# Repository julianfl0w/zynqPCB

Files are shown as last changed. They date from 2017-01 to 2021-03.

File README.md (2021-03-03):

# zynqPCB
An 8-layer board built upon Xilinx Zynq Chip. Includes sound output, HDMI, DDR3, USB Host, USB Device, a handful of sensors, and Arduino Uno style header for screen connection. See schematic in this repo "schematic.pdf"
  
## OPEN TO COLLABORATION!!

# Kicad Project
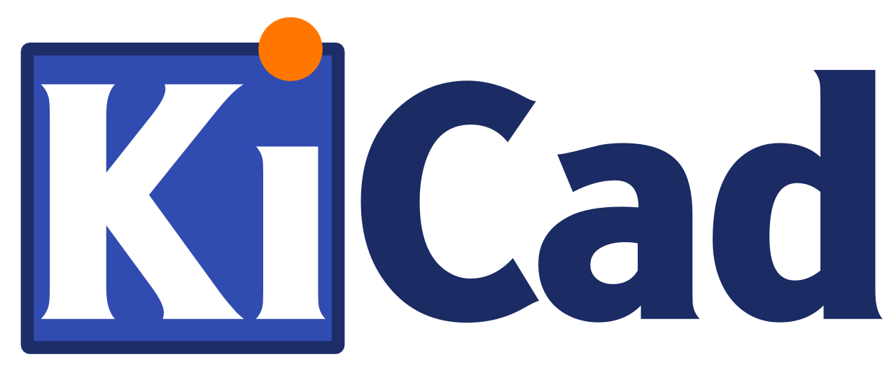
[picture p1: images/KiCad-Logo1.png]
  
https://kicad.org/  

# 3D Render
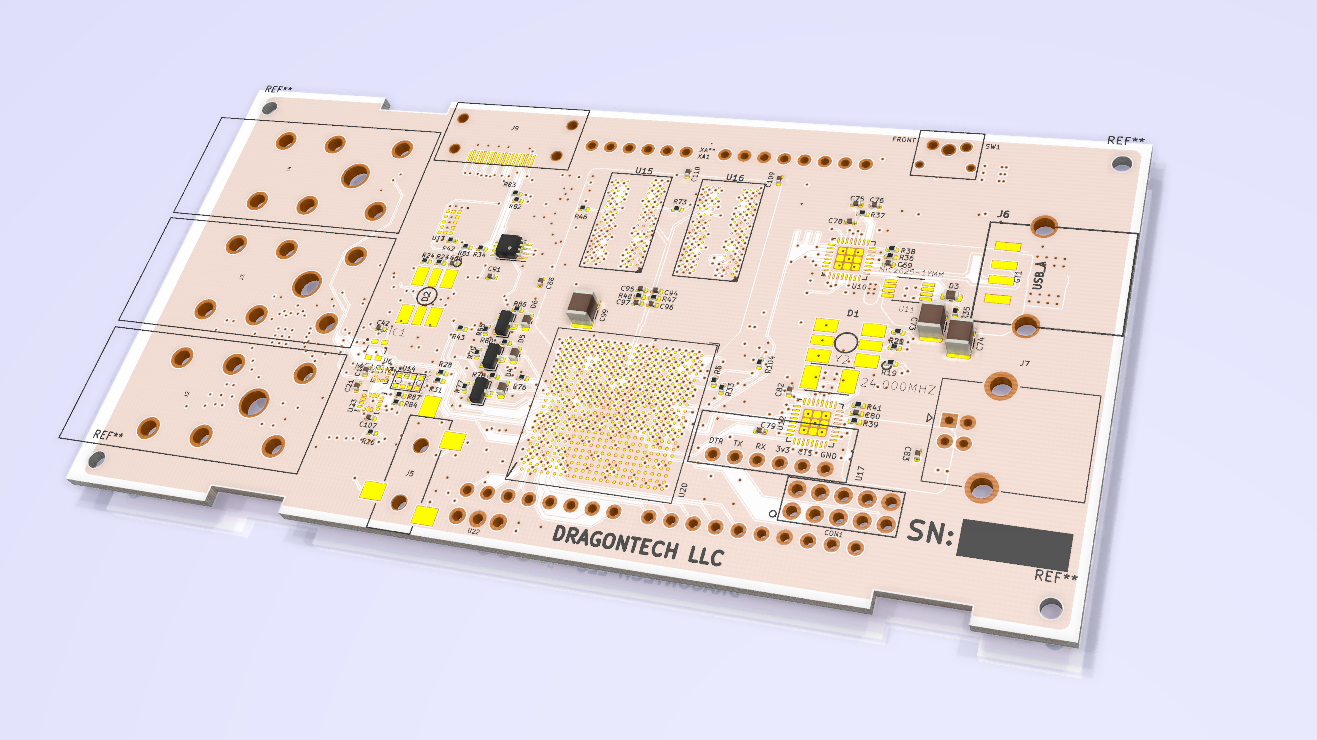
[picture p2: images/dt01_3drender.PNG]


# Layout
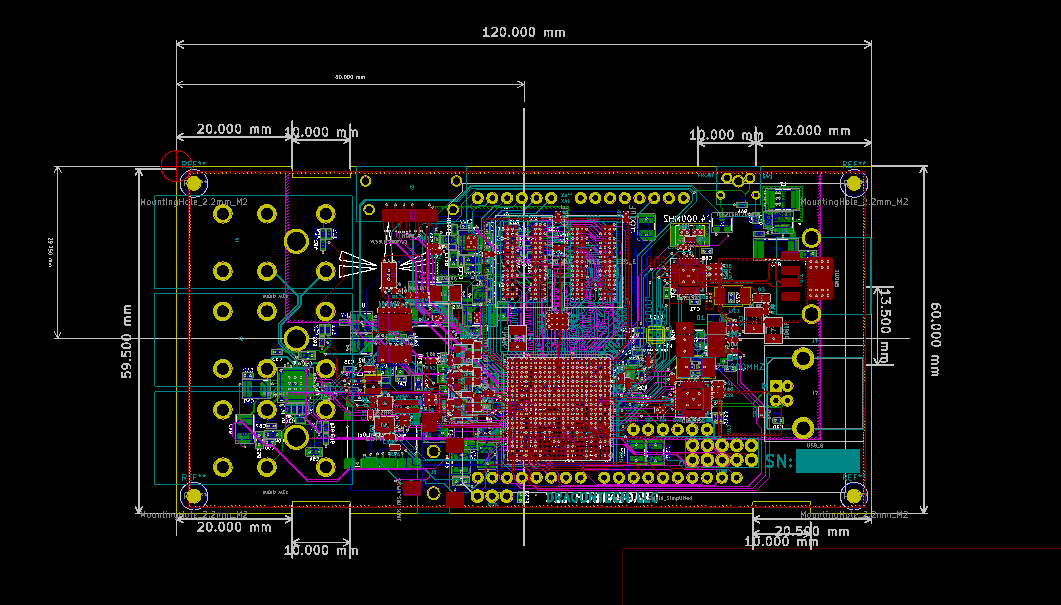
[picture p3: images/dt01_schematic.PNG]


# Block Diagram 
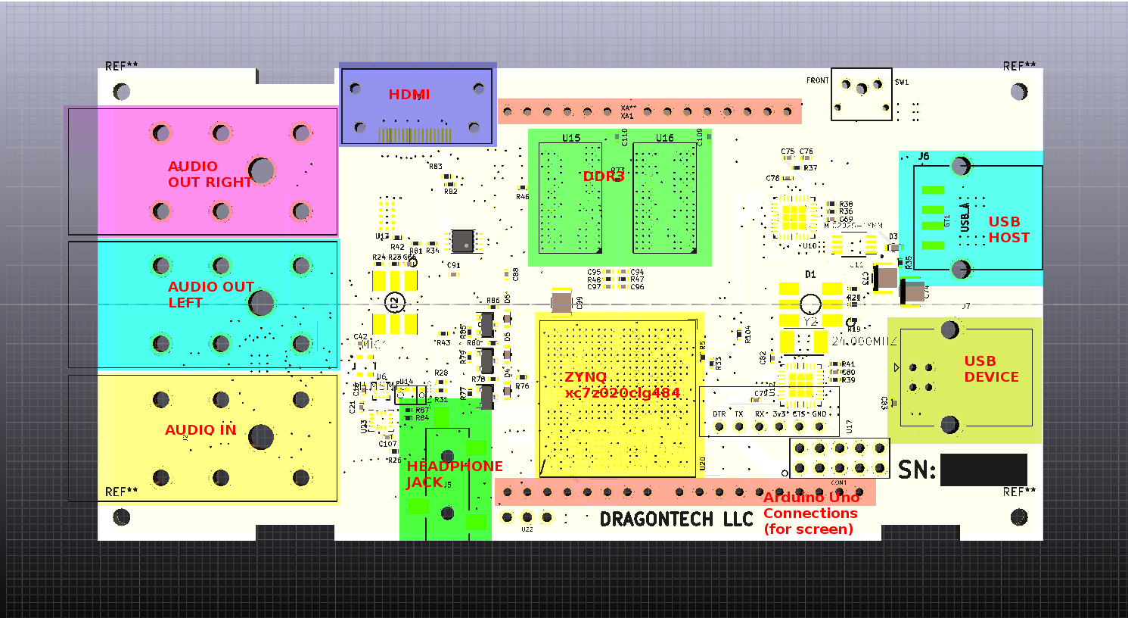
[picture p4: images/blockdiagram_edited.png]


# Manufactured PCB - Top
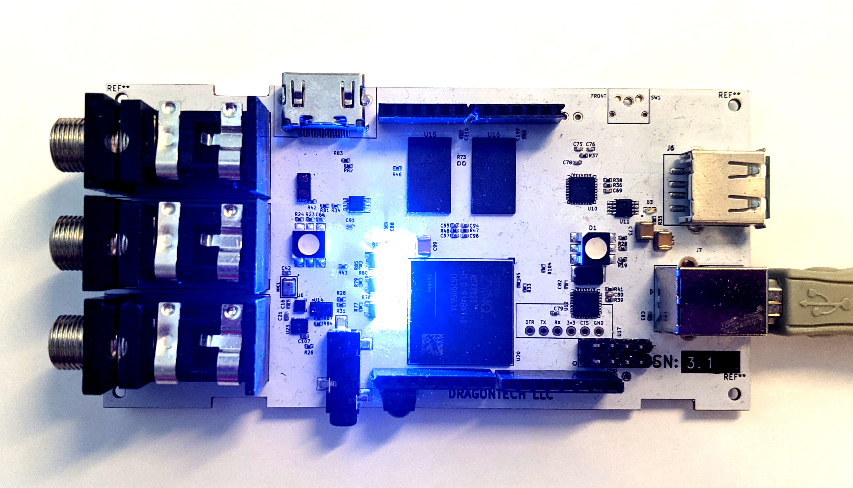
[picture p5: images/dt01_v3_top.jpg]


# Manufactured PCB - Bottom
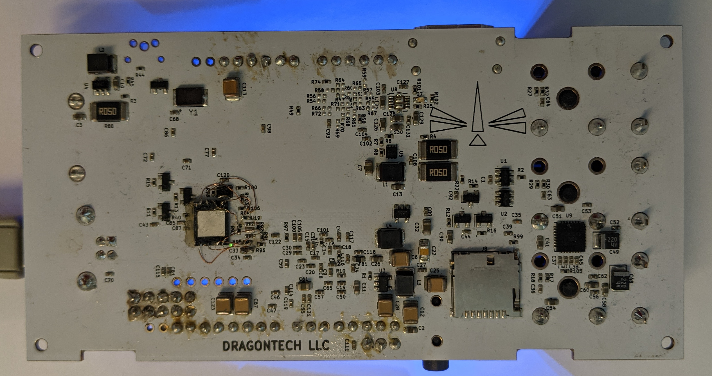
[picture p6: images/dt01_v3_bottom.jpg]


# Introduction  
Hi friends! This is the current status of my 4-year project to make an FPGA-accelerated audio+video synthesizer. I am currently taking a hiatus from this project, and have decided to make the entire PCB design available on Github! Quite a bit of work has been put into this project. The difficult tasks of part selection and routing have been taken care of. I am still testing the functionality of the board. Only one PCB problem has been found: the SPI Flash for Zynq Boot was the wrong footprint! This problem has since been fixed.  

I believe that together we can make this a formidable tool in the open hardware community.  

The following software projects need to be undertaken before this project is usable by the general public:
1. Development of Boot firmware for the SPI flash which loads the linux kernel from the SD card
2. Development of a basic shell block diagram in Vivado  
  
If you embark on one of these projects, please share your code here so other engineers don't have to reproduce your work :)  

# IMPORTANT: Make sure to clone the following into the same directory:
https://github.com/julianfl0w/footprints.pretty  
https://github.com/julianfl0w/lib  
  
## I make no guarantees as to device funtionality. Please review the board carefully before production. 
Specific hardware (from BOM)  
xc7z020clg484 (Zynq Chip)  
VL53L1CXV0FY/1 (rangefinder)  

# Interfaces:  
1. JTAG interface : Functional!
2. SPI Flash : Untested
3. VL53L1CXV0FY Rangefinder : Untested  
4. APDS-9960 Rangefinder : Untested 
5. LIS2HH12 Accelerometer : Untested 
6. LSM6DSLTR IMU  : Untested 
7. HDMI Out : Untested
8. USB Host : Untested
9. USB Device : Untested
10. DDR3 PS Memory : Untested
11. TLV320 Audio Codec : Untested
12. MicroSD card : Untested

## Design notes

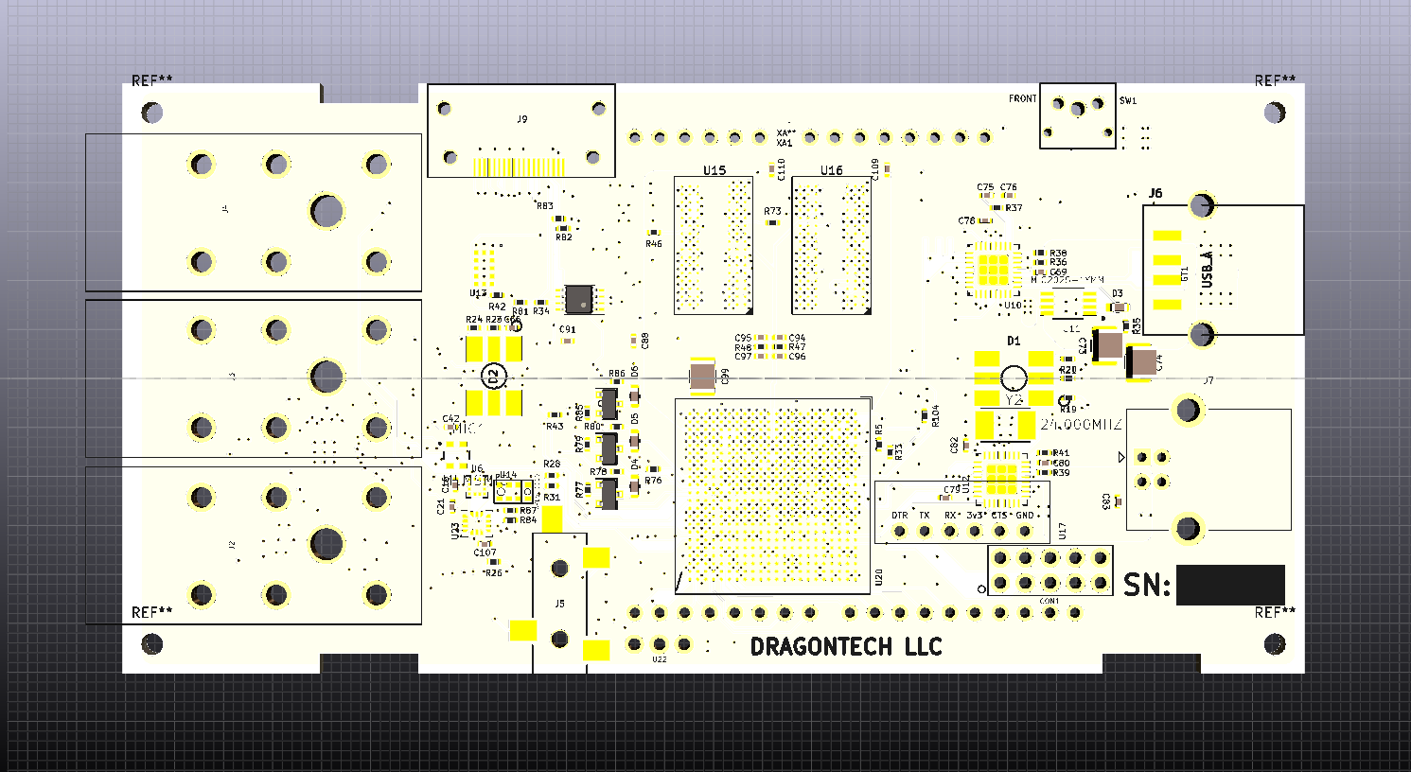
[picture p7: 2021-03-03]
images/blockdiagram.PNG

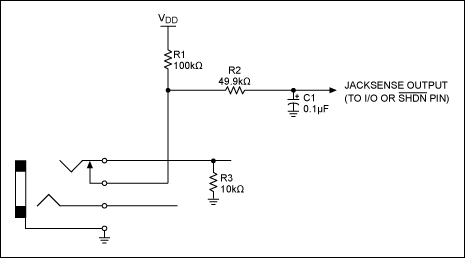
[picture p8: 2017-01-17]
docs/jackdetection.gif

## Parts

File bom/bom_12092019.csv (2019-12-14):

Refs | Value | Footprint | Quantity | MFR | MPN | SPR | SPN
Y1;Y2 | 24.000MHZ | ABM3-12.000MHZ-B2-T:XTAL500X320X130N | 2 | Abracon LLC | ABM3-24.000MHZ-D2Y-T | DigiKey | 535-10643-2-ND
C106;C105;C98;C93;C109;C110;C120;C111 | .01uF | Capacitor_SMD:C_0402_1005Metric | 8 | Murata | GRM155R71H103KA88J | Digikey | 490-6351-1-ND
C68;C70;C71;C77;C72;C79;C81;C82;C86;C131;C97;C96;C95;C94;C88;C16;C107;C36;C64;C63;C52;C56;C53;C62;C39 | .1uF | Capacitor_SMD:C_0402_1005Metric | 25 | Murata | GRM188R71C104KA01D | Digikey | 490-1532-1-ND
C65;C78;C87;C34;C18;C17;C15;C14;C29;C30;C31;C23;C8;C4;C1;C108;C116;C117;C118;C119;C104;C103;C102;C101;C121;C55;C50;C47;C46 | .47uF | Capacitor_SMD:C_0402_1005Metric | 29 | Murata | GRM188R71C474KA88D | Digikey | 490-3295-1-ND
C76;C75;C85;C84 | 18pF | Capacitor_SMD:C_0402_1005Metric | 4 | Murata | GCM1555C1H180JA16D | Digikey | 490-12650-1-ND
C91;C92;C37;C40;C38;C45;C43;C44 | 1uF | Capacitor_SMD:C_0402_1005Metric | 8 | Murata | GRM188R71C105KE15D | Digikey | 490-10734-1-ND
C69;C80;C35 | 2.2uF | Capacitor_SMD:C_0402_1005Metric | 3 | Murata | GRM155R61A225KE95D | Digikey | 490-10451-1-ND
C66;C83;C20;C19;C24;C27;C9;C5;C114;C115;C100;C127;C122;C89;C21;C42;C59;C57 | 4.7uF | Capacitor_SMD:C_0402_1005Metric | 18 | Murata | GRM21BR61A475KA73L | Digikey | 490-9750-1-ND
C3;C13;C2;C10;C11;C26;C33;C126;C125;C130;C129;C128;C90;C54;C58;C51;C41;C60 | 10uF | Capacitor_SMD:C_0603_1608Metric | 18 | Murata | GRM21BR61A106KE19L | Digikey | 490-1709-1-ND
FB1 | 120R, 100 MHz, size 0603 | Capacitor_SMD:C_0603_1608Metric | 1 | Murata Electronics | BLM18AG121SN1D | Digikey | 490-1011-1-ND
D3;D5;D4;D6;D7 | BLUE LED | Capacitor_SMD:C_0603_1608Metric | 5 | Vishay Semiconductors | VLMB1300-GS08 | Digikey | VLMB1300-GS08CT-ND
C32;C7;C61 | 47uF | Capacitor_SMD:C_0805_2012Metric | 3 | Murata Manufacturing Co Ltd | GRM32ER70J476ME20L | Digikey | 490-6542-1-ND
C22 | 330uF | Capacitor_SMD:C_1206_3216Metric | 1 | AVX Corporation | F950G337MAAAQ2 | Digikey | 478-8378-1-ND
C67;C73;C74;C28;C25;C12;C6;C99;C123 | 100uF | Capacitor_SMD:C_1210_3225Metric | 9 | TAIYO YUDEN | JMK325ABJ107MM-P | Digikey | 587-4313-1-ND
C113 | 47uF | Capacitor_SMD:C_1210_3225Metric | 1 | Murata Manufacturing Co Ltd | GRM32ER70J476ME20L | Digikey | 490-6542-1-ND
L2;L3;L4;L1 | 2.2uH | Capacitor_SMD:C_1812_4532Metric | 4 | Murata | LQH43PN2R2M26L | Digikey | 490-12049-1-ND
C49;C48 | 220uF Tant. | Capacitor_Tantalum_SMD:CP_EIA-3528-12_Kemet-T | 2 | AVX Corporation | F930G227KBA | Digikey | 478-8139-1-ND
J7 | USB_B | Connector_USB:USB_B_OST_USB-B1HSxx_Horizontal | 1 | On Shore Technology | USB-B1HSW6 | Digikey | ED2982-ND
J9 | HDMI_A | DFTcustom:10029449-111RLF | 1 | Amphenol ICC | 10029449-111RLF | Digikey | 609-4614-1-ND
J8 | Micro_SD_Card_Det | DFTcustom:AMPHENOL-114-00841-68 | 1 | Amphenol ICC | 114-00841-68 | Digikey | 114-00841-68-1-ND
U14 | APDS-9960 | DFTcustom:APDS_9960 | 1 | Broadcom Limited | APDS-9960 | Digikey | 516-3480-1-ND
XA1 | Arduino_Uno_Shield_Simplified | DFTcustom:Arduino_Uno_Shield_Simplified | 1 | DNS | - | - | -
U20 | xc7z020clg484 | DFTcustom:BGA-484_19.0x19.0mm_Layout22x22_P0.80mm_dia0.40mm | 1 | Xilinx | XC7Z020-1CLG484C | Digikey | 122-1850-ND
U15;U16 | MT41K256M16HA-125_E | DFTcustom:FBGA-96-DDR3-SDRAM | 2 | Micron | MT41K256M16TW-107 | Digikey | 557-2006-6-ND
U17 | FTDITypeUART | DFTcustom:FTDI_CONN | 1 | DNS | - | - | -
U22 | TSOP344 | DFTcustom:JUMPER_3PIN | 1 | Vishay Semiconductor | TSOP34438 | Digikey | TSOP34438-ND
U13 | VL53L1CXV0FY/1 | DFTcustom:Optical_LGA12 | 1 | STMicroelectronics | VL53L1CXV0FY/1 | Digikey | 497-17764-2-ND
D1;D2 | LED_RGB | DFTcustom:PLCC6-SM-RGB-LED | 2 | Cree, Inc. | CLP6C-FKB-CM1Q1H1BB7R3R3 | Digikey | CLP6C-FKB-CM1Q1H1BB7R3R3CT-ND
J4;J3;J2 | AUDIO JACK | DFTcustom:RA49C14B | 3 | Switchcraft Conxall | RA49C12B | Digikey | SC2083-ND
J5 | JACK_TRS_4PINS | DFTcustom:SJ-352X-SMT | 1 | CUI Inc. | SJ-3524-SMT-TR | Digikey | CP-3524SJCT-ND
J6 | USB_A | DFTcustom:USB-A-Receptacle-FCI_87583 | 1 | Amphenol ICC | 87583-2010RLF | Digikey | 609-5390-1-ND
MIC1 | MEMSMIC | DFTcustom:WM7121PE | 1 | Cirrus Logic | WM7121PIMSE/RV | Digikey | WM7121PIMSE/RVCT-ND
U19 | S25FL256SAGNFI001 | DFTcustom:WSON-8 | 1 | Cypress | S25FL256SAGNFI001 | Digikey | 1274-1005-ND
CON1 | AVR-JTAG-10 | DFTcustom:XilinxJTAG | 1 | DNS
GT1 | GNDTIE | DFTcustom:gndtie | 1 | DNS | - | - | -
SW1 | TL6215RF200BDT | DFTcustom:tl6215_right_angle | 1 | E-Switch Inc | TL6215RF200BDT | Digikey | EG5162-ND
U10;U12 | USB3320 | Package_DFN_QFN:QFN-32-1EP_5x5mm_P0.5mm_EP3.1x3.1mm | 2 | Microchip Technology | USB3320C-EZK-TR | Digikey | USB3320C-EZK-CT-NDs
U9 | TLV320AIC3104 | Package_DFN_QFN:QFN-32-1EP_5x5mm_P0.5mm_EP3.65x3.65mm | 1 | Texas Instruments | TLV320AIC3104IRHBR | Digikey | 296-26818-1-ND
U6 | LIS2HH12 | Package_LGA:LGA-12_2x2mm_P0.5mm | 1 | STMicroelectronics | LIS2HH12TR | Digikey | 497-15069-1-ND
U23 | LSM6DS3 | Package_LGA:LGA-14_3x2.5mm_P0.5mm_LayoutBorder3x4y | 1 | STMicroelectronics | LSM6DS3TR | Digikey | 497-15383-1-ND
U21 | PCA9306 | Package_SO:SSOP-8_2.95x2.8mm_P0.65mm | 1 | Texas Instruments | PCA9306DCTR | Digikey | 296-18509-2-ND
U8 | TPS51200DRCR | Package_SON:VSON-10-1EP_3x3mm_P0.5mm_EP1.65x2.4mm_ThermalVias | 1 | Texas Instruments | TPS51200DRCR | Digikey | 296-26978-1-ND
U5 | TLV62080DSGx | Package_SON:WSON-8-1EP_2x2mm_P0.5mm_EP0.9x1.6mm | 1 | Texas Instruments | TLV62080DSGR | Digikey | 296-39270-6-ND
Q9;Q8;Q10;Q7;Q5;Q3;Q1;Q6;Q4;Q2 | IRLML2502 | Package_TO_SOT_SMD:SOT-23 | 10 | Infineon Technologies AG | IRLML2502TRPBF | Digikey | IRLML2502PBFCT-ND
U3 | SC189 - 1.0V | Package_TO_SOT_SMD:SOT-23-5 | 1 | Semtech Corporation | SC189ASKTRT | Digikey | SC189ASKCT-ND
U7 | SC189 - 1.8V | Package_TO_SOT_SMD:SOT-23-5 | 1 | Semtech Corporation | SC189LSKTRT | Digikey | SC189LSKCT-ND
U4 | SC189 - 3.3V | Package_TO_SOT_SMD:SOT-23-5 | 1 | Semtech Corporation | SC189ZSKTRT | Digikey | SC189ZSKCT-ND
U1;U2 | LM3880 | Package_TO_SOT_SMD:SOT-23-6 | 2 | Texas Instruments | LM3880MF-1AE/NOPB | Digikey | LM3880MF-1AE/NOPBDKR-ND
R19;R20;R15;R13;R11;R22;R23;R16;R14;R12 | 100 | Resistor_SMD:R_0402_1005Metric | 10 | Yageo | RC0402FR-07100RL | Digikey | 311-100LRCT-ND
R1;R2;R3;R4;R5;R34;R81;R101;R27;R29;R17;R28 | 100k | Resistor_SMD:R_0402_1005Metric | 12 | Yageo | RC0402FR-07100KL | Digikey | 311-100KLRTR-ND
R36;R39;R33;R6;R42;R43;R44 | 10k | Resistor_SMD:R_0402_1005Metric | 7 | Yageo | RC0402FR-0710KL | Digikey | 311-10.0KLRTR-ND
R48;R47 | 10k 1% | Resistor_SMD:R_0402_1005Metric | 2 | Yageo | RC0402FR-0710KL | Digikey | 311-10.0KLRCT-ND
R35;R80;R78;R86;R102;R45;R21;R24 | 150 | Resistor_SMD:R_0402_1005Metric | 8 | Yageo | RC0402FR-07150RL | Digikey | 311-150LRTR-ND
R37;R40 | 1M | Resistor_SMD:R_0402_1005Metric | 2 | Yageo | RC0402FR-071ML | Digikey | 311-1.00MLRCT-ND
R79;R77;R85;R105 | 1k | Resistor_SMD:R_0402_1005Metric | 4 | Yageo | RC0402FR-071KL | Digikey | 311-1.00KLRCT-ND
R25;R96;R97;R95;R91;R92;R93;R94;R106 | 20k | Resistor_SMD:R_0402_1005Metric | 9 | Yageo | RT0402BRD0720KL | Digikey | YAG1388CT-ND
R100 | 24.9 1% | Resistor_SMD:R_0402_1005Metric | 1 | Yageo | RC0402FR-0724K9L | Digikey | 311-24.9KLRTR-ND
R7;R49;R46 | 240 1% | Resistor_SMD:R_0402_1005Metric | 3 | Yageo | RC0402FR-07240RL | Digikey | 311-240LRTR-ND
R9;R10;R8;R82;R83;R74;R98;R103;R104 | 4.7k | Resistor_SMD:R_0402_1005Metric | 9 | Yageo | RC0402JR-074K7L | Digikey | 311-4.7KJRCT-ND
R52;R51;R54;R53;R56;R55;R58;R57;R60;R59;R62;R61;R64;R63;R66;R65;R67;R68;R69;R70;R71;R72;R73 | 40.2 1% | Resistor_SMD:R_0402_1005Metric | 23 | Yageo | RC0402FR-0740R2L | Digikey | 311-40.2LRTR-ND
R26;R84;R87 | 47 | Resistor_SMD:R_0402_1005Metric | 3 | Yageo | RC0402JR-0747RL | Digikey | 311-47JRTR-ND
R99 | 47k | Resistor_SMD:R_0402_1005Metric | 1 | Yageo | RC0402FR-0747KL | Digikey | 311-47.0KLRTR-ND
R32;R30;R18;R31 | 49.9k | Resistor_SMD:R_0402_1005Metric | 4 | Yageo | RC0402FR-0749K9L | Digikey | 311-49.9KLRCT-ND
R38;R41 | 8.06k 1% | Resistor_SMD:R_0402_1005Metric | 2 | Yageo | RC0402FR-078K06L | Digikey | 311-8.06KLRTR-ND
R50;R75;R76 | 80.6 1% | Resistor_SMD:R_0402_1005Metric | 3 | Yageo | RC0402FR-0780R6L | Digikey | 311-80.6LRTR-ND
R90;R88;R89 | .05 | Resistor_SMD:R_2512_6332Metric | 3 | Bourns Inc | CRA2512-FZ-R050ELF | Digikey | CRA2512-FZ-R050ELFCT-ND
U11 | MIC2025-1YMM | SOP65P490X110-8N:SOP65P490X110-8N | 1 | Microchip | MIC2025-1YMM-TR | Digikey | MIC2025-1YMM-CT-ND
U18 | ABRACON-ASDMB | XTAL_ASDMB-24.000MHZ-LC-T:XTAL_ASDMB-24.000MHZ-LC-T | 1 | Abracon LLC | ASDMB-24.000MHZ-LC-T | Digikey | 535-11728-1-ND

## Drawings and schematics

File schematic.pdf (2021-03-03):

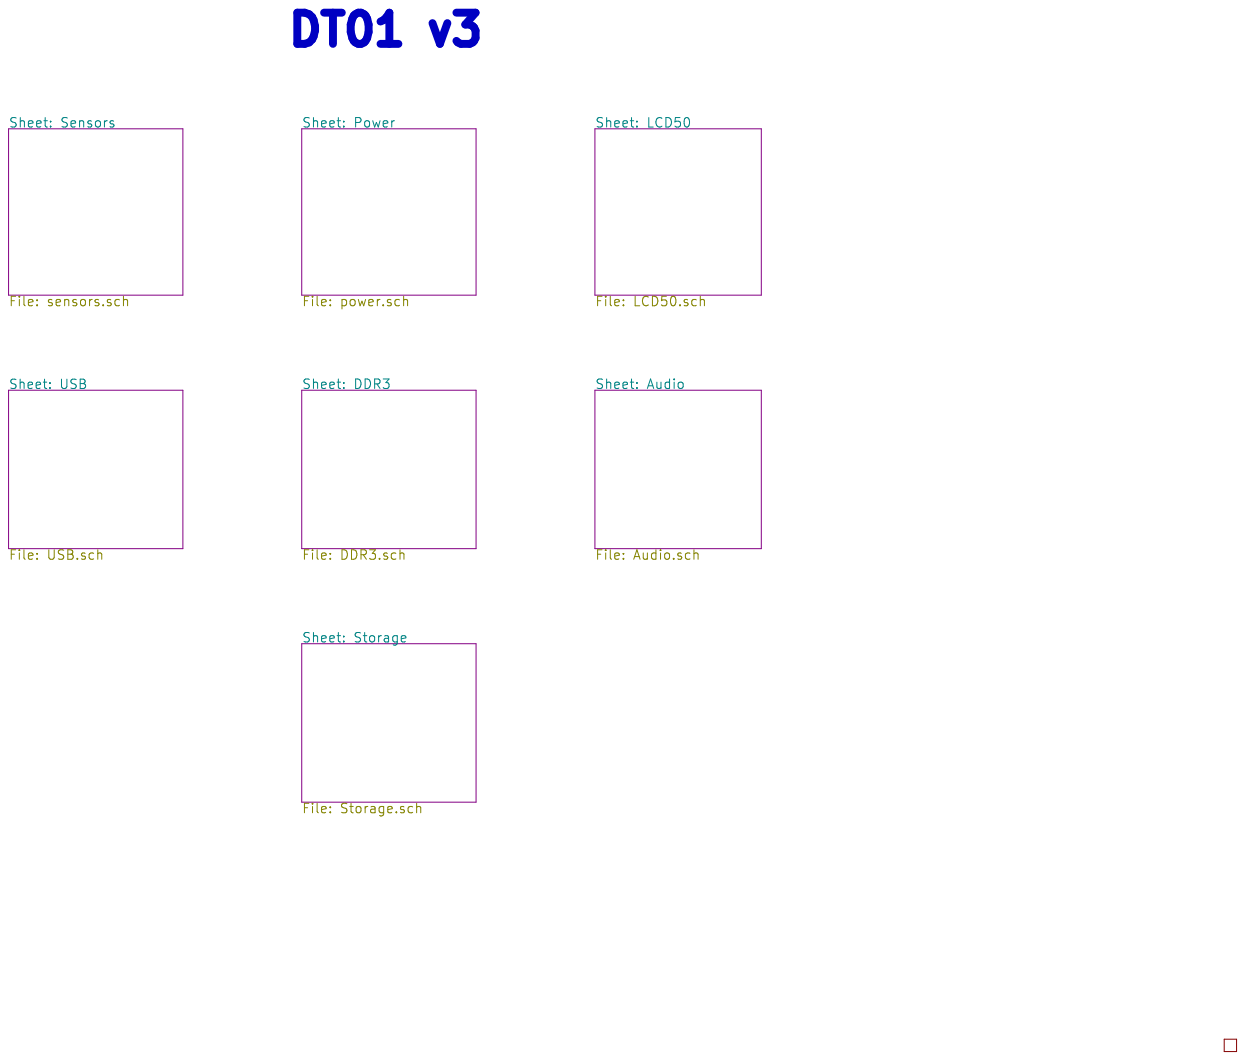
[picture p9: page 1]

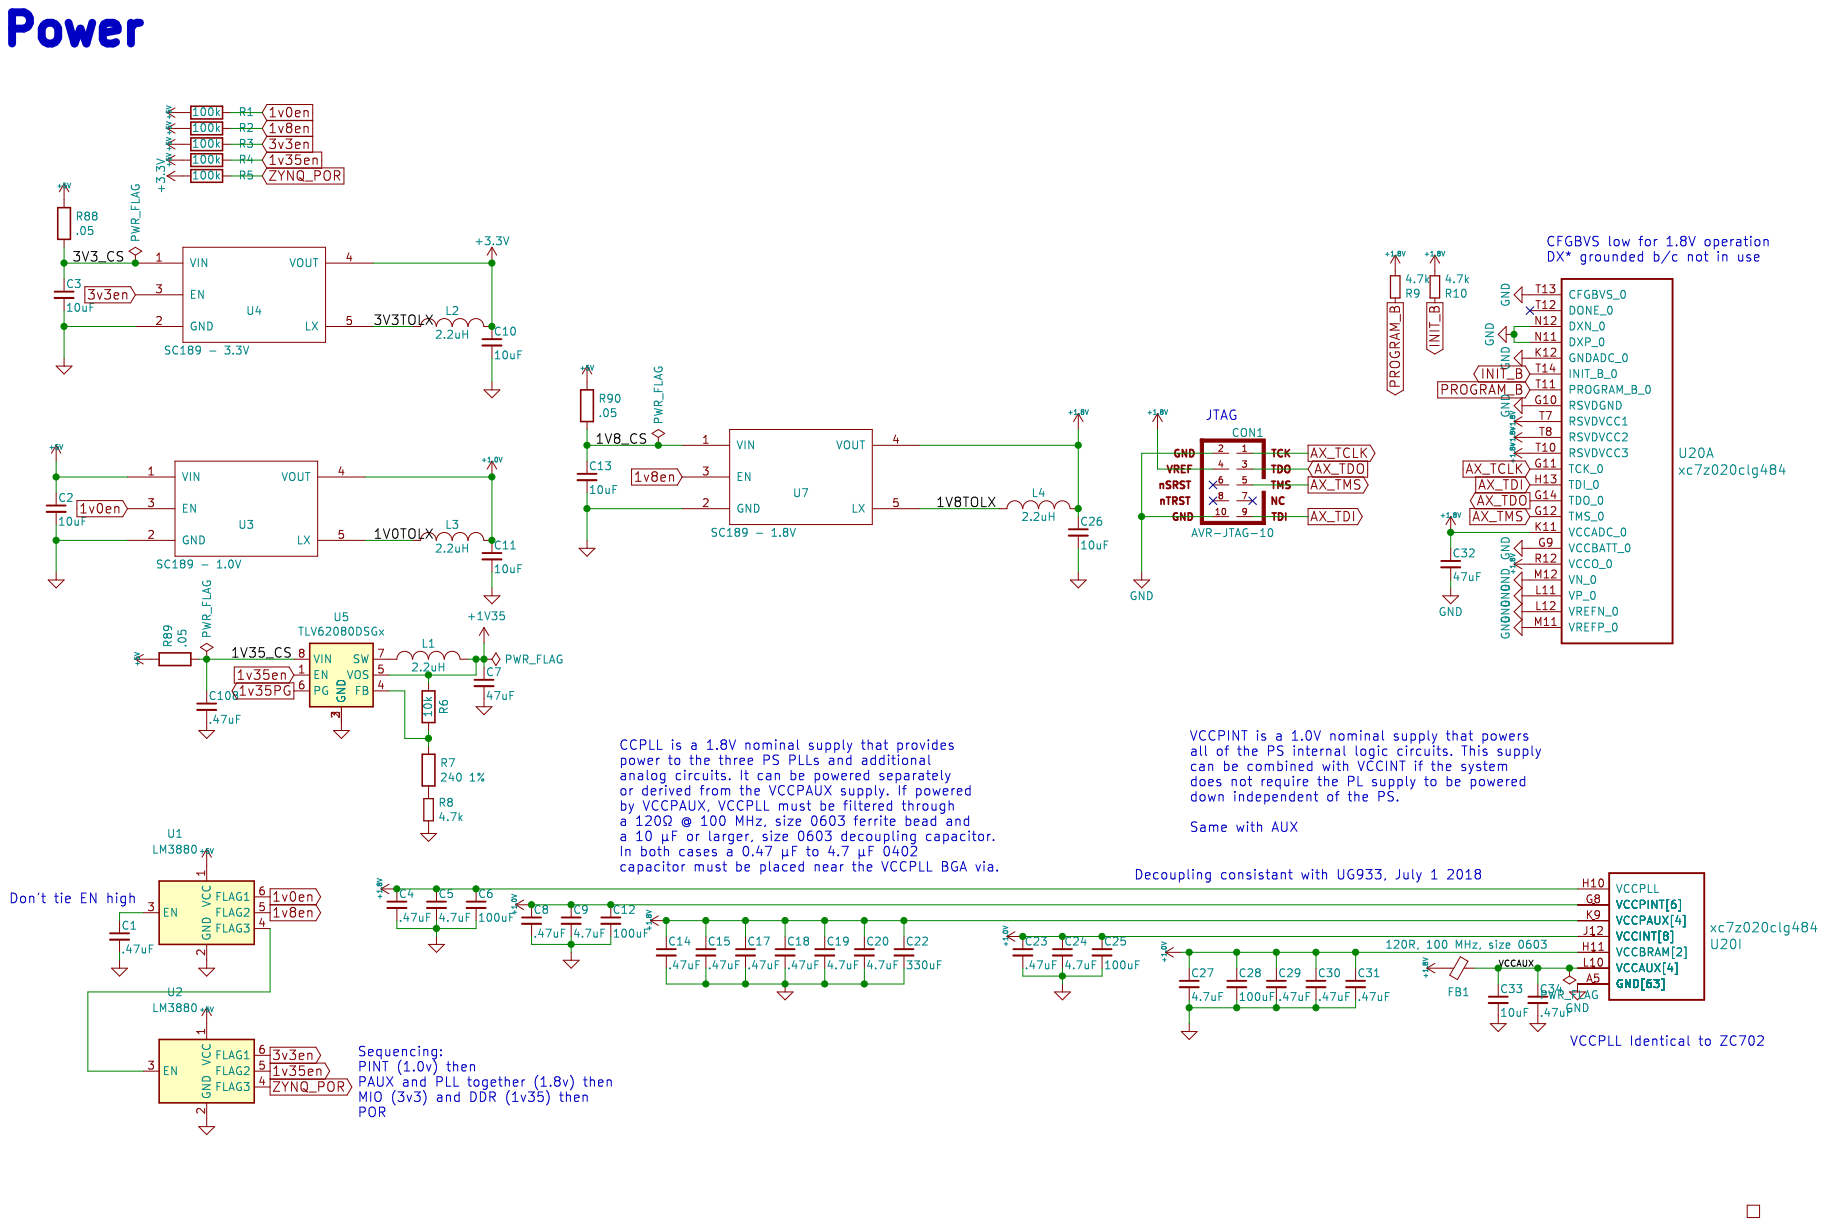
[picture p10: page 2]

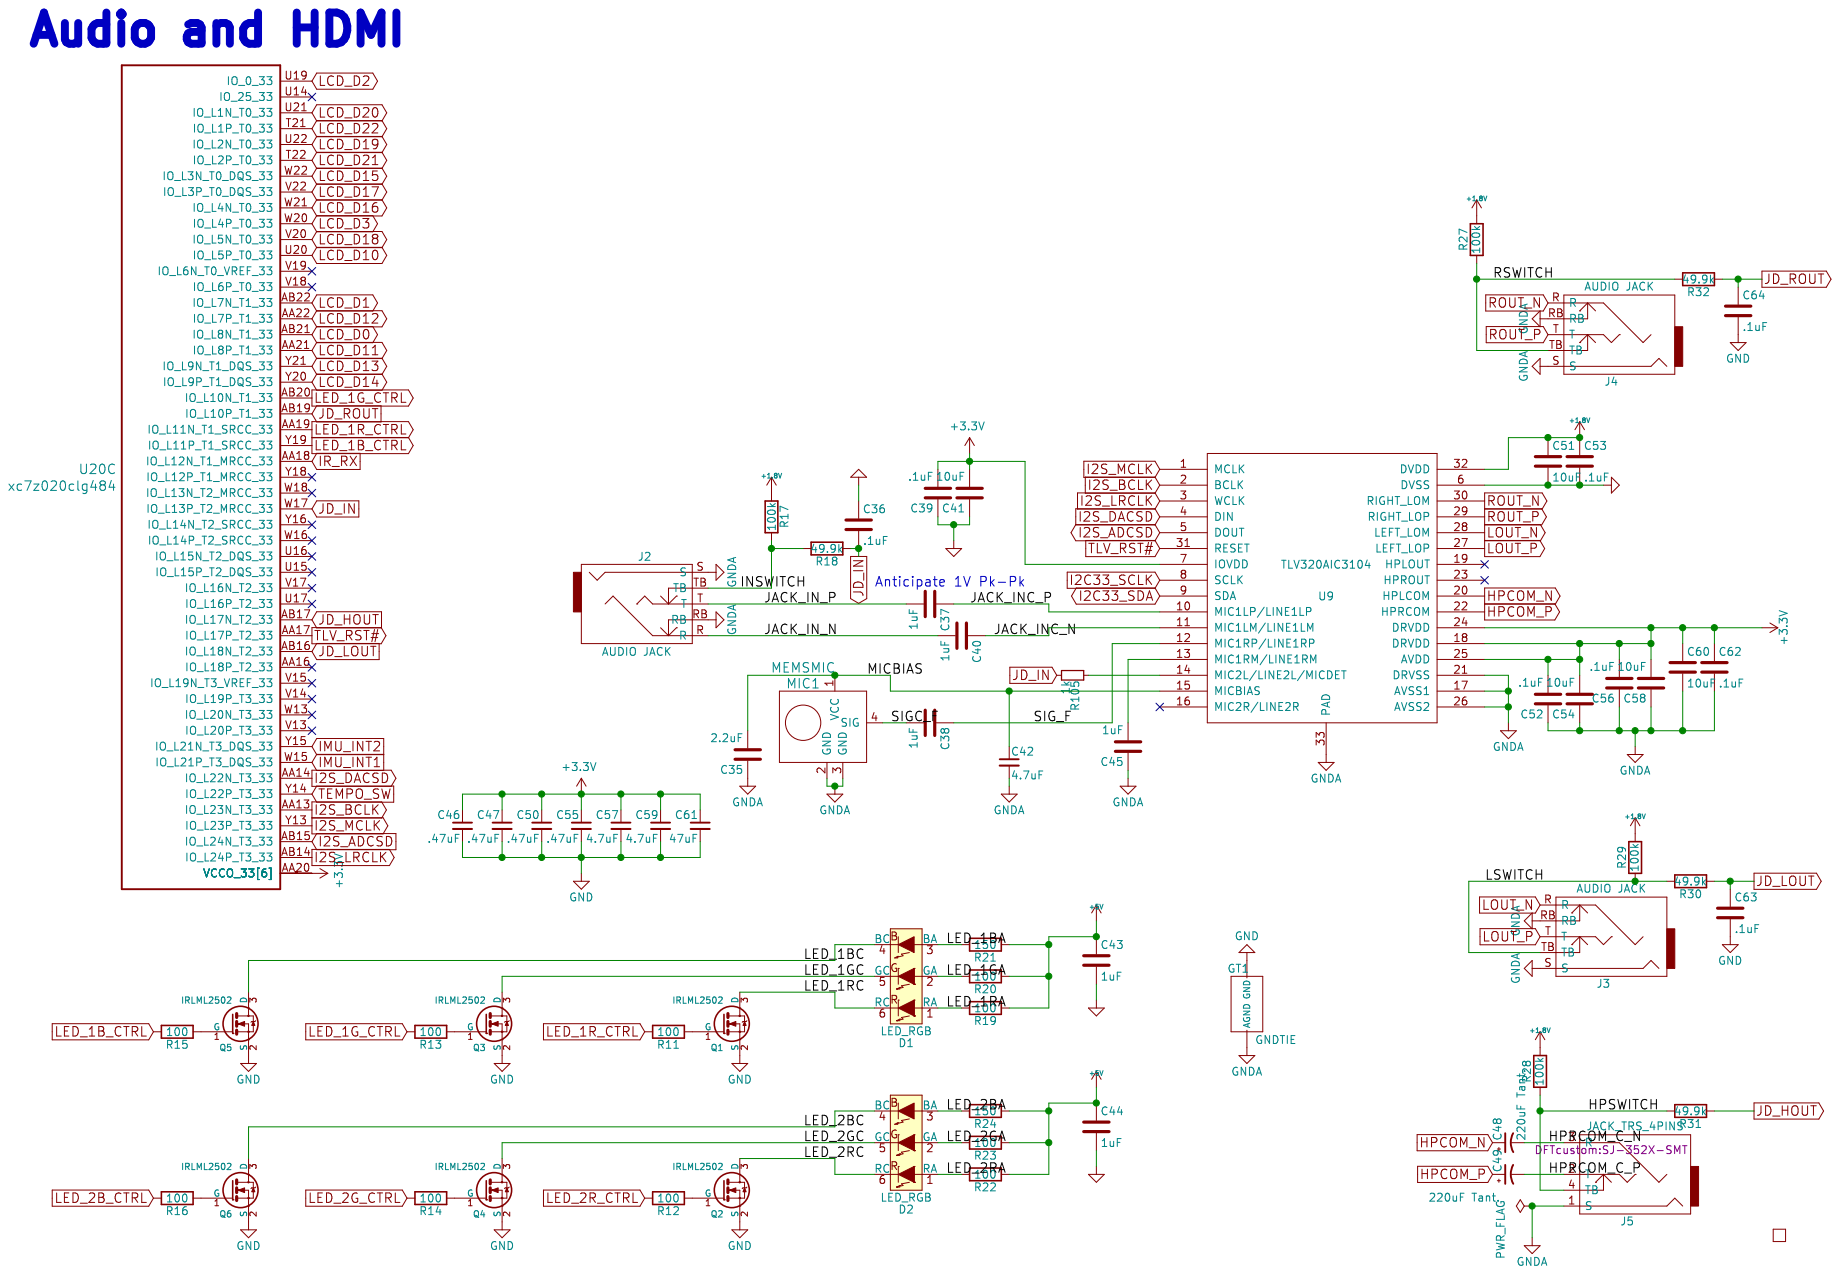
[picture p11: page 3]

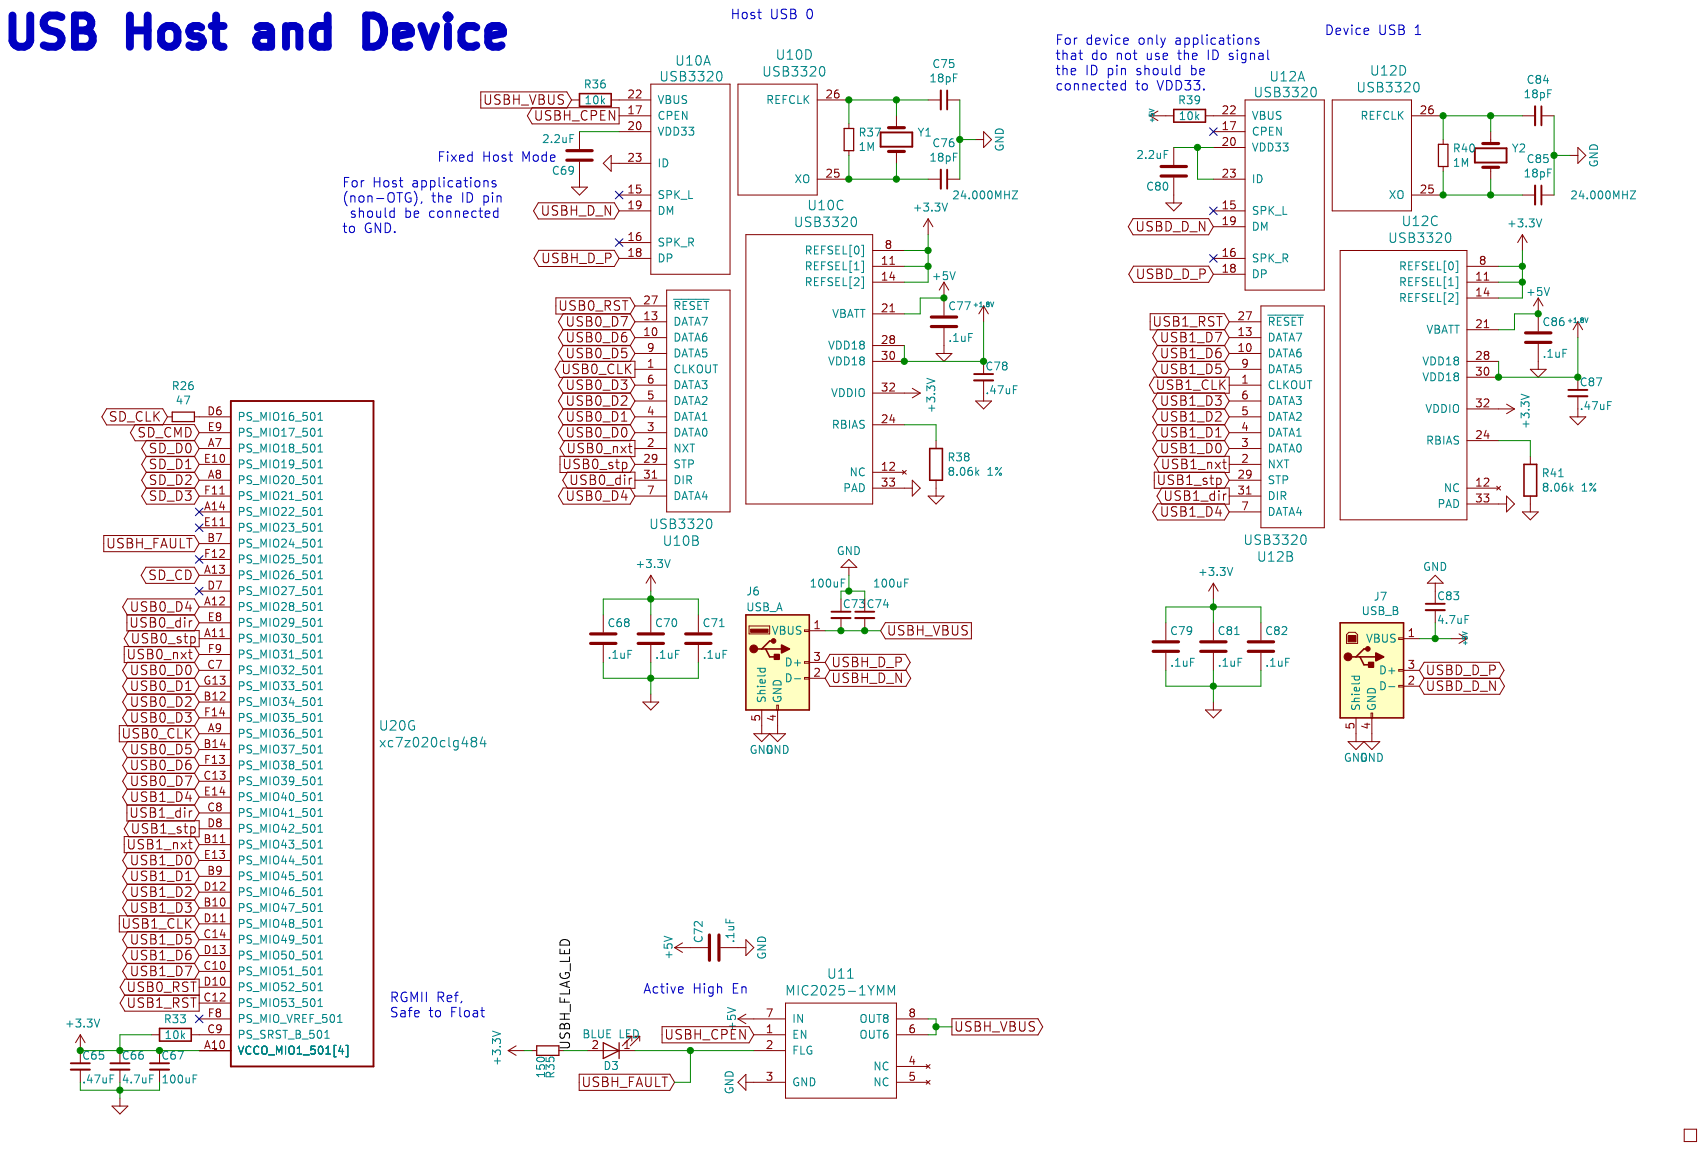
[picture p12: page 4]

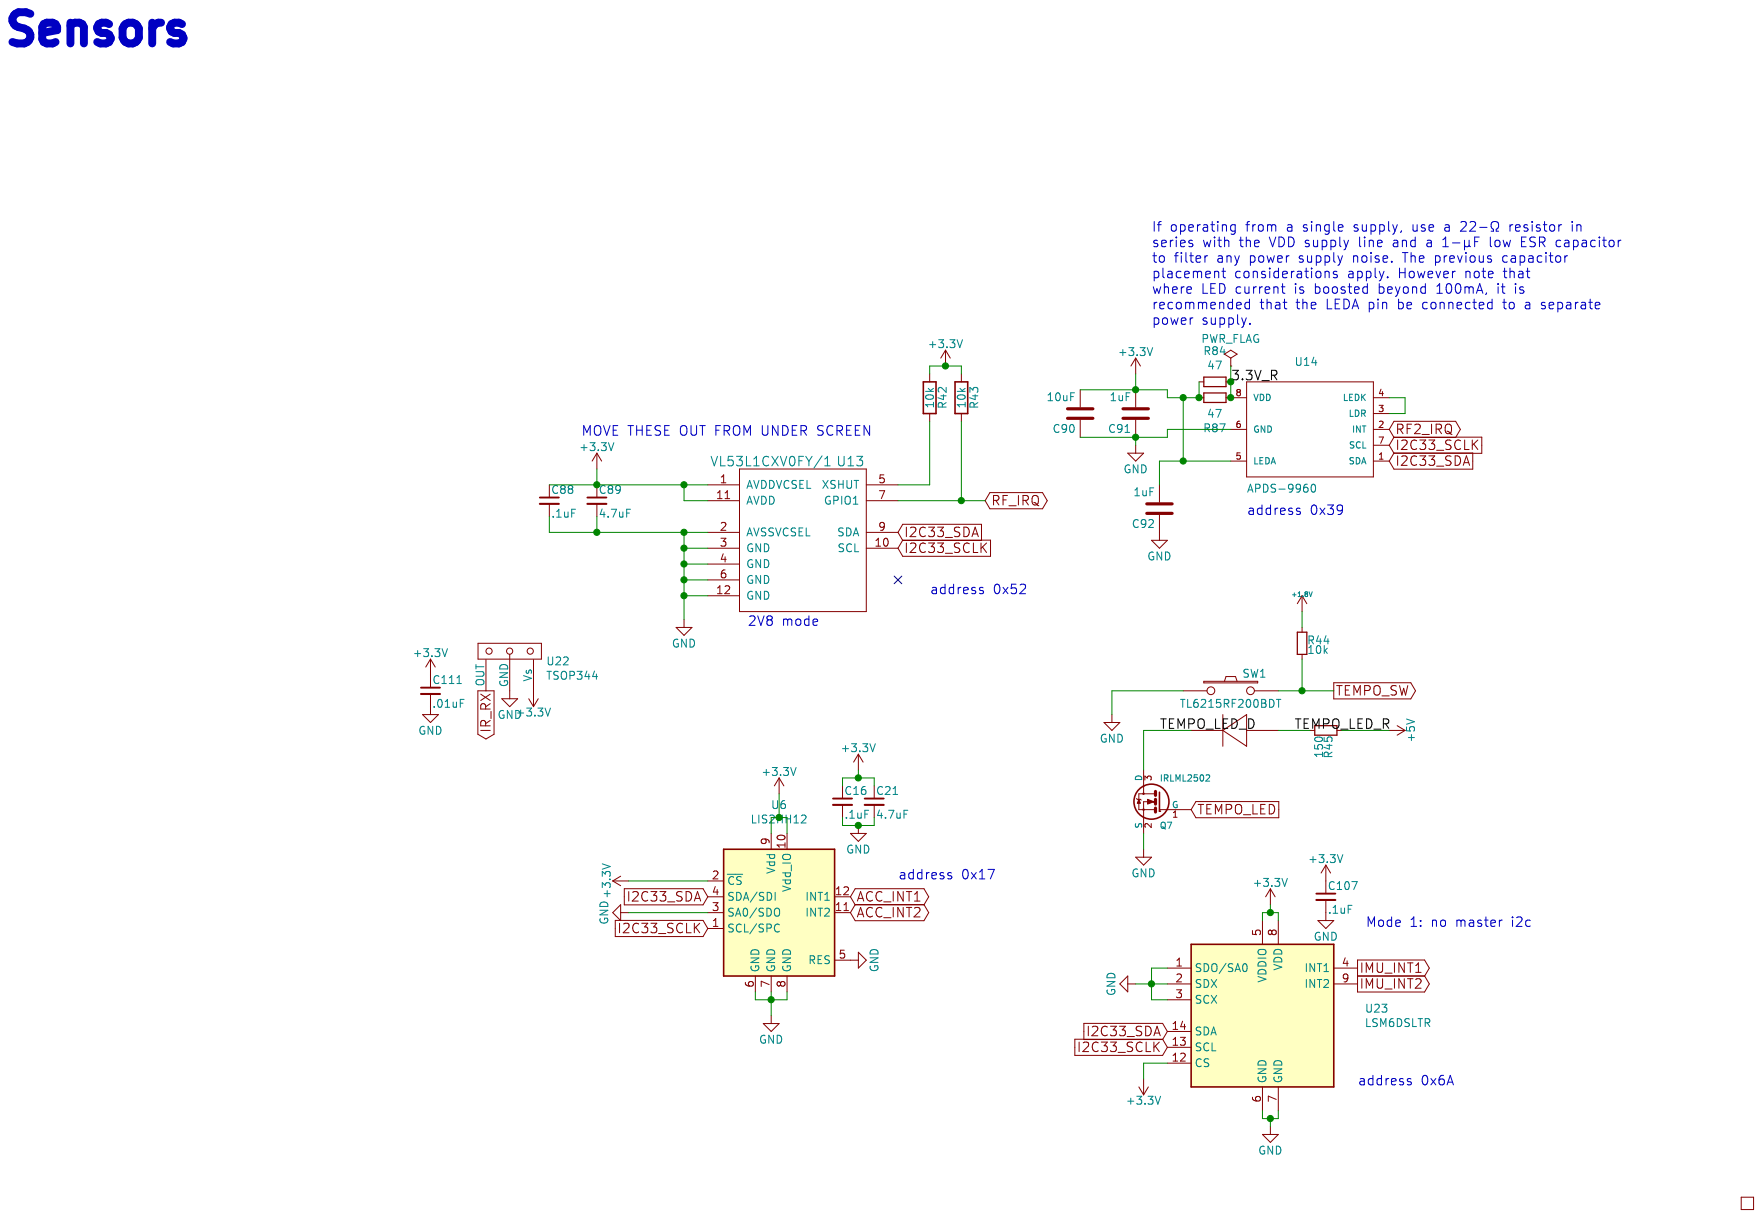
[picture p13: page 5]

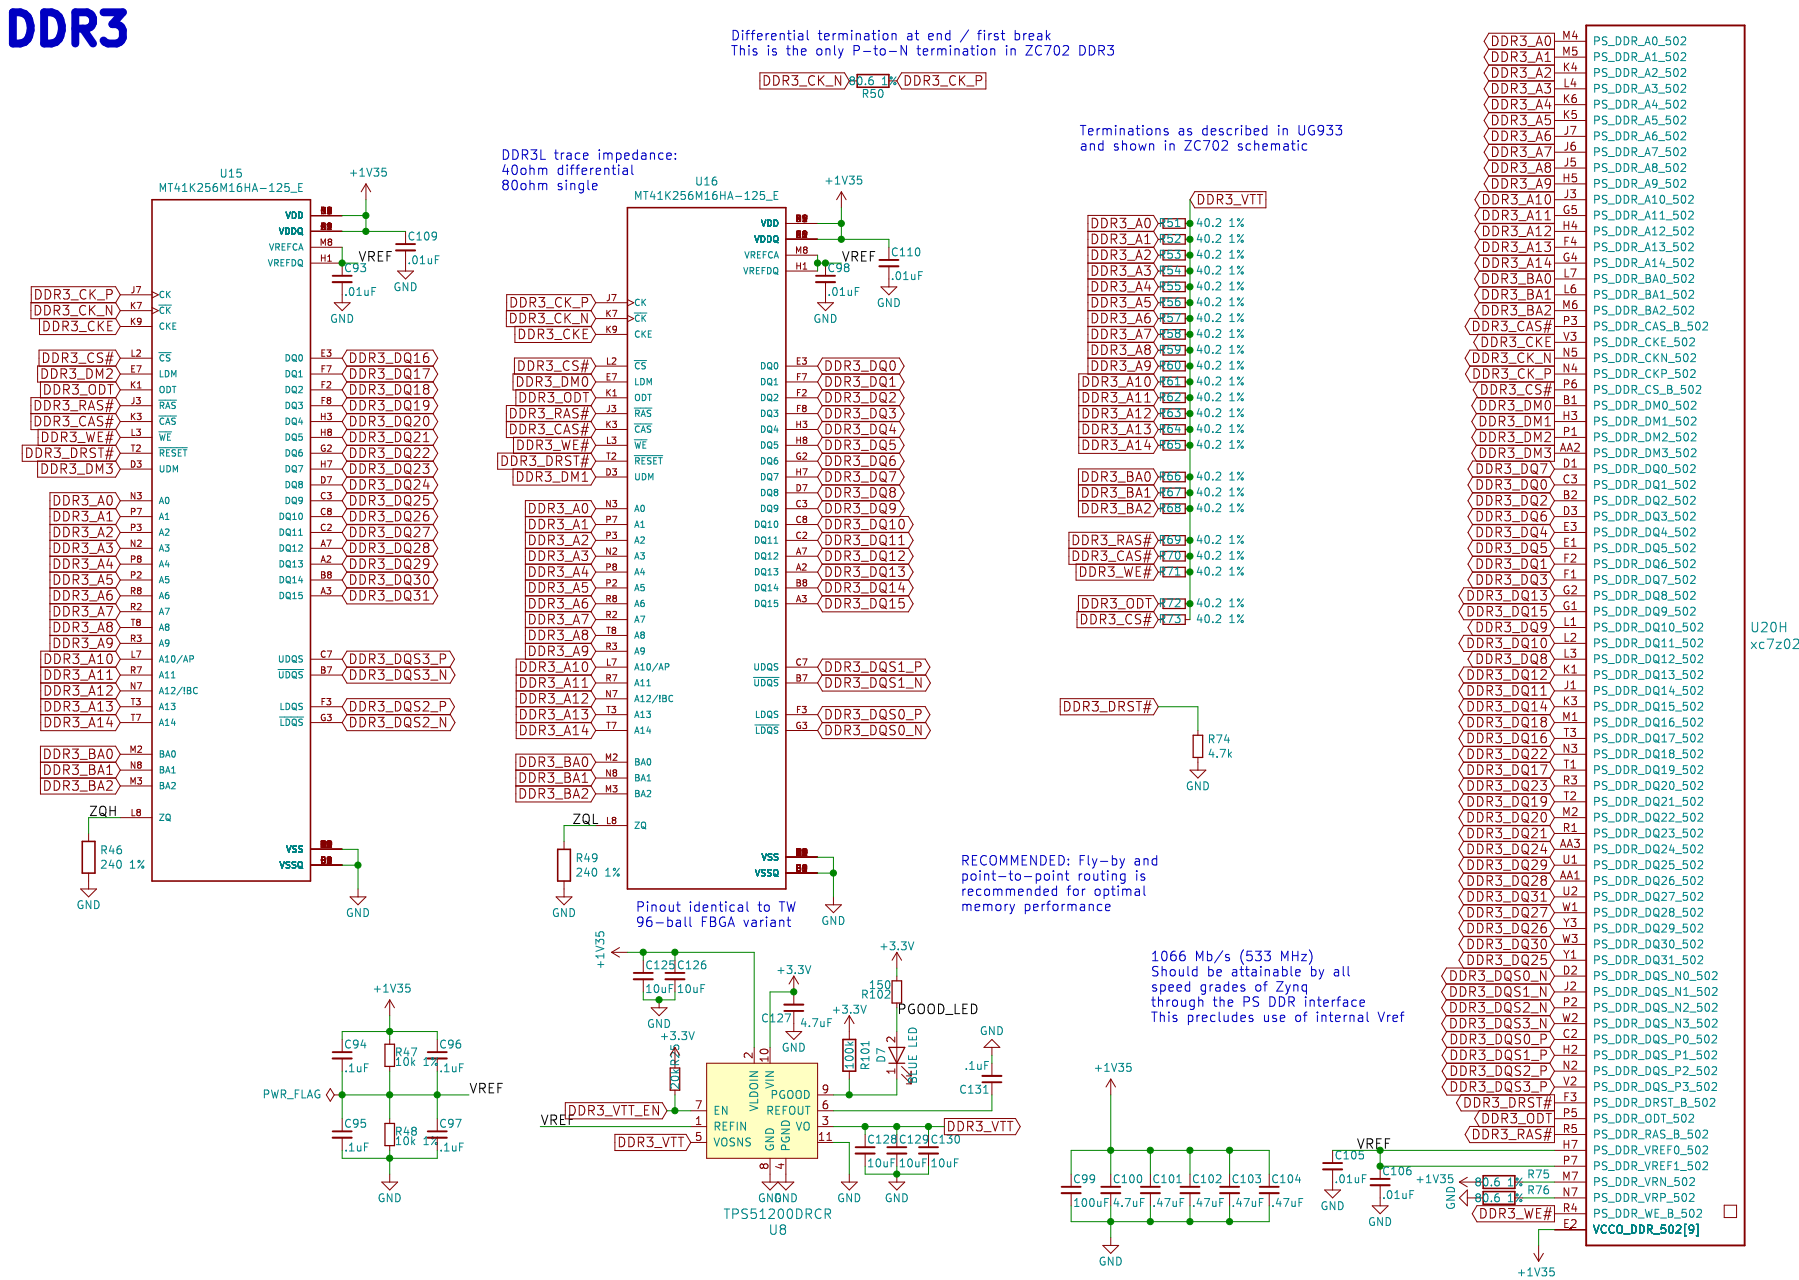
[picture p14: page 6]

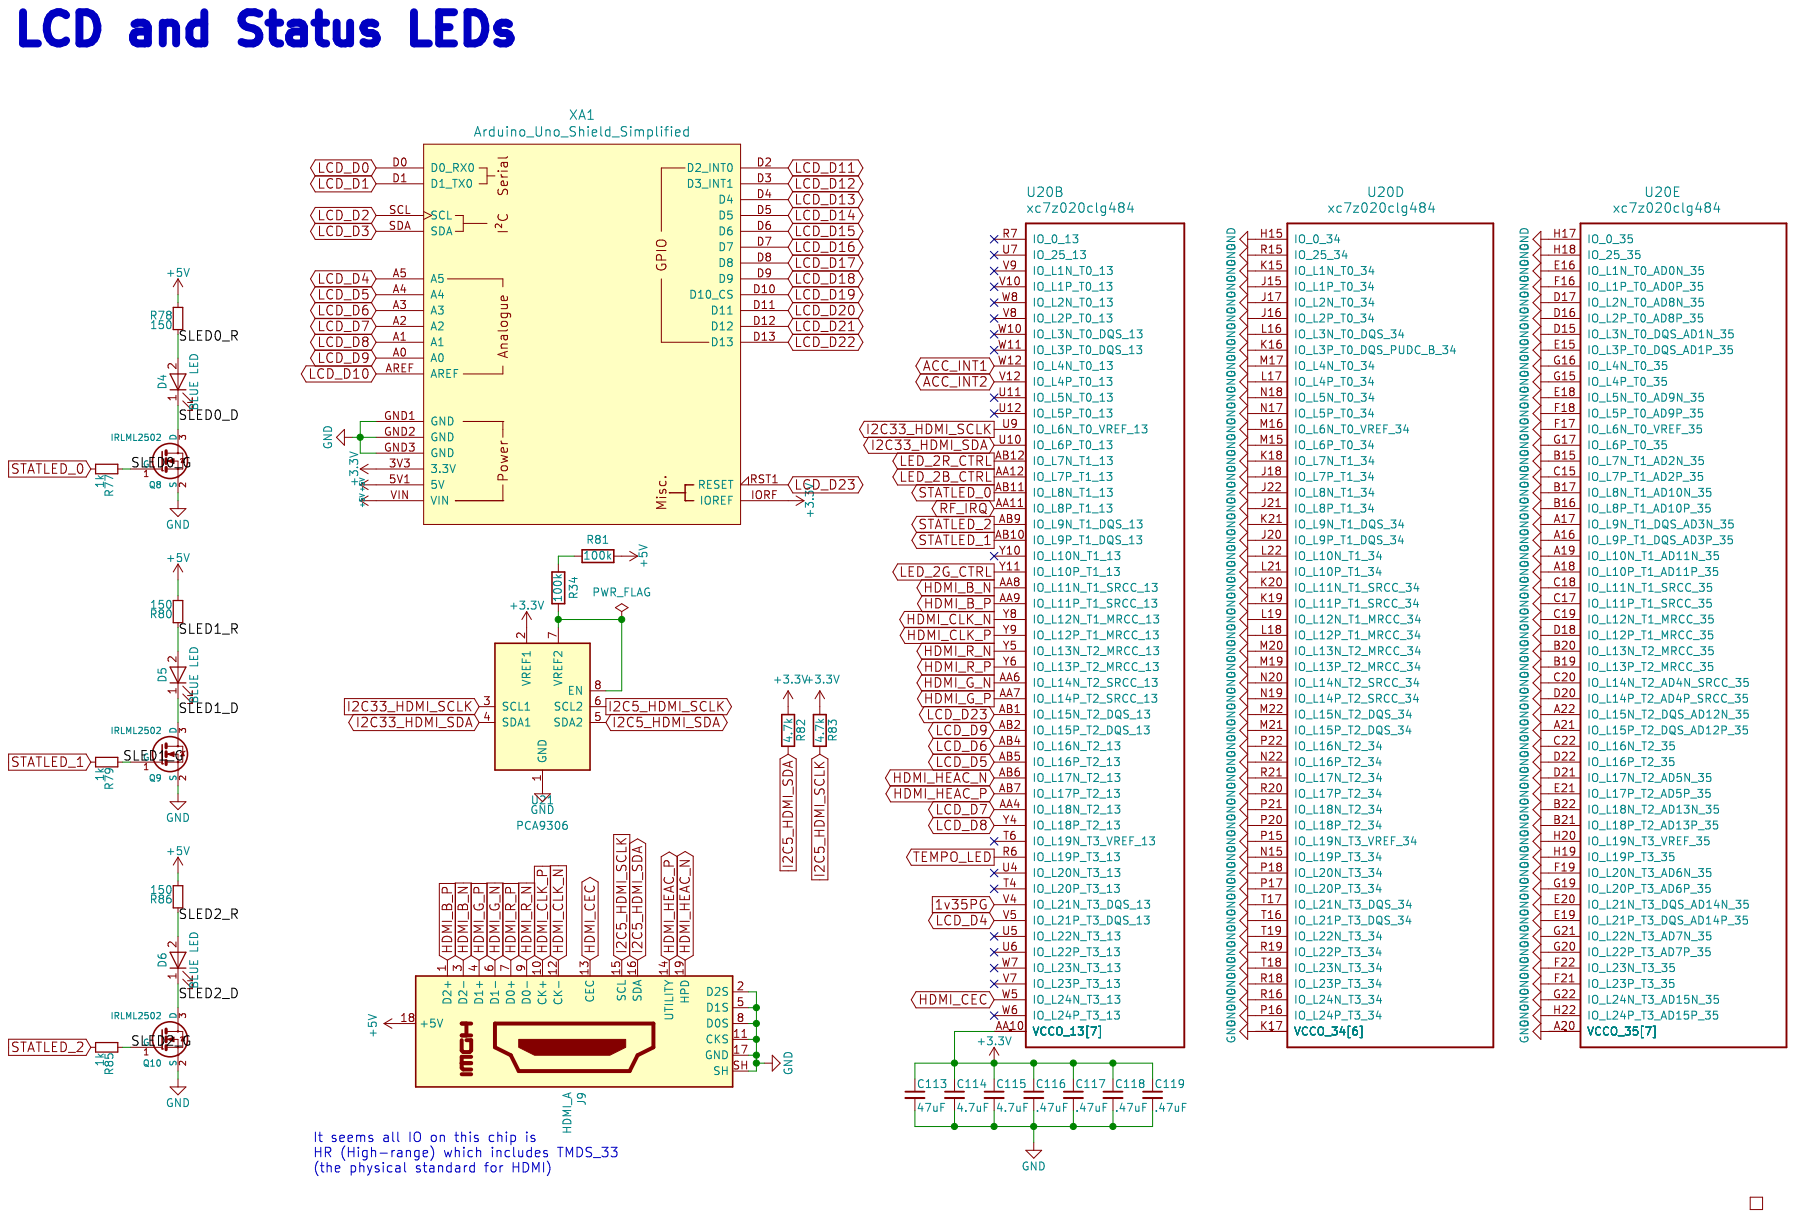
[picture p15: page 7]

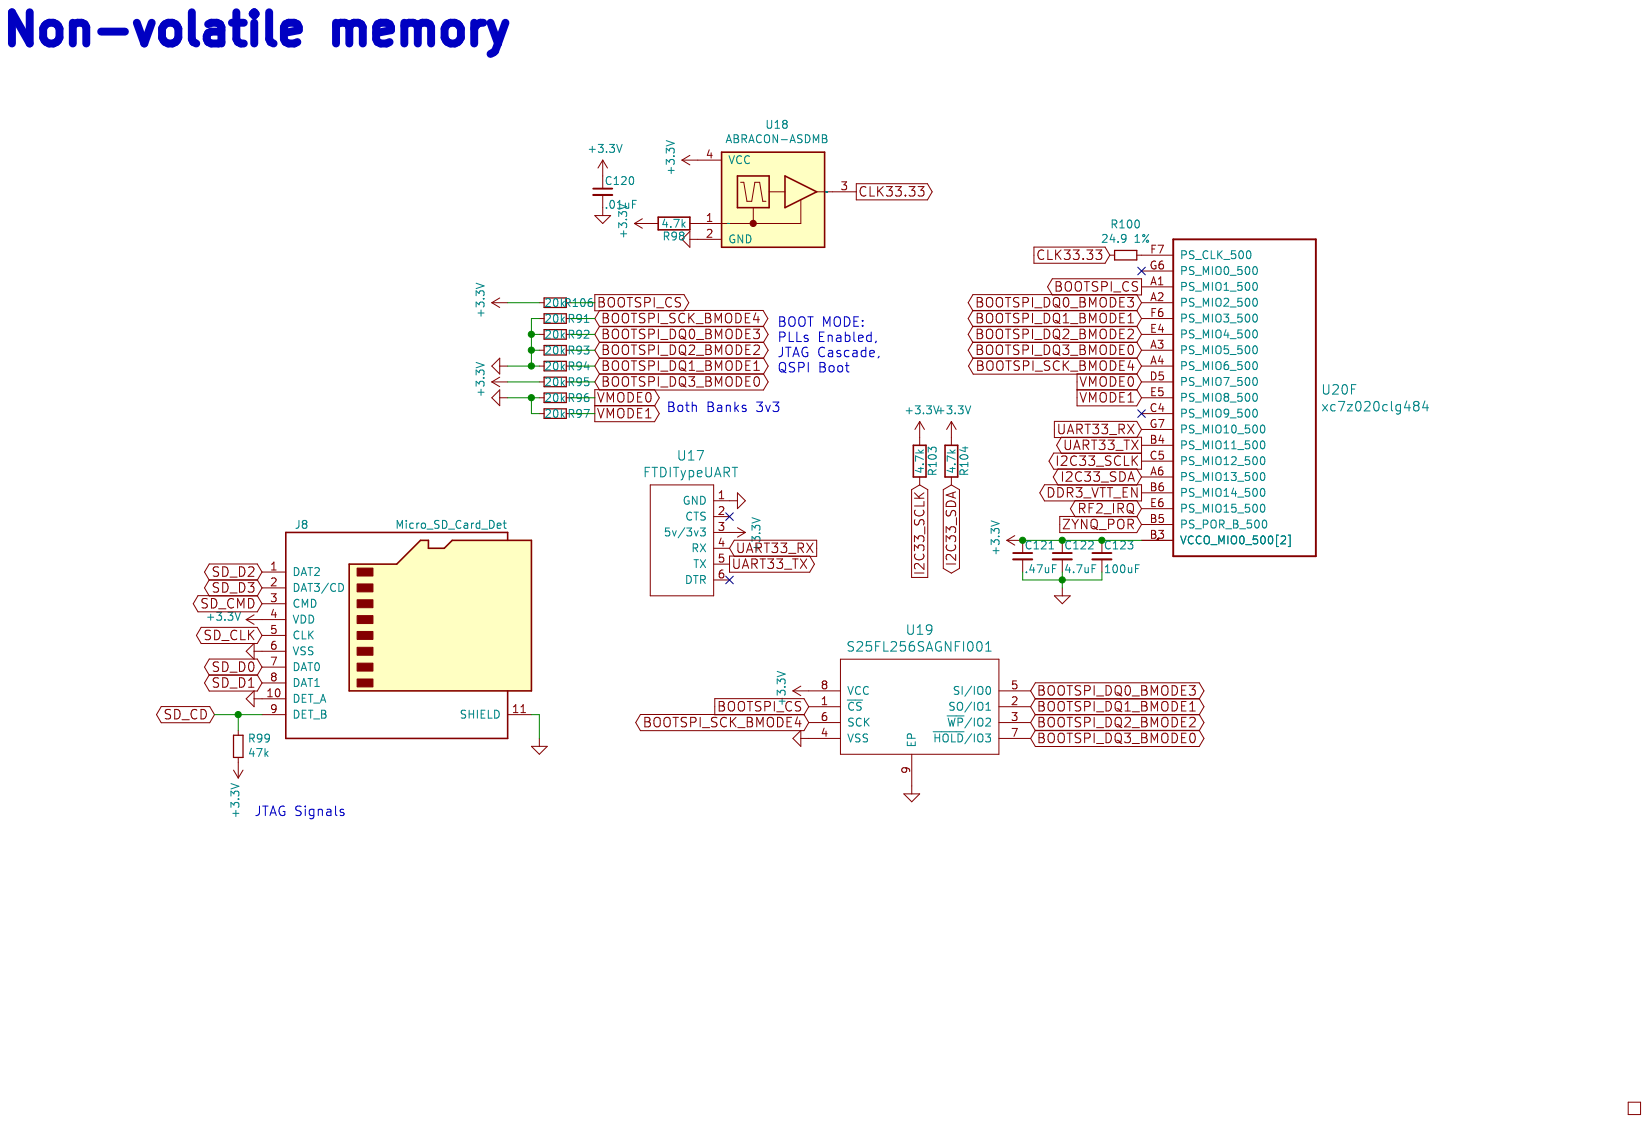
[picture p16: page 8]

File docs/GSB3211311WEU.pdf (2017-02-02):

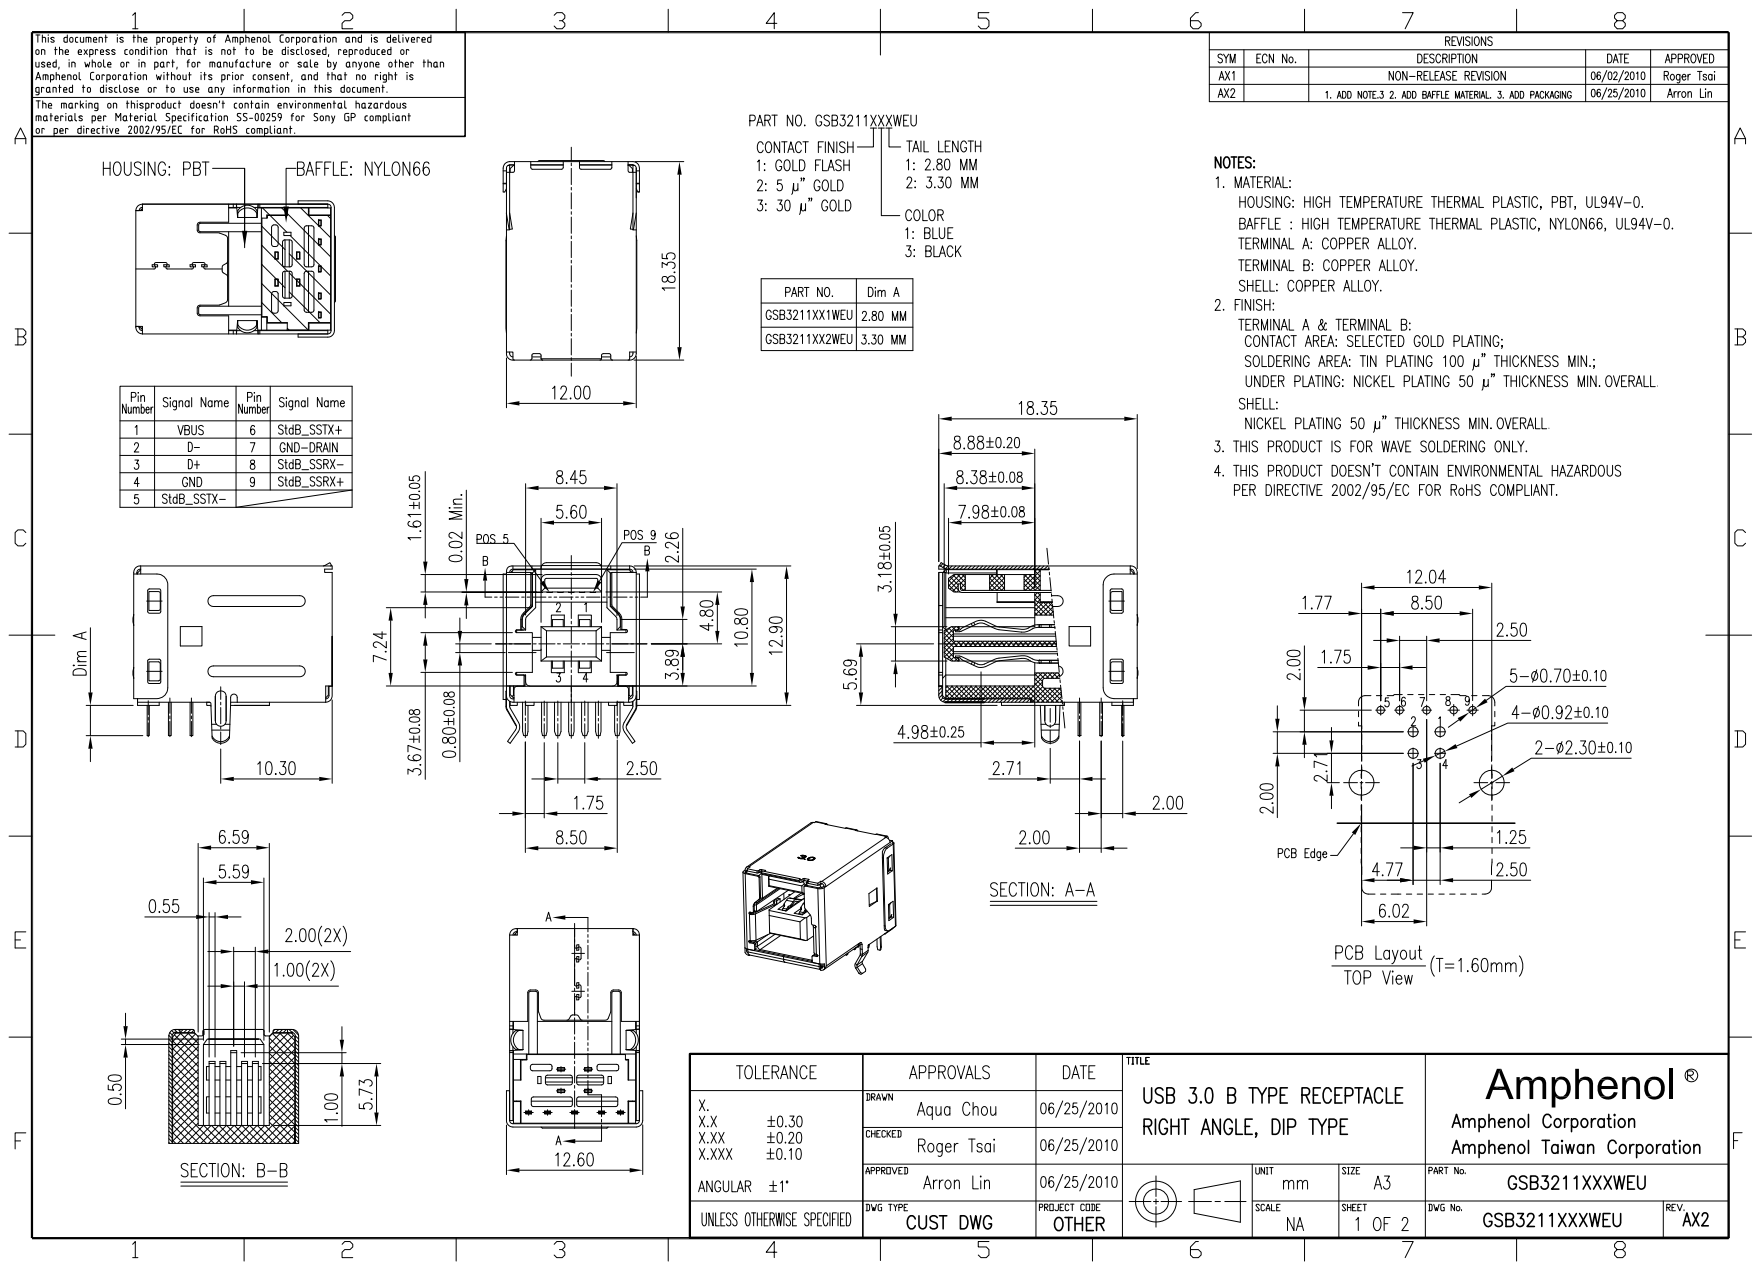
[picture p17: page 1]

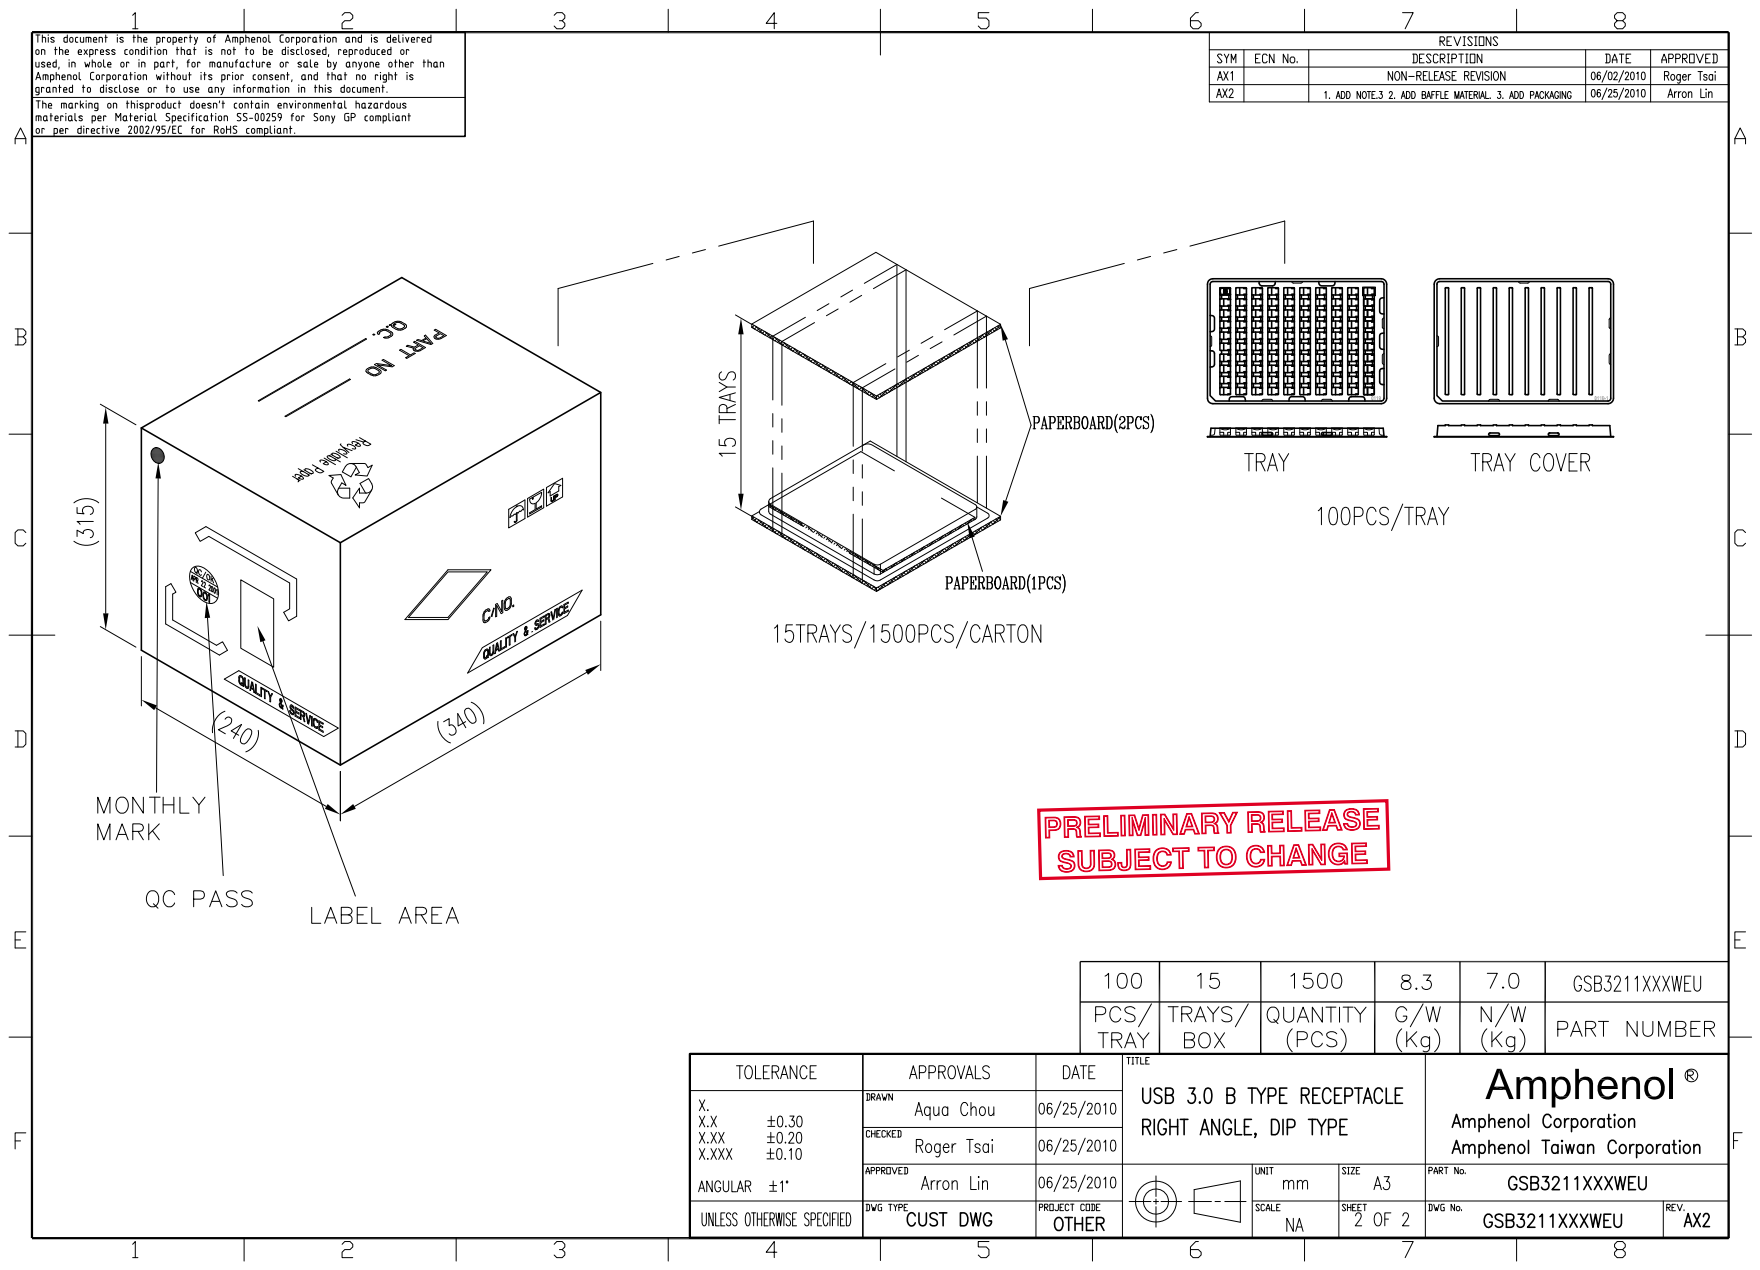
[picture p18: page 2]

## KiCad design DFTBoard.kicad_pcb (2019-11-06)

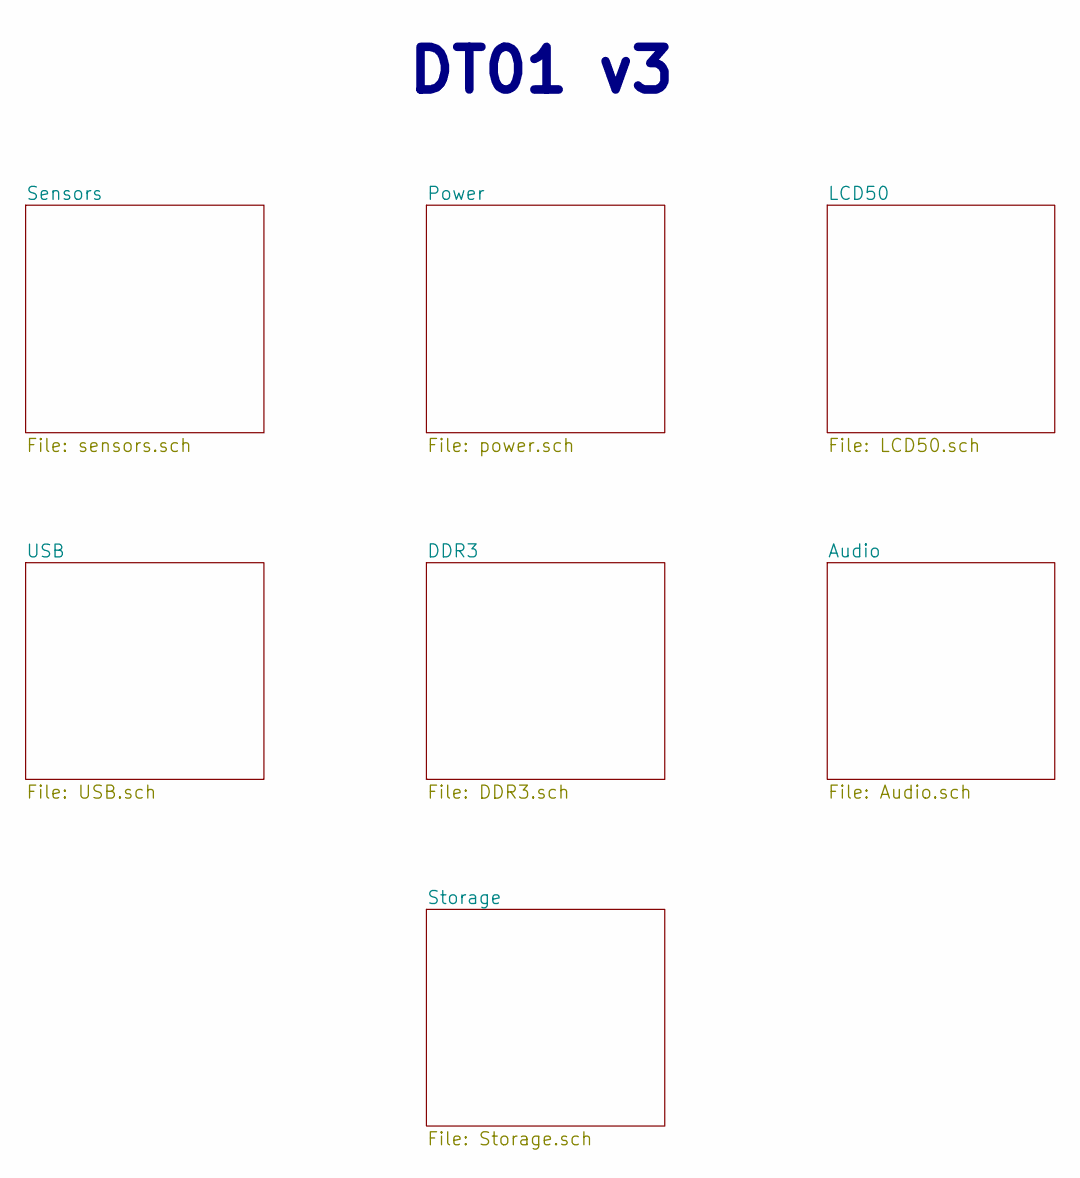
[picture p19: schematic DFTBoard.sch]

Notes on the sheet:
DT01 v3

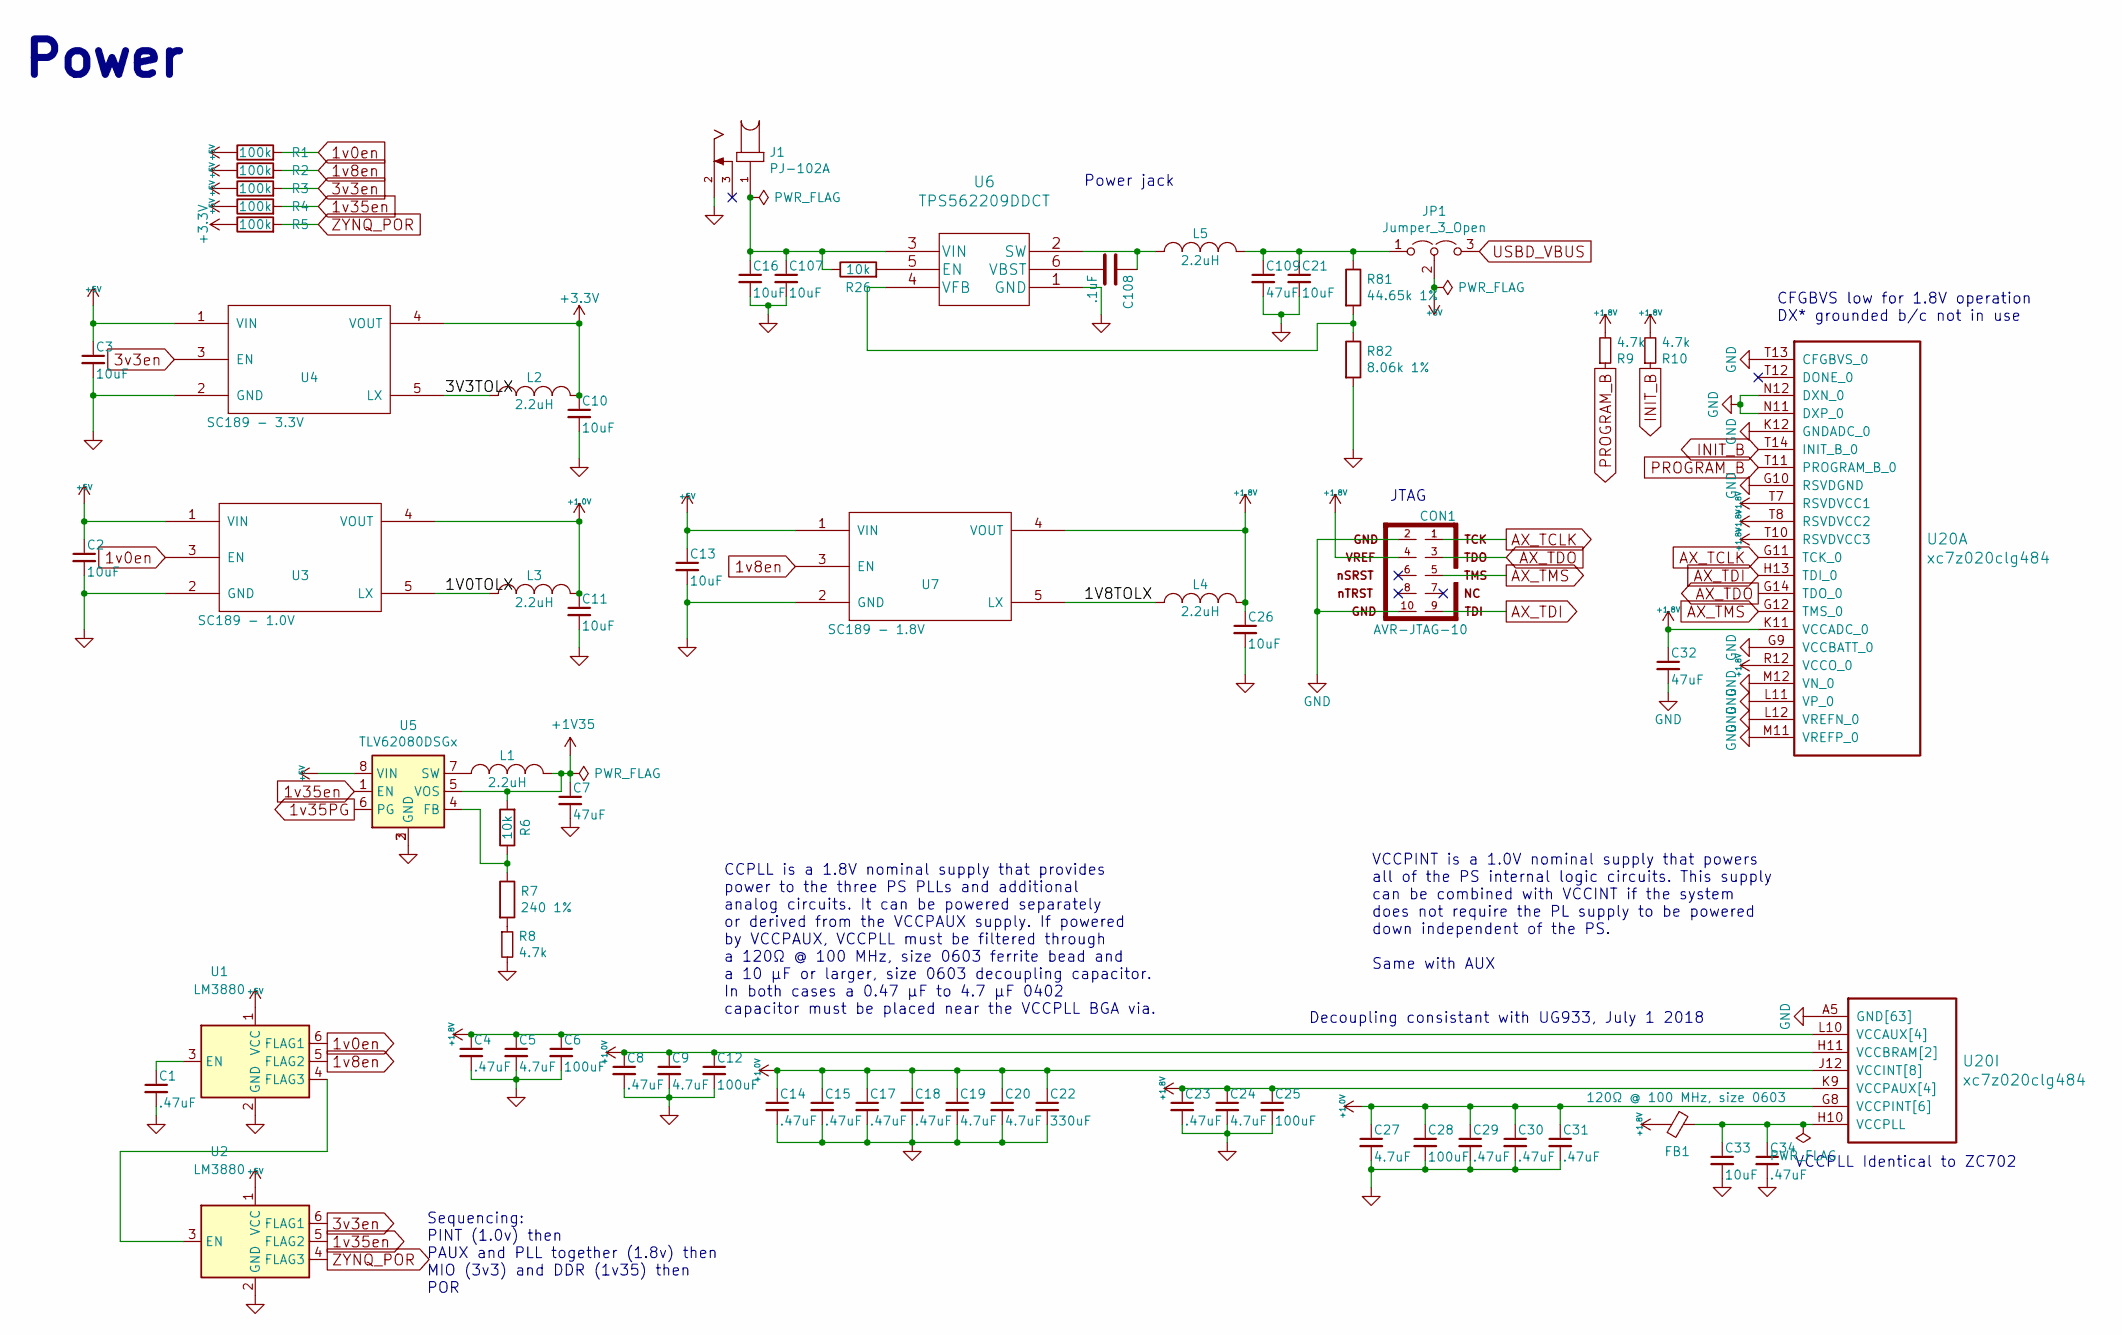
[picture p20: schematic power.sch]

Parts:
C1, C4, C8, C14, C15, C17, C18, C23, C29, C30, C31, C34: .47uF; C_0402_1005Metric; MPN GRM188R71C474KA88D
C2, C3, C10, C11, C13, C16, C21, C26, C33, C107: 10uF; C_0603_1608Metric; MPN GRM21BR61A106KE19L
C5, C9, C19, C20, C24, C27: 4.7uF; C_0402_1005Metric; MPN GRM21BR61A475KA73L
C6, C12, C25, C28: 100uF; C_1210_3225Metric; MPN JMK325ABJ107MM-P
C7, C32, C109: 47uF; C_0805_2012Metric; MPN GRM32ER70J476ME20L
C22: 330uF; C_1206_3216Metric; MPN F950G337MAAAQ2
C108: .1uF; C_0402_1005Metric; MPN GRM188R71C104KA01D
CON1: AVR-JTAG-10; XilinxJTAG
FB1: 120Ω @ 100 MHz, size 0603; C_0603_1608Metric
J1: PJ-102A; CUI_PJ-102A
JP1: Jumper_3_Open; JUMPER_3PIN
L1, L2, L3, L4, L5: 2.2uH; C_1812_4532Metric; MPN LQH43PN2R2M26L
R1, R2, R3, R4, R5: 100k; R_0402_1005Metric; MPN RC0402FR-07100KL
R6, R26: 10k; R_0402_1005Metric; MPN RC0402FR-0710KL
R7: 240 1%; R_0402_1005Metric
R8, R9, R10: 4.7k; R_0402_1005Metric
R81: 44.65k 1%; R_0402_1005Metric
R82: 8.06k 1%; R_0402_1005Metric
U1, U2: LM3880; SOT-23-6
U3: SC189 - 1.0V; SOT-23-5; MPN SC189ASKTRT
U4: SC189 - 3.3V; SOT-23-5; MPN SC189ZSKTRT
U5: TLV62080DSGx; WSON-8-1EP_2x2mm_P0.5mm_EP0.9x1.6mm
U6: TPS562209DDCT
U7: SC189 - 1.8V; SOT-23-5; MPN SC189LSKTRT
U20: xc7z020clg484; BGA-484_19.0x19.0mm_Layout22x22_P0.80mm_dia0.40mm

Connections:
1v0en: R1.2, U1.6 (FLAG1), U3.3 (EN)
1v8en: R2.2, U1.5 (FLAG2), U7.3 (EN)
1v35PG: U5.6 (PG); also elsewhere on the board
1v35en: R4.2, U2.5 (FLAG2), U5.1 (EN)
3v3en: R3.2, U2.6 (FLAG1), U4.3 (EN)
+1V0: C8.1, C9.1, C11.1, C12.1, C14.1, C15.1, C17.1, C18.1, C19.1, C20.1, C22.1, C27.1, C28.1, C29.1, C30.1, C31.1, L3.2, U3.4 (VOUT), U20.G8 (VCCPINT[6]), U20.H9 (VCCPINT[6]), U20.H11 (VCCBRAM[2]), U20.J8 (VCCPINT[6]), U20.J10 (VCCBRAM[2]), U20.J12 (VCCINT[8]), U20.J14 (VCCINT[8]), U20.K13 (VCCINT[8]), U20.L8 (VCCPINT[6]), U20.L14 (VCCINT[8]), U20.M13 (VCCINT[8]), U20.N8 (VCCPINT[6]), U20.N14 (VCCINT[8]), U20.P13 (VCCINT[8]), U20.R8 (VCCPINT[6]), U20.R14 (VCCINT[8])
+1V8: C4.1, C5.1, C6.1, C23.1, C24.1, C25.1, C26.1, C32.1, CON1.4, FB1.2, L4.2, R9.2, R10.2, U7.4 (VOUT), U20.K9 (VCCPAUX[4]), U20.K11 (VCCADC_0), U20.L10 (VCCAUX[4]), U20.M9 (VCCPAUX[4]), U20.N10 (VCCAUX[4]), U20.P9 (VCCPAUX[4]), U20.P11 (VCCAUX[4]), U20.R10 (VCCAUX[4]), U20.R12 (VCCO_0), U20.T7 (RSVDVCC1), U20.T8 (RSVDVCC2), U20.T9 (VCCPAUX[4]), U20.T10 (RSVDVCC3); also elsewhere on the board
+1V35: C7.1, L1.2, R6.2, U5.5 (VOS); also elsewhere on the board
+3V3: C10.1, L2.2, R5.1, U4.4 (VOUT); also elsewhere on the board
+5V: C2.1, C3.1, C13.1, JP1.2 (C), R1.1, R2.1, R3.1, R4.1, U1.1 (VCC), U2.1 (VCC), U3.1 (VIN), U4.1 (VIN), U5.8 (VIN), U7.1 (VIN); also elsewhere on the board
/Power/1V0TOLX: L3.1, U3.5 (LX)
/Power/1V8TOLX: L4.1, U7.5 (LX)
/Power/3V3TOLX: L2.1, U4.5 (LX)
AX_TCLK: CON1.1, U20.G11 (TCK_0)
AX_TDI: CON1.9, U20.H13 (TDI_0)
AX_TDO: CON1.3, U20.G14 (TDO_0)
AX_TMS: CON1.5, U20.G12 (TMS_0)
INIT_B: R10.1, U20.T14 (INIT_B_0)
unnamed: C1.1, U1.3 (EN)
unnamed: C33.1, C34.1, FB1.1, U20.H10 (VCCPLL)
unnamed: C16.1, C107.1, J1.1, R26.1, U6.3 (VIN)
unnamed: C108.1, L5.1, U6.2 (SW)
unnamed: C108.2, U6.6 (VBST)
unnamed: C21.1, C109.1, JP1.1 (A), L5.2, R81.1
unnamed: L1.1, U5.7 (SW)
unnamed: R6.1, R7.1, U5.4 (FB)
unnamed: R7.2, R8.1
unnamed: R26.2, U6.5 (EN)
unnamed: R81.2, R82.1, U6.4 (VFB)
unnamed: U1.4 (FLAG3), U2.3 (EN)
PROGRAM_B: R9.1, U20.T11 (PROGRAM_B_0)
USBD_VBUS: JP1.3 (B); also elsewhere on the board
ZYNQ_POR: R5.2, U2.4 (FLAG3); also elsewhere on the board

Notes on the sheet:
JTAG
Decoupling consistant with UG933, July 1 2018
VCCPINT is a 1.0V nominal supply that powers all of the PS internal logic circuits. This supply can be combined with VCCINT if the system does not require the PL supply to be powered down independent of the PS. Same with AUX
CCPLL is a 1.8V nominal supply that provides power to the three PS PLLs and additional analog circuits. It can be powered separately or derived from the VCCPAUX supply. If powered by VCCPAUX, VCCPLL must be filtered through a 120Ω @ 100 MHz, size 0603 ferrite bead and a 10 µF or larger, size 0603 d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
VCCPLL Identical to ZC702
CFGBVS low for 1.8V operation DX* grounded b/c not in use
Sequencing: PINT (1.0v) then PAUX and PLL together (1.8v) then MIO (3v3) and DDR (1v35) then POR
Power
Power jack

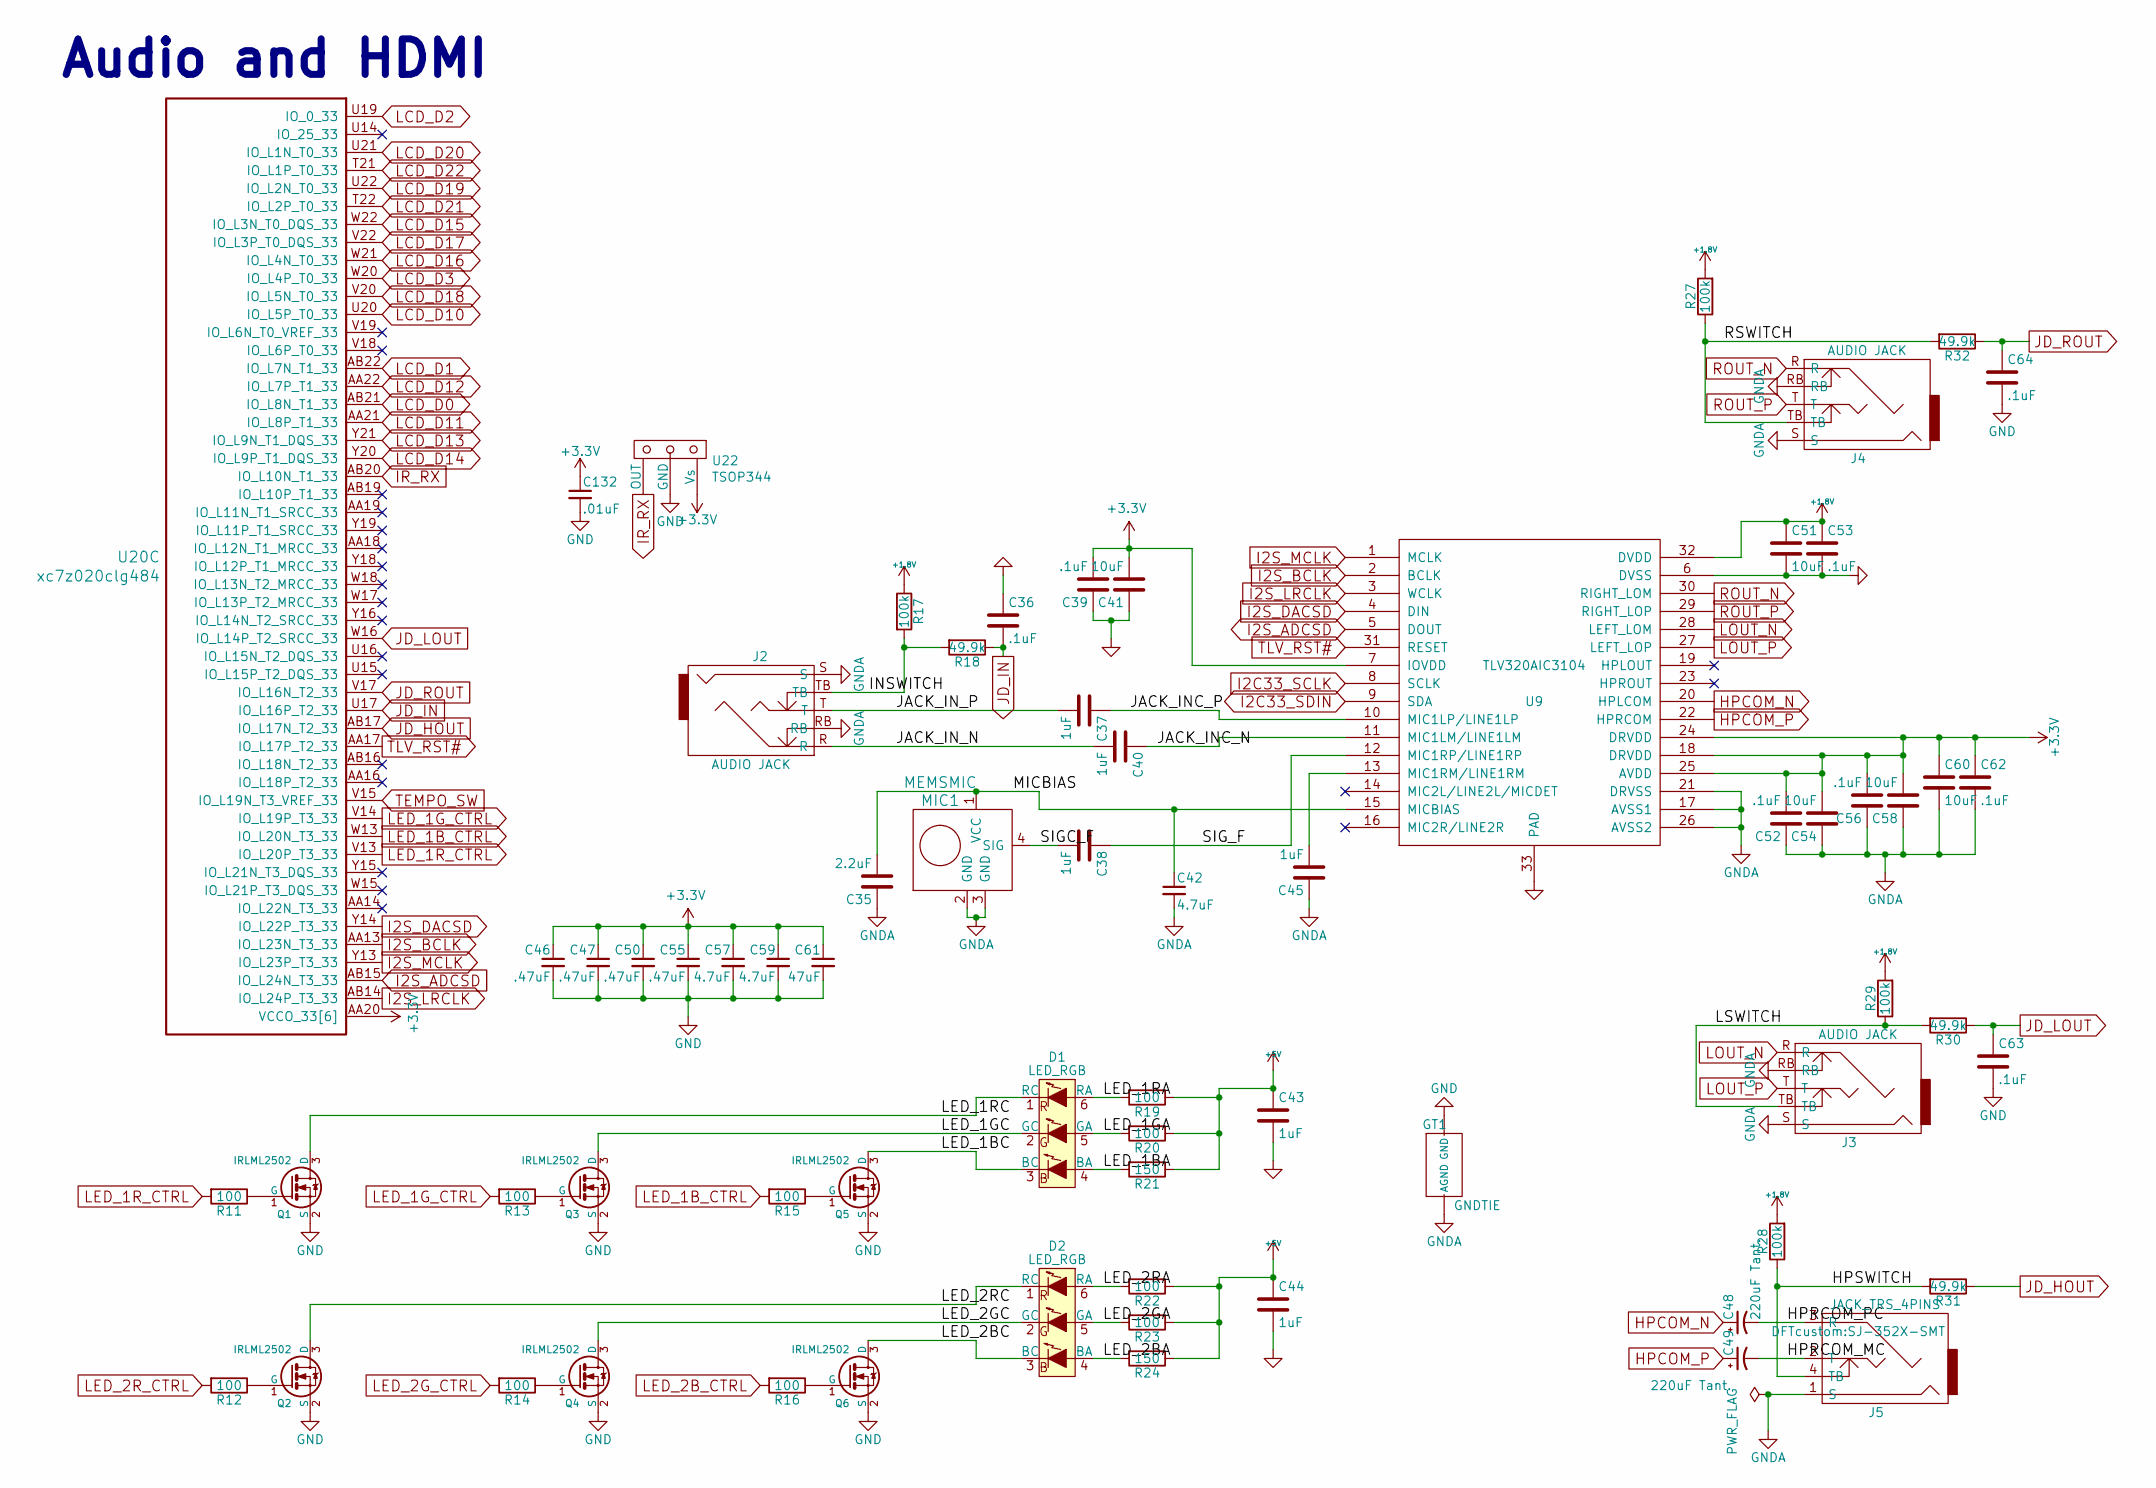
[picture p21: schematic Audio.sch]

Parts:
C35: 2.2uF; C_0402_1005Metric; MPN GRM155R61A225KE95D
C36, C39, C52, C53, C56, C62, C63, C64: .1uF; C_0402_1005Metric; MPN GRM188R71C104KA01D
C37, C38, C40, C43, C44, C45: 1uF; C_0402_1005Metric; MPN GRM188R71C105KE15D
C41, C51, C54, C58, C60: 10uF; C_0603_1608Metric; MPN GRM21BR61A106KE19L
C42, C57, C59: 4.7uF; C_0402_1005Metric; MPN GRM21BR61A475KA73L
C46, C47, C50, C55: .47uF; C_0402_1005Metric; MPN GRM188R71C474KA88D
C48, C49: 220uF Tant.; CP_EIA-3528-12_Kemet-T; MPN F930G227KBA
C61: 47uF; C_0805_2012Metric; MPN GRM32ER70J476ME20L
C132: .01uF; C_0402_1005Metric
D1, D2: LED_RGB; PLCC6-SM-RGB-LED; MPN CLP6C-FKB-CM1Q1H1BB7R3R3
GT1: GNDTIE; gndtie
J2, J3, J4: AUDIO JACK; RA49C14B; MPN RA49C12B
J5: JACK_TRS_4PINS; SJ-352X-SMT; MPN SJ-3524-SMT-TR
MIC1: MEMSMIC; WM7121PE; MPN WM7121PIMSE/RV
Q1, Q2, Q3, Q4, Q5, Q6: IRLML2502; SOT-23; MPN IRLML2502TRPBF
R11, R12, R13, R14, R15, R16, R19, R20, R22, R23: 100; R_0402_1005Metric; MPN RC0402FR-07100RL
R17, R27, R28, R29: 100k; R_0402_1005Metric; MPN RC0402FR-07100KL
R18, R30, R31, R32: 49.9k; R_0402_1005Metric; MPN RC0402FR-0749K9L
R21, R24: 150; R_0402_1005Metric; MPN RC0402FR-07150RL
U9: TLV320AIC3104; QFN-32-1EP_5x5mm_P0.5mm_EP3.65x3.65mm; MPN TLV320AIC3104IRHBR
U20: xc7z020clg484; BGA-484_19.0x19.0mm_Layout22x22_P0.80mm_dia0.40mm
U22: TSOP344; JUMPER_3PIN

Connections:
+1V8: C51.1, C53.1, R17.1, R27.2, R28.2, R29.2, U9.32 (DVDD); also elsewhere on the board
+3V3: C39.2, C41.2, C46.1, C47.1, C50.1, C52.2, C54.2, C55.1, C56.2, C57.1, C58.2, C59.1, C60.1, C61.1, C62.1, C132.1, U9.7 (IOVDD), U9.18 (DRVDD), U9.24 (DRVDD), U9.25 (AVDD), U20.AA20 (VCCO_33[6]), U20.AB13 (VCCO_33[6]), U20.U18 (VCCO_33[6]), U20.V21 (VCCO_33[6]), U20.W14 (VCCO_33[6]), U20.Y17 (VCCO_33[6]), U22.3 (Vs); also elsewhere on the board
+5V: C43.1, C44.1, R19.1, R20.1, R21.1, R22.1, R23.1, R24.1; also elsewhere on the board
/Audio/HPRCOM_MC: C49.2, J5.2 (T)
/Audio/HPRCOM_PC: C48.2, J5.3 (R)
/Audio/HPSWITCH: J5.4 (TB), R28.1, R31.2
/Audio/INSWITCH: J2.TB, R17.2, R18.2
/Audio/JACK_INC_N: C40.1, U9.11 (MIC1LM/LINE1LM)
/Audio/JACK_INC_P: C37.1, U9.10 (MIC1LP/LINE1LP)
/Audio/JACK_IN_N: C40.2, J2.R
/Audio/JACK_IN_P: C37.2, J2.T
/Audio/LED_1BA: D1.4 (BA), R21.2
/Audio/LED_1BC: D1.3 (BC), Q5.3 (D)
/Audio/LED_1GA: D1.5 (GA), R20.2
/Audio/LED_1GC: D1.2 (GC), Q3.3 (D)
/Audio/LED_1RA: D1.6 (RA), R19.2
/Audio/LED_1RC: D1.1 (RC), Q1.3 (D)
/Audio/LED_2BA: D2.4 (BA), R24.2
/Audio/LED_2BC: D2.3 (BC), Q6.3 (D)
/Audio/LED_2GA: D2.5 (GA), R23.2
/Audio/LED_2GC: D2.2 (GC), Q4.3 (D)
/Audio/LED_2RA: D2.6 (RA), R22.2
/Audio/LED_2RC: D2.1 (RC), Q2.3 (D)
/Audio/LSWITCH: J3.TB, R29.1, R30.2
/Audio/MICBIAS: C35.2, C42.1, MIC1.1 (VCC), U9.15 (MICBIAS)
/Audio/RSWITCH: J4.TB, R27.1, R32.2
/Audio/SIGC_F: C38.2, MIC1.4 (SIG)
/Audio/SIG_F: C38.1, U9.12 (MIC1RP/LINE1RP)
HPCOM_N: C48.1, U9.20 (HPLCOM)
HPCOM_P: C49.1, U9.22 (HPRCOM)
I2C33_SCLK: U9.8 (SCLK); also elsewhere on the board
I2C33_SDIN: U9.9 (SDA); also elsewhere on the board
I2S_ADCSD: U9.5 (DOUT), U20.AB15 (IO_L24N_T3_33)
I2S_BCLK: U9.2 (BCLK), U20.AA13 (IO_L23N_T3_33)
I2S_DACSD: U9.4 (DIN), U20.Y14 (IO_L22P_T3_33)
I2S_LRCLK: U9.3 (WCLK), U20.AB14 (IO_L24P_T3_33)
I2S_MCLK: U9.1 (MCLK), U20.Y13 (IO_L23P_T3_33)
IR_RX: U20.AB20 (IO_L10N_T1_33), U22.1 (OUT)
JD_HOUT: R31.1, U20.AB17 (IO_L17N_T2_33)
JD_IN: C36.2, R18.1, U20.U17 (IO_L16P_T2_33)
JD_LOUT: C63.1, R30.1, U20.W16 (IO_L14P_T2_SRCC_33)
JD_ROUT: C64.1, R32.1, U20.V17 (IO_L16N_T2_33)
LCD_D0: U20.AB21 (IO_L8N_T1_33); also elsewhere on the board
LCD_D1: U20.AB22 (IO_L7N_T1_33); also elsewhere on the board
LCD_D2: U20.U19 (IO_0_33); also elsewhere on the board
LCD_D3: U20.W20 (IO_L4P_T0_33); also elsewhere on the board
LCD_D10: U20.U20 (IO_L5P_T0_33); also elsewhere on the board
LCD_D11: U20.AA21 (IO_L8P_T1_33); also elsewhere on the board
LCD_D12: U20.AA22 (IO_L7P_T1_33); also elsewhere on the board
LCD_D13: U20.Y21 (IO_L9N_T1_DQS_33); also elsewhere on the board
LCD_D14: U20.Y20 (IO_L9P_T1_DQS_33); also elsewhere on the board
LCD_D15: U20.W22 (IO_L3N_T0_DQS_33); also elsewhere on the board
LCD_D16: U20.W21 (IO_L4N_T0_33); also elsewhere on the board
LCD_D17: U20.V22 (IO_L3P_T0_DQS_33); also elsewhere on the board
LCD_D18: U20.V20 (IO_L5N_T0_33); also elsewhere on the board
LCD_D19: U20.U22 (IO_L2N_T0_33); also elsewhere on the board
LCD_D20: U20.U21 (IO_L1N_T0_33); also elsewhere on the board
LCD_D21: U20.T22 (IO_L2P_T0_33); also elsewhere on the board
LCD_D22: U20.T21 (IO_L1P_T0_33); also elsewhere on the board
LED_1B_CTRL: R15.2, U20.W13 (IO_L20N_T3_33)
LED_1G_CTRL: R13.2, U20.V14 (IO_L19P_T3_33)
LED_1R_CTRL: R11.2, U20.V13 (IO_L20P_T3_33)
LED_2B_CTRL: R16.2; also elsewhere on the board
LED_2G_CTRL: R14.2; also elsewhere on the board
LED_2R_CTRL: R12.2; also elsewhere on the board
LOUT_N: J3.R, U9.28 (LEFT_LOM)
LOUT_P: J3.T, U9.27 (LEFT_LOP)
unnamed: C45.2, U9.13 (MIC1RM/LINE1RM)
unnamed: Q1.1 (G), R11.1
unnamed: Q2.1 (G), R12.1
unnamed: Q3.1 (G), R13.1
unnamed: Q4.1 (G), R14.1
unnamed: Q5.1 (G), R15.1
unnamed: Q6.1 (G), R16.1
ROUT_N: J4.R, U9.30 (RIGHT_LOM)
ROUT_P: J4.T, U9.29 (RIGHT_LOP)
TEMPO_SW: U20.V15 (IO_L19N_T3_VREF_33); also elsewhere on the board
TLV_RST#: U9.31 (RESET), U20.AA17 (IO_L17P_T2_33)

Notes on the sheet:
Audio and HDMI

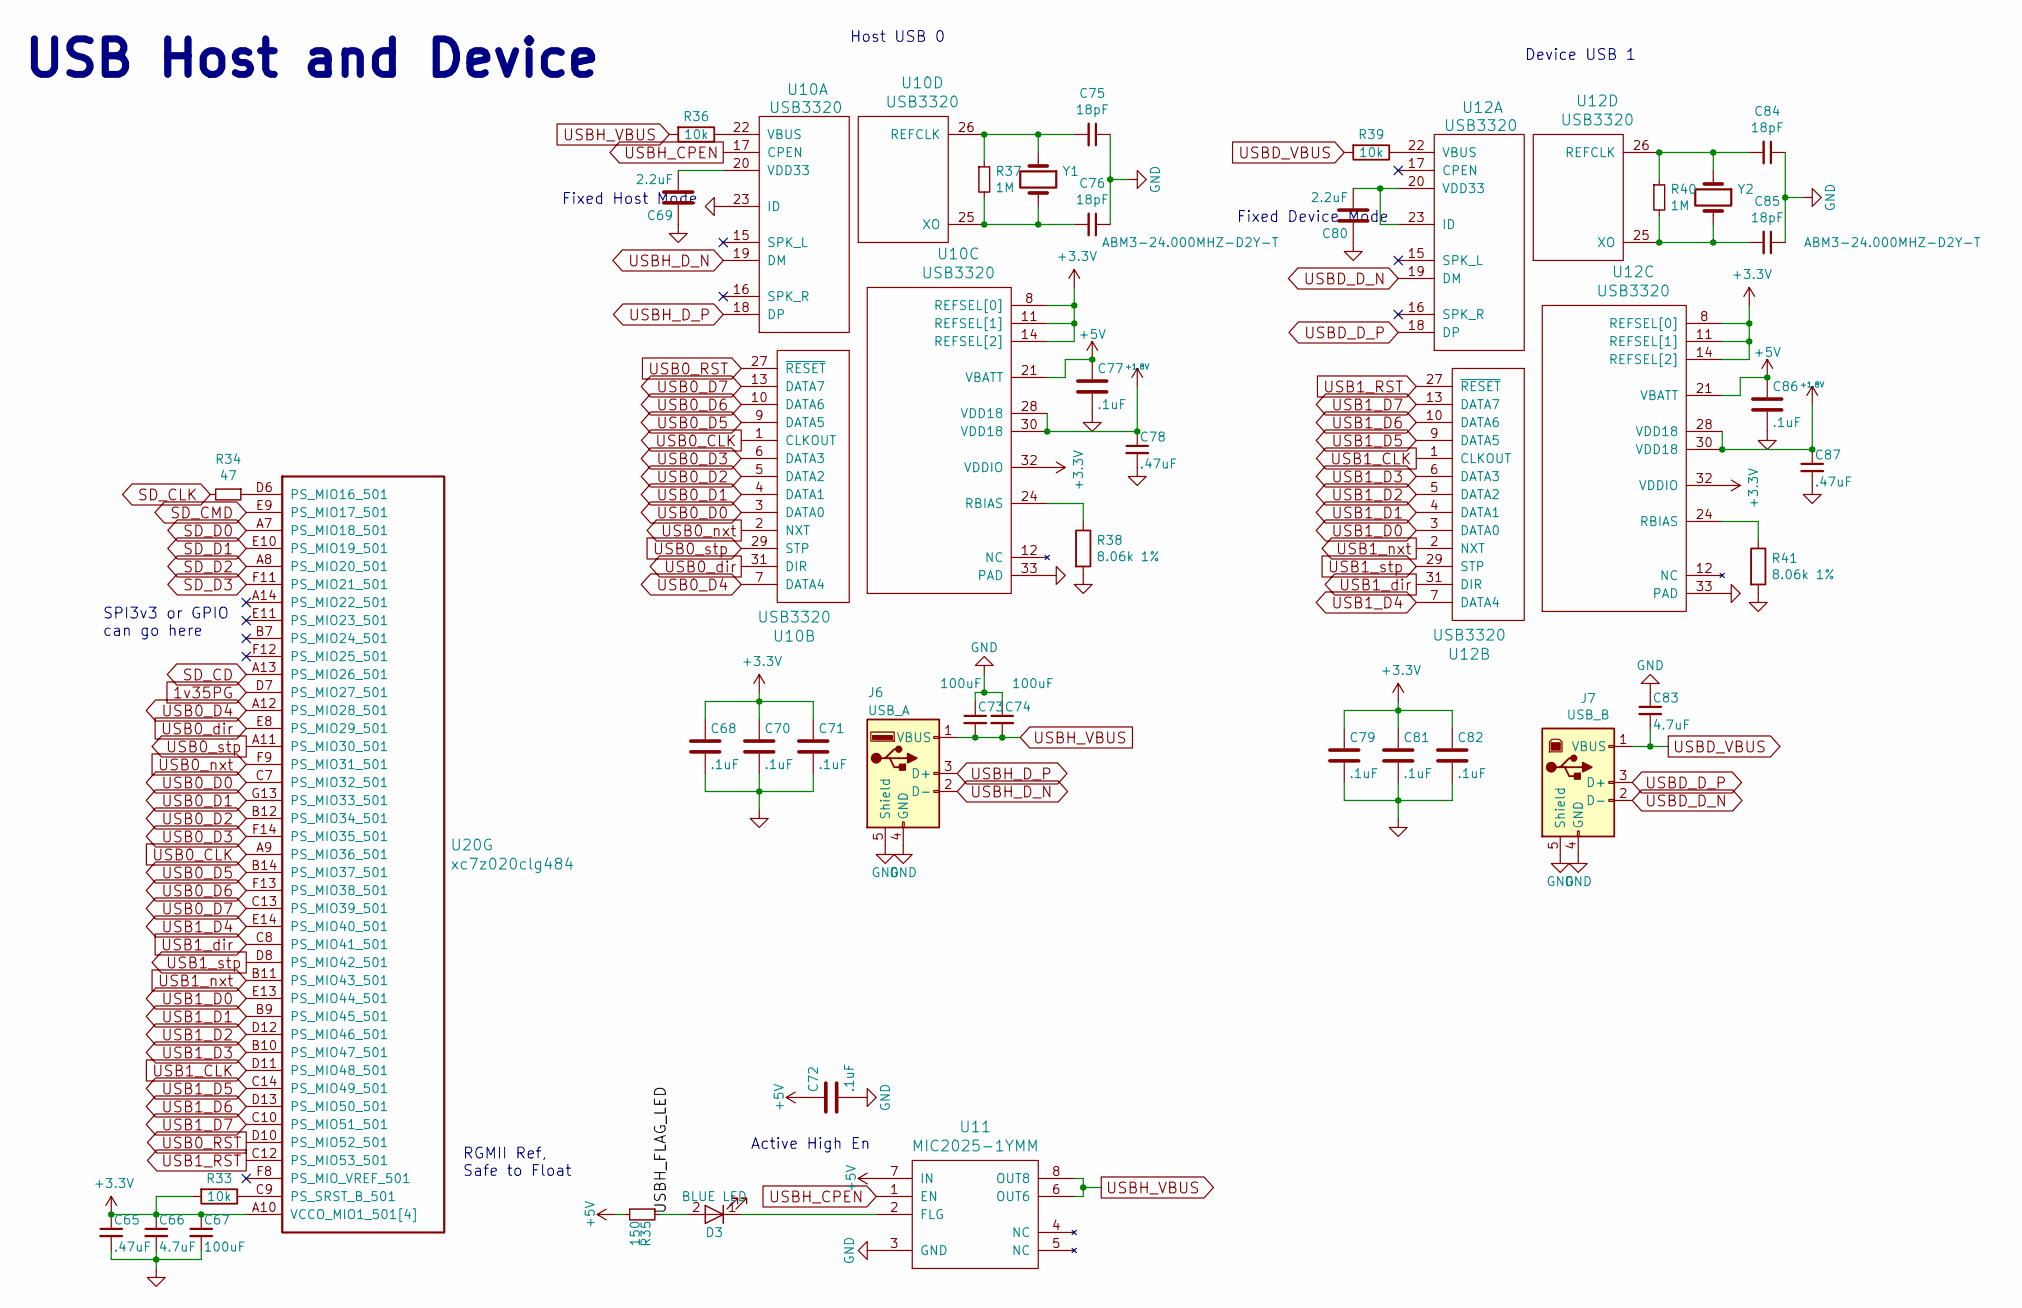
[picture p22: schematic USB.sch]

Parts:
C65, C78, C87: .47uF; C_0402_1005Metric; MPN GRM188R71C474KA88D
C66, C83: 4.7uF; C_0402_1005Metric; MPN GRM21BR61A475KA73L
C67, C73, C74: 100uF; C_1210_3225Metric; MPN JMK325ABJ107MM-P
C68, C70, C71, C72, C77, C79, C81, C82, C86: .1uF; C_0402_1005Metric; MPN GRM188R71C104KA01D
C69, C80: 2.2uF; C_0402_1005Metric; MPN GRM155R61A225KE95D
C75, C76, C84, C85: 18pF; C_0402_1005Metric
D3: BLUE LED; C_0603_1608Metric; MPN VLMB1300-GS08
J6: USB_A; USB-A-Receptacle-FCI_87583
J7: USB_B; USB_B_OST_USB-B1HSxx_Horizontal
R33, R36, R39: 10k; R_0402_1005Metric; MPN RC0402FR-0710KL
R34: 47; R_0402_1005Metric
R35: 150; R_0402_1005Metric; MPN RC0402FR-07150RL
R37, R40: 1M; R_0402_1005Metric
R38, R41: 8.06k 1%; R_0402_1005Metric
U10, U12: USB3320; QFN-32-1EP_5x5mm_P0.5mm_EP3.1x3.1mm
U11: MIC2025-1YMM; SOP65P490X110-8N
U20: xc7z020clg484; BGA-484_19.0x19.0mm_Layout22x22_P0.80mm_dia0.40mm
Y1, Y2: ABM3-24.000MHZ-D2Y-T; XTAL500X320X130N

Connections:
1v35PG: U20.D7 (PS_MIO27_501); also elsewhere on the board
+1V8: C78.1, C87.1, U10.28 (VDD18), U10.30 (VDD18), U12.28 (VDD18), U12.30 (VDD18); also elsewhere on the board
+3V3: C65.1, C66.1, C67.1, C68.1, C70.1, C71.1, C79.1, C81.1, C82.1, R33.2, U10.8 (REFSEL[0]), U10.11 (REFSEL[1]), U10.14 (REFSEL[2]), U10.32 (VDDIO), U12.8 (REFSEL[0]), U12.11 (REFSEL[1]), U12.14 (REFSEL[2]), U12.32 (VDDIO), U20.A10 (VCCO_MIO1_501[4]), U20.B13 (VCCO_MIO1_501[4]), U20.D9 (VCCO_MIO1_501[4]), U20.E12 (VCCO_MIO1_501[4]); also elsewhere on the board
+5V: C72.1, C77.1, C86.1, R35.2, U10.21 (VBATT), U11.7 (IN), U12.21 (VBATT); also elsewhere on the board
/USB/USBH_FLAG_LED: D3.2 (A), R35.1
unnamed: C69.2, U10.20 (VDD33)
unnamed: C75.2, R37.1, U10.26 (REFCLK), Y1.1
unnamed: C76.2, R37.2, U10.25 (XO), Y1.2
unnamed: C80.2, U12.20 (VDD33), U12.23 (ID)
unnamed: C84.2, R40.1, U12.26 (REFCLK), Y2.1
unnamed: C85.2, R40.2, U12.25 (XO), Y2.2
unnamed: D3.1 (K), U11.2 (FLG)
unnamed: R33.1, U20.C9 (PS_SRST_B_501)
unnamed: R34.1, U20.D6 (PS_MIO16_501)
unnamed: R36.1, U10.22 (VBUS)
unnamed: R38.1, U10.24 (RBIAS)
unnamed: R39.1, U12.22 (VBUS)
unnamed: R41.1, U12.24 (RBIAS)
SD_CD: U20.A13 (PS_MIO26_501); also elsewhere on the board
SD_CLK: R34.2; also elsewhere on the board
SD_CMD: U20.E9 (PS_MIO17_501); also elsewhere on the board
SD_D0: U20.A7 (PS_MIO18_501); also elsewhere on the board
SD_D1: U20.E10 (PS_MIO19_501); also elsewhere on the board
SD_D2: U20.A8 (PS_MIO20_501); also elsewhere on the board
SD_D3: U20.F11 (PS_MIO21_501); also elsewhere on the board
USB0_CLK: U10.1 (CLKOUT), U20.A9 (PS_MIO36_501)
USB0_D0: U10.3 (DATA0), U20.C7 (PS_MIO32_501)
USB0_D1: U10.4 (DATA1), U20.G13 (PS_MIO33_501)
USB0_D2: U10.5 (DATA2), U20.B12 (PS_MIO34_501)
USB0_D3: U10.6 (DATA3), U20.F14 (PS_MIO35_501)
USB0_D4: U10.7 (DATA4), U20.A12 (PS_MIO28_501)
USB0_D5: U10.9 (DATA5), U20.B14 (PS_MIO37_501)
USB0_D6: U10.10 (DATA6), U20.F13 (PS_MIO38_501)
USB0_D7: U10.13 (DATA7), U20.C13 (PS_MIO39_501)
USB0_RST: U10.27 (~RESET), U20.D10 (PS_MIO52_501)
USB0_dir: U10.31 (DIR), U20.E8 (PS_MIO29_501)
USB0_nxt: U10.2 (NXT), U20.F9 (PS_MIO31_501)
USB0_stp: U10.29 (STP), U20.A11 (PS_MIO30_501)
USB1_CLK: U12.1 (CLKOUT), U20.D11 (PS_MIO48_501)
USB1_D0: U12.3 (DATA0), U20.E13 (PS_MIO44_501)
USB1_D1: U12.4 (DATA1), U20.B9 (PS_MIO45_501)
USB1_D2: U12.5 (DATA2), U20.D12 (PS_MIO46_501)
USB1_D3: U12.6 (DATA3), U20.B10 (PS_MIO47_501)
USB1_D4: U12.7 (DATA4), U20.E14 (PS_MIO40_501)
USB1_D5: U12.9 (DATA5), U20.C14 (PS_MIO49_501)
USB1_D6: U12.10 (DATA6), U20.D13 (PS_MIO50_501)
USB1_D7: U12.13 (DATA7), U20.C10 (PS_MIO51_501)
USB1_RST: U12.27 (~RESET), U20.C12 (PS_MIO53_501)
USB1_dir: U12.31 (DIR), U20.C8 (PS_MIO41_501)
USB1_nxt: U12.2 (NXT), U20.B11 (PS_MIO43_501)
USB1_stp: U12.29 (STP), U20.D8 (PS_MIO42_501)
USBD_D_N: J7.2 (D-), U12.19 (DM)
USBD_D_P: J7.3 (D+), U12.18 (DP)
USBD_VBUS: C83.2, J7.1 (VBUS), R39.2; also elsewhere on the board
USBH_CPEN: U10.17 (CPEN), U11.1 (EN)
USBH_D_N: J6.2 (D-), U10.19 (DM)
USBH_D_P: J6.3 (D+), U10.18 (DP)
USBH_VBUS: C73.2, C74.2, J6.1 (VBUS), R36.2, U11.6 (OUT6), U11.8 (OUT8)

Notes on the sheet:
Host USB 0
Fixed Host Mode
Active High En
Device USB 1
Fixed Device Mode
RGMII Ref, Safe to Float
SPI3v3 or GPIO can go here
USB Host and Device

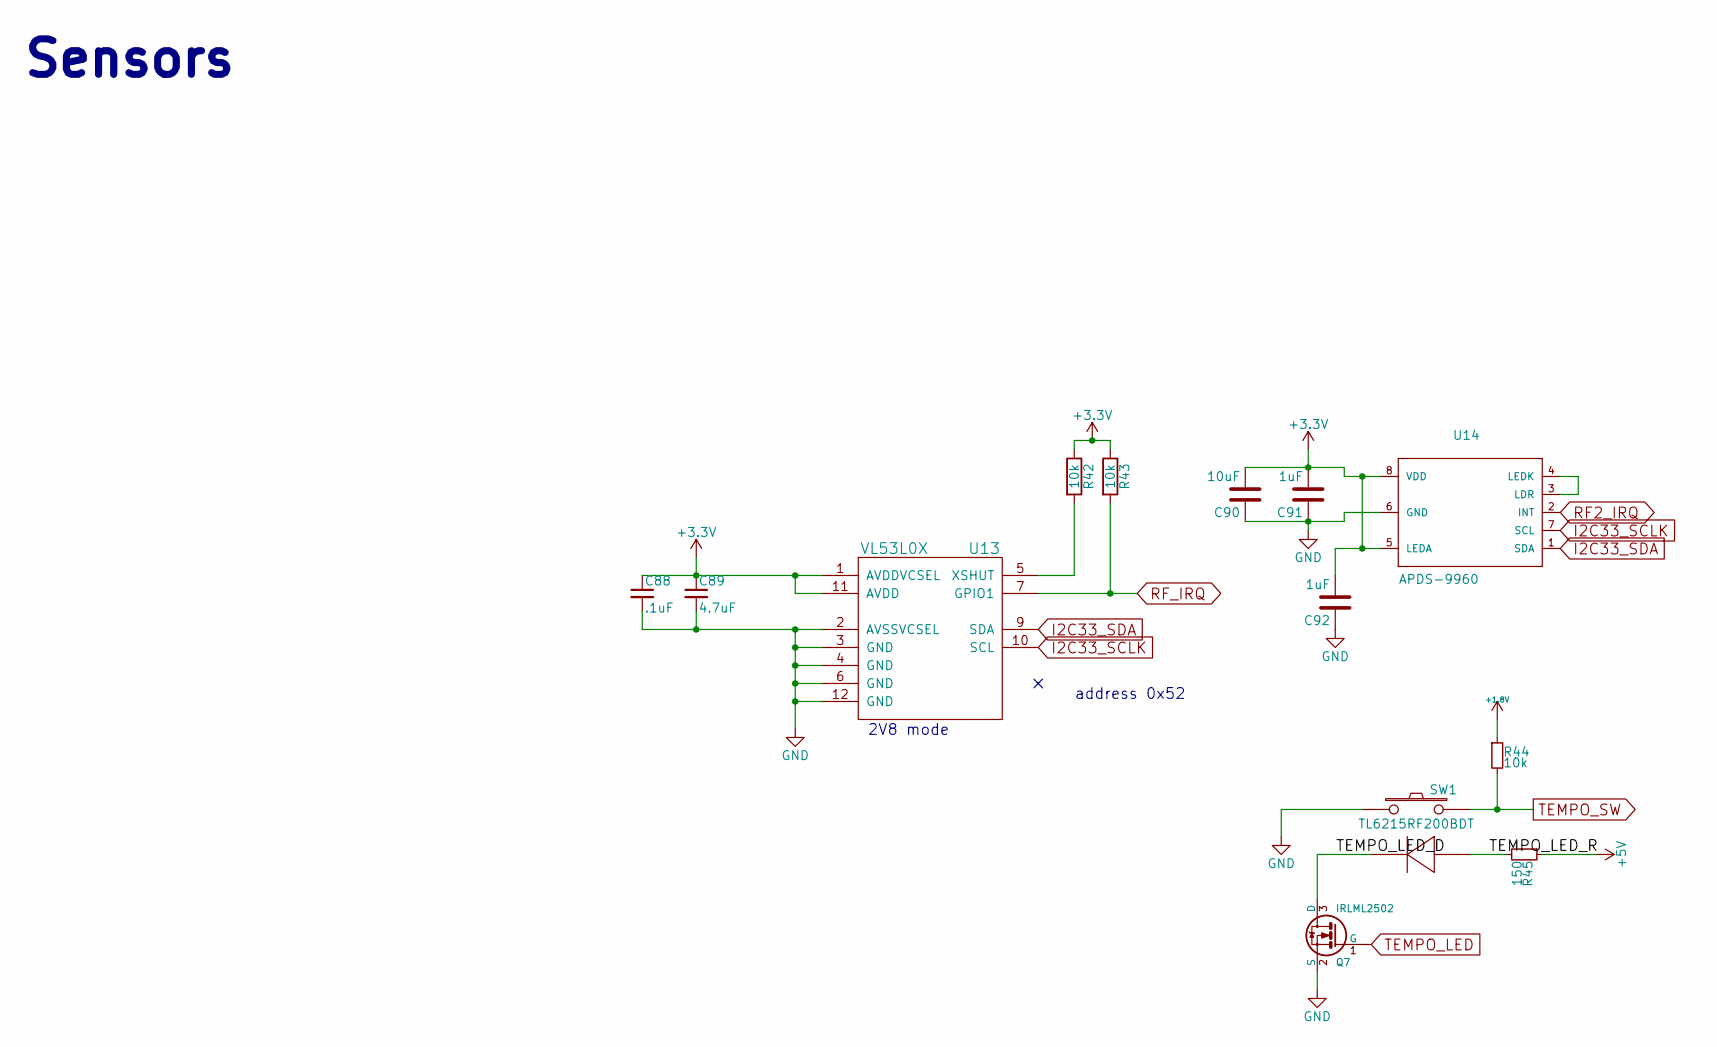
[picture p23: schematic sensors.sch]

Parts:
C88: .1uF; C_0402_1005Metric; MPN GRM188R71C104KA01D
C89: 4.7uF; C_0402_1005Metric; MPN GRM21BR61A475KA73L
C90: 10uF; C_0603_1608Metric; MPN GRM21BR61A106KE19L
C91, C92: 1uF; C_0402_1005Metric; MPN GRM188R71C105KE15D
Q7: IRLML2502; SOT-23; MPN IRLML2502TRPBF
R42, R43, R44: 10k; R_0402_1005Metric; MPN RC0402FR-0710KL
R45: 150; R_0402_1005Metric; MPN RC0402FR-07150RL
SW1: TL6215RF200BDT; tl6215_right_angle; MPN TL6215RF200BDT
U13: VL53L0X; Optical_LGA12; MPN VL53L0CXV0DH/1
U14: APDS-9960; APDS_9960

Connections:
+1V8: R44.1; also elsewhere on the board
+3V3: C88.1, C89.1, C90.2, C91.2, C92.2, R42.1, R43.1, U13.1 (AVDDVCSEL), U13.11 (AVDD), U14.5 (LEDA), U14.8 (VDD); also elsewhere on the board
+5V: R45.1; also elsewhere on the board
/Sensors/TEMPO_LED_D: Q7.3 (D), SW1.3
/Sensors/TEMPO_LED_R: R45.2, SW1.4
I2C33_SCLK: U13.10 (SCL), U14.7 (SCL); also elsewhere on the board
I2C33_SDA: U13.9 (SDA), U14.1 (SDA); also elsewhere on the board
unnamed: R42.2, U13.5 (XSHUT)
unnamed: U14.3 (LDR), U14.4 (LEDK)
RF2_IRQ: U14.2 (INT); also elsewhere on the board
RF_IRQ: R43.2, U13.7 (GPIO1); also elsewhere on the board
TEMPO_LED: Q7.1 (G); also elsewhere on the board
TEMPO_SW: R44.2, SW1.2; also elsewhere on the board

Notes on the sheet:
address 0x52
Sensors
2V8 mode

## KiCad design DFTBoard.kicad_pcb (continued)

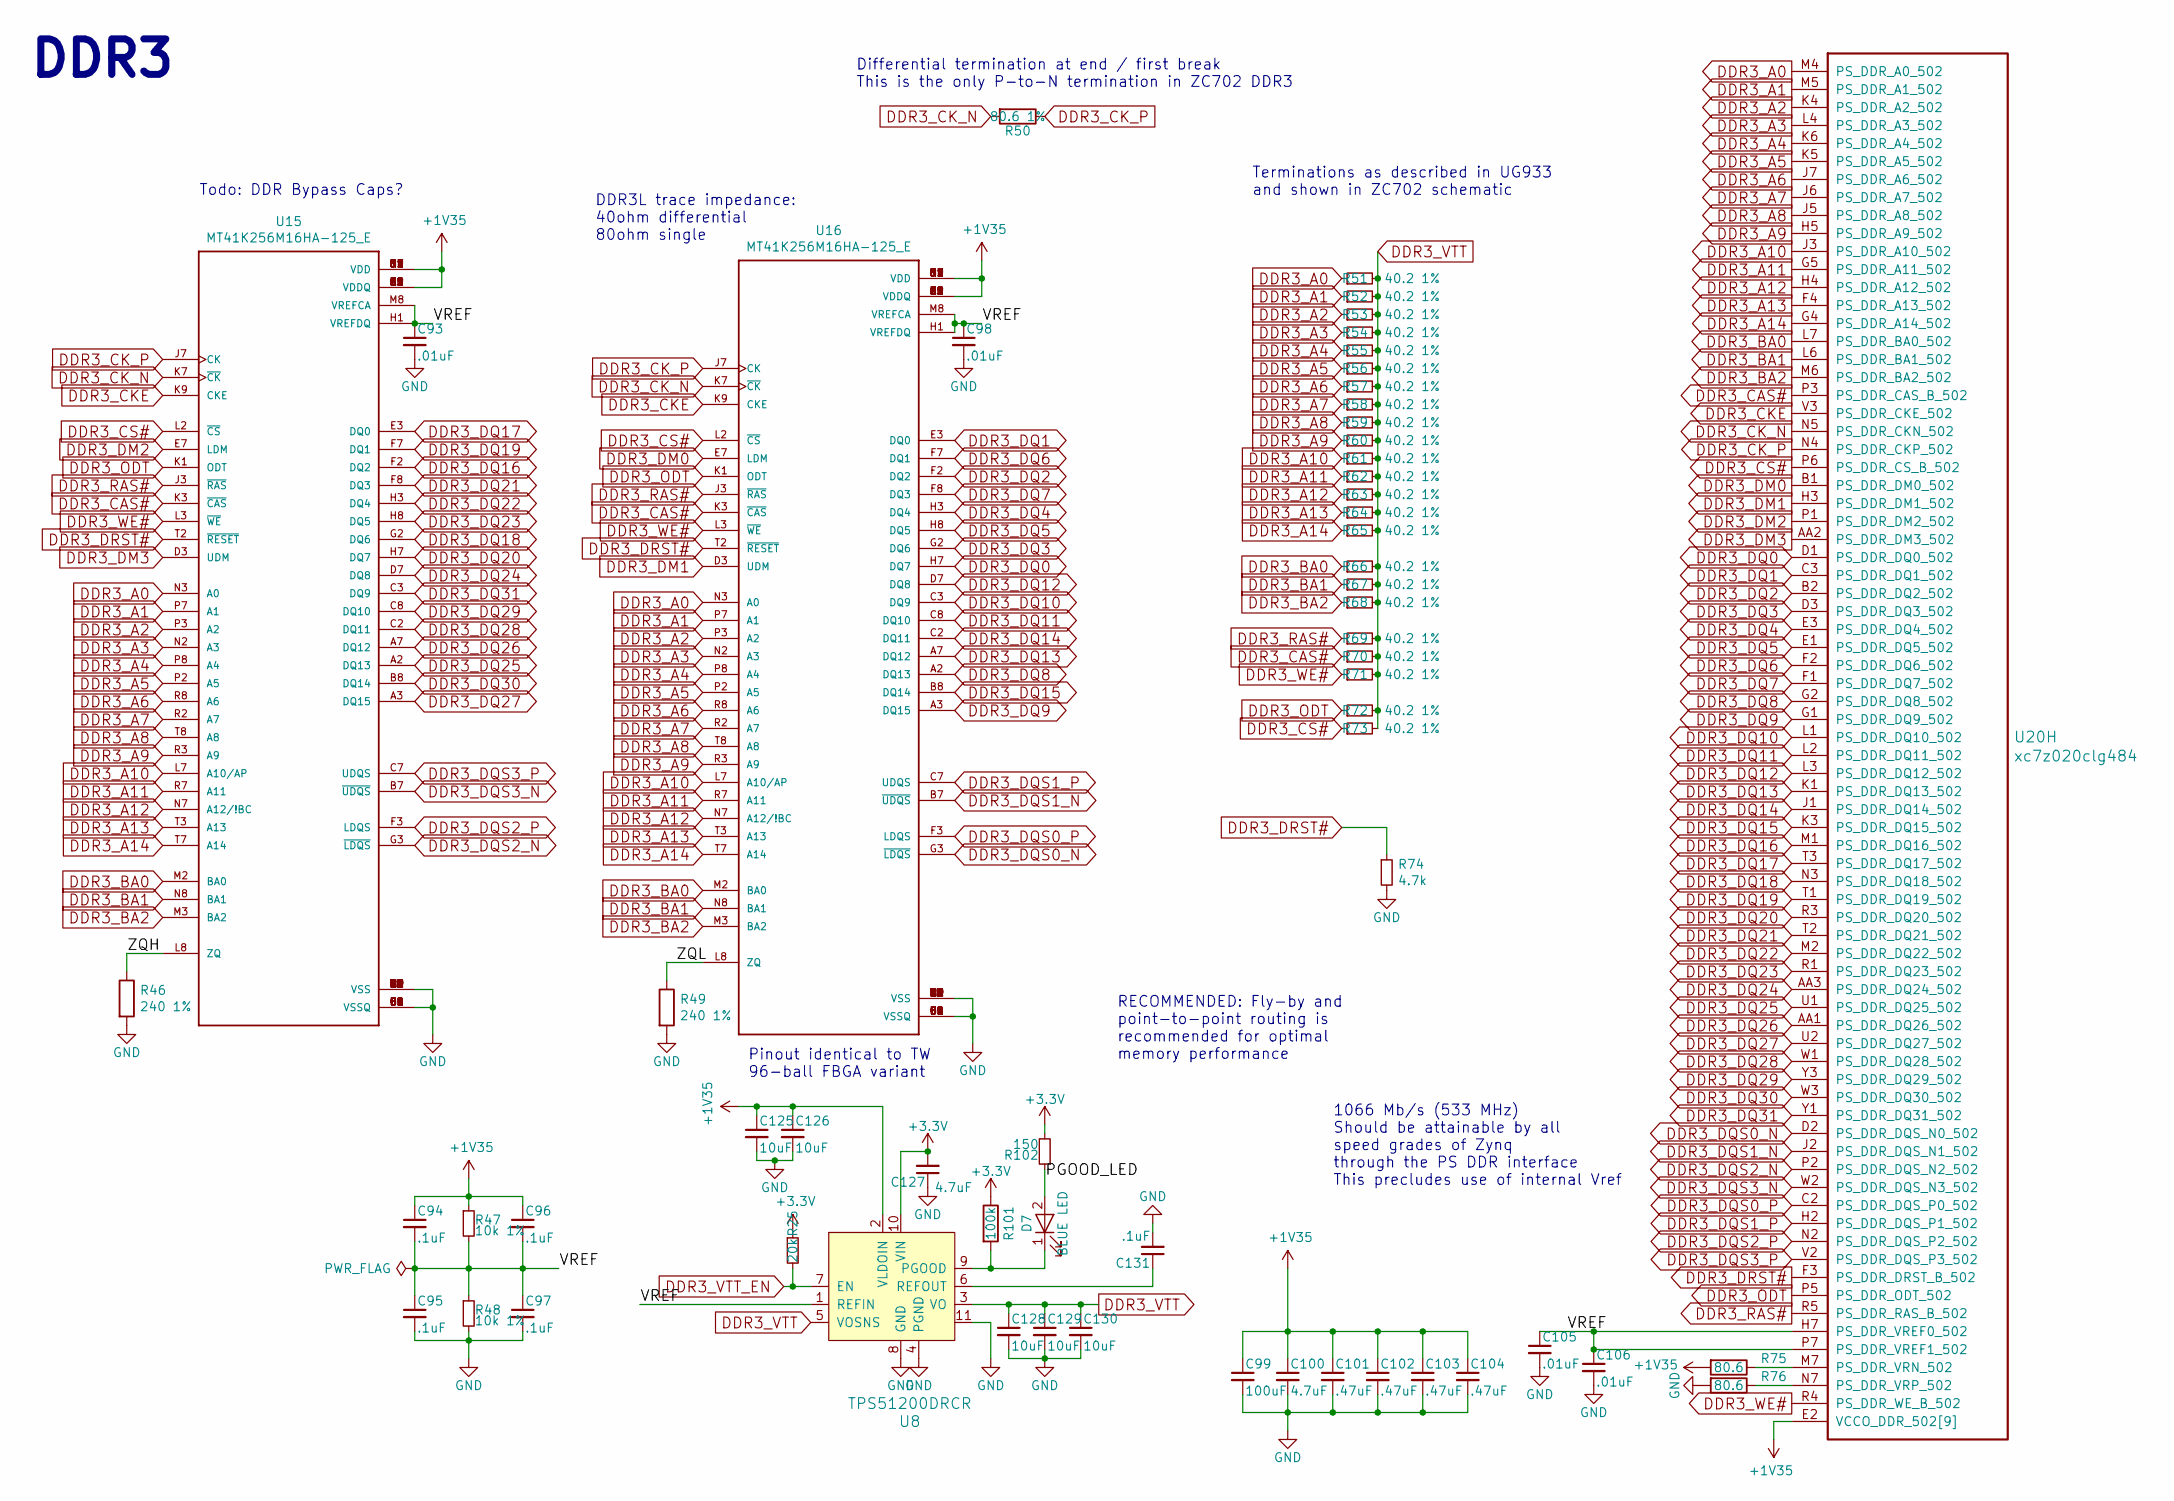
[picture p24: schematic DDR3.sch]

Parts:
C93, C98, C105, C106: .01uF; C_0402_1005Metric
C94, C95, C96, C97, C131: .1uF; C_0402_1005Metric; MPN GRM188R71C104KA01D
C99: 100uF; C_1210_3225Metric; MPN JMK325ABJ107MM-P
C100, C127: 4.7uF; C_0402_1005Metric; MPN GRM21BR61A475KA73L
C101, C102, C103, C104: .47uF; C_0402_1005Metric; MPN GRM188R71C474KA88D
C125, C126, C128, C129, C130: 10uF; C_0603_1608Metric; MPN GRM21BR61A106KE19L
D7: BLUE LED; C_0603_1608Metric; MPN VLMB1300-GS08
R25: 20k; R_0402_1005Metric
R46, R49: 240 1%; R_0402_1005Metric
R47, R48: 10k 1%; R_0402_1005Metric
R50: 80.6 1%; R_0402_1005Metric
R51, R52, R53, R54, R55, R56, R57, R58, R59, R60, R61, R62, R63, R64, R65, R66, R67, R68, R69, R70, R71, R72, R73: 40.2 1%; R_0402_1005Metric
R74: 4.7k; R_0402_1005Metric
R75, R76: 80.6; R_0402_1005Metric
R101: 100k; R_0402_1005Metric; MPN RC0402FR-07100KL
R102: 150; R_0402_1005Metric; MPN RC0402FR-07150RL
U8: TPS51200DRCR; VSON-10-1EP_3x3mm_P0.5mm_EP1.65x2.4mm_ThermalVias; MPN TPS51200DRCR; Digi-Key_PN 296-26978-1-ND
U15, U16: MT41K256M16HA-125_E; FBGA-96-DDR3-SDRAM
U20: xc7z020clg484; BGA-484_19.0x19.0mm_Layout22x22_P0.80mm_dia0.40mm

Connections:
+1V35: C94.1, C96.1, C99.1, C100.1, C101.1, C102.1, C103.1, C104.1, C125.1, C126.1, R47.1, R75.2, U8.2 (VLDOIN), U15.A1 (VDDQ), U15.A8 (VDDQ), U15.B2 (VDD), U15.C1 (VDDQ), U15.C9 (VDDQ), U15.D2 (VDDQ), U15.D9 (VDD), U15.E9 (VDDQ), U15.F1 (VDDQ), U15.G7 (VDD), U15.H2 (VDDQ), U15.H9 (VDDQ), U15.K2 (VDD), U15.K8 (VDD), U15.N1 (VDD), U15.N9 (VDD), U15.R1 (VDD), U15.R9 (VDD), U16.A1 (VDDQ), U16.A8 (VDDQ), U16.B2 (VDD), U16.C1 (VDDQ), U16.C9 (VDDQ), U16.D2 (VDDQ), U16.D9 (VDD), U16.E9 (VDDQ), U16.F1 (VDDQ), U16.G7 (VDD), U16.H2 (VDDQ), U16.H9 (VDDQ), U16.K2 (VDD), U16.K8 (VDD), U16.N1 (VDD), U16.N9 (VDD), U16.R1 (VDD), U16.R9 (VDD), U20.E2 (VCCO_DDR_502[9]), U20.F5 (VCCO_DDR_502[9]), U20.H1 (VCCO_DDR_502[9]), U20.J4 (VCCO_DDR_502[9]), U20.K7 (VCCO_DDR_502[9]), U20.M3 (VCCO_DDR_502[9]), U20.N6 (VCCO_DDR_502[9]), U20.R2 (VCCO_DDR_502[9]), U20.V1 (VCCO_DDR_502[9]); also elsewhere on the board
+3V3: C127.2, R25.1, R101.1, R102.2, U8.10 (VIN); also elsewhere on the board
/DDR3/PGOOD_LED: D7.2 (A), R102.1
/DDR3/VREF: C93.1, C94.2, C95.1, C96.2, C97.1, C98.1, C105.1, C106.1, R47.2, R48.1, U8.1 (REFIN), U15.H1 (VREFDQ), U15.M8 (VREFCA), U16.H1 (VREFDQ), U16.M8 (VREFCA), U20.H7 (PS_DDR_VREF0_502), U20.P7 (PS_DDR_VREF1_502)
/DDR3/ZQH: R46.1, U15.L8 (ZQ)
/DDR3/ZQL: R49.1, U16.L8 (ZQ)
DDR3_A0: R51.1, U15.N3 (A0), U16.N3 (A0), U20.M4 (PS_DDR_A0_502)
DDR3_A1: R52.1, U15.P7 (A1), U16.P7 (A1), U20.M5 (PS_DDR_A1_502)
DDR3_A2: R53.1, U15.P3 (A2), U16.P3 (A2), U20.K4 (PS_DDR_A2_502)
DDR3_A3: R54.1, U15.N2 (A3), U16.N2 (A3), U20.L4 (PS_DDR_A3_502)
DDR3_A4: R55.1, U15.P8 (A4), U16.P8 (A4), U20.K6 (PS_DDR_A4_502)
DDR3_A5: R56.1, U15.P2 (A5), U16.P2 (A5), U20.K5 (PS_DDR_A5_502)
DDR3_A6: R57.1, U15.R8 (A6), U16.R8 (A6), U20.J7 (PS_DDR_A6_502)
DDR3_A7: R58.1, U15.R2 (A7), U16.R2 (A7), U20.J6 (PS_DDR_A7_502)
DDR3_A8: R59.1, U15.T8 (A8), U16.T8 (A8), U20.J5 (PS_DDR_A8_502)
DDR3_A9: R60.1, U15.R3 (A9), U16.R3 (A9), U20.H5 (PS_DDR_A9_502)
DDR3_A10: R61.1, U15.L7 (A10/AP), U16.L7 (A10/AP), U20.J3 (PS_DDR_A10_502)
DDR3_A11: R62.1, U15.R7 (A11), U16.R7 (A11), U20.G5 (PS_DDR_A11_502)
DDR3_A12: R63.1, U15.N7 (A12/!BC), U16.N7 (A12/!BC), U20.H4 (PS_DDR_A12_502)
DDR3_A13: R64.1, U15.T3 (A13), U16.T3 (A13), U20.F4 (PS_DDR_A13_502)
DDR3_A14: R65.1, U15.T7 (A14), U16.T7 (A14), U20.G4 (PS_DDR_A14_502)
DDR3_BA0: R66.1, U15.M2 (BA0), U16.M2 (BA0), U20.L7 (PS_DDR_BA0_502)
DDR3_BA1: R67.1, U15.N8 (BA1), U16.N8 (BA1), U20.L6 (PS_DDR_BA1_502)
DDR3_BA2: R68.1, U15.M3 (BA2), U16.M3 (BA2), U20.M6 (PS_DDR_BA2_502)
DDR3_CAS#: R70.1, U15.K3 (~CAS~), U16.K3 (~CAS~), U20.P3 (PS_DDR_CAS_B_502)
DDR3_CKE: U15.K9 (CKE), U16.K9 (CKE), U20.V3 (PS_DDR_CKE_502)
DDR3_CK_N: R50.2, U15.K7 (~CK~), U16.K7 (~CK~), U20.N5 (PS_DDR_CKN_502)
DDR3_CK_P: R50.1, U15.J7 (CK), U16.J7 (CK), U20.N4 (PS_DDR_CKP_502)
DDR3_CS#: R73.1, U15.L2 (~CS~), U16.L2 (~CS~), U20.P6 (PS_DDR_CS_B_502)
DDR3_DM0: U16.E7 (LDM), U20.B1 (PS_DDR_DM0_502)
DDR3_DM1: U16.D3 (UDM), U20.H3 (PS_DDR_DM1_502)
DDR3_DM2: U15.E7 (LDM), U20.P1 (PS_DDR_DM2_502)
DDR3_DM3: U15.D3 (UDM), U20.AA2 (PS_DDR_DM3_502)
DDR3_DQ0: U16.H7 (DQ7), U20.D1 (PS_DDR_DQ0_502)
DDR3_DQ1: U16.E3 (DQ0), U20.C3 (PS_DDR_DQ1_502)
DDR3_DQ2: U16.F2 (DQ2), U20.B2 (PS_DDR_DQ2_502)
DDR3_DQ3: U16.G2 (DQ6), U20.D3 (PS_DDR_DQ3_502)
DDR3_DQ4: U16.H3 (DQ4), U20.E3 (PS_DDR_DQ4_502)
DDR3_DQ5: U16.H8 (DQ5), U20.E1 (PS_DDR_DQ5_502)
DDR3_DQ6: U16.F7 (DQ1), U20.F2 (PS_DDR_DQ6_502)
DDR3_DQ7: U16.F8 (DQ3), U20.F1 (PS_DDR_DQ7_502)
DDR3_DQ8: U16.A2 (DQ13), U20.G2 (PS_DDR_DQ8_502)
DDR3_DQ9: U16.A3 (DQ15), U20.G1 (PS_DDR_DQ9_502)
DDR3_DQ10: U16.C3 (DQ9), U20.L1 (PS_DDR_DQ10_502)
DDR3_DQ11: U16.C8 (DQ10), U20.L2 (PS_DDR_DQ11_502)
DDR3_DQ12: U16.D7 (DQ8), U20.L3 (PS_DDR_DQ12_502)
DDR3_DQ13: U16.A7 (DQ12), U20.K1 (PS_DDR_DQ13_502)
DDR3_DQ14: U16.C2 (DQ11), U20.J1 (PS_DDR_DQ14_502)
DDR3_DQ15: U16.B8 (DQ14), U20.K3 (PS_DDR_DQ15_502)
DDR3_DQ16: U15.F2 (DQ2), U20.M1 (PS_DDR_DQ16_502)
DDR3_DQ17: U15.E3 (DQ0), U20.T3 (PS_DDR_DQ17_502)
DDR3_DQ18: U15.G2 (DQ6), U20.N3 (PS_DDR_DQ18_502)
DDR3_DQ19: U15.F7 (DQ1), U20.T1 (PS_DDR_DQ19_502)
DDR3_DQ20: U15.H7 (DQ7), U20.R3 (PS_DDR_DQ20_502)
DDR3_DQ21: U15.F8 (DQ3), U20.T2 (PS_DDR_DQ21_502)
DDR3_DQ22: U15.H3 (DQ4), U20.M2 (PS_DDR_DQ22_502)
DDR3_DQ23: U15.H8 (DQ5), U20.R1 (PS_DDR_DQ23_502)
DDR3_DQ24: U15.D7 (DQ8), U20.AA3 (PS_DDR_DQ24_502)
DDR3_DQ25: U15.A2 (DQ13), U20.U1 (PS_DDR_DQ25_502)
DDR3_DQ26: U15.A7 (DQ12), U20.AA1 (PS_DDR_DQ26_502)
DDR3_DQ27: U15.A3 (DQ15), U20.U2 (PS_DDR_DQ27_502)
DDR3_DQ28: U15.C2 (DQ11), U20.W1 (PS_DDR_DQ28_502)
DDR3_DQ29: U15.C8 (DQ10), U20.Y3 (PS_DDR_DQ29_502)
DDR3_DQ30: U15.B8 (DQ14), U20.W3 (PS_DDR_DQ30_502)
DDR3_DQ31: U15.C3 (DQ9), U20.Y1 (PS_DDR_DQ31_502)
DDR3_DQS0_N: U16.G3 (~LDQS~), U20.D2 (PS_DDR_DQS_N0_502)
DDR3_DQS0_P: U16.F3 (LDQS), U20.C2 (PS_DDR_DQS_P0_502)
DDR3_DQS1_N: U16.B7 (~UDQS~), U20.J2 (PS_DDR_DQS_N1_502)
DDR3_DQS1_P: U16.C7 (UDQS), U20.H2 (PS_DDR_DQS_P1_502)
DDR3_DQS2_N: U15.G3 (~LDQS~), U20.P2 (PS_DDR_DQS_N2_502)
DDR3_DQS2_P: U15.F3 (LDQS), U20.N2 (PS_DDR_DQS_P2_502)
DDR3_DQS3_N: U15.B7 (~UDQS~), U20.W2 (PS_DDR_DQS_N3_502)
DDR3_DQS3_P: U15.C7 (UDQS), U20.V2 (PS_DDR_DQS_P3_502)
DDR3_DRST#: R74.1, U15.T2 (~RESET~), U16.T2 (~RESET~), U20.F3 (PS_DDR_DRST_B_502)
DDR3_ODT: R72.1, U15.K1 (ODT), U16.K1 (ODT), U20.P5 (PS_DDR_ODT_502)
DDR3_RAS#: R69.1, U15.J3 (~RAS~), U16.J3 (~RAS~), U20.R5 (PS_DDR_RAS_B_502)
DDR3_VTT: C128.1, C129.1, C130.1, R51.2, R52.2, R53.2, R54.2, R55.2, R56.2, R57.2, R58.2, R59.2, R60.2, R61.2, R62.2, R63.2, R64.2, R65.2, R66.2, R67.2, R68.2, R69.2, R70.2, R71.2, R72.2, R73.2, U8.3 (VO), U8.5 (VOSNS)
DDR3_VTT_EN: R25.2, U8.7 (EN); also elsewhere on the board
DDR3_WE#: R71.1, U15.L3 (~WE~), U16.L3 (~WE~), U20.R4 (PS_DDR_WE_B_502)
unnamed: C131.1, U8.6 (REFOUT)
unnamed: D7.1 (K), R101.2, U8.9 (PGOOD)
unnamed: R75.1, U20.M7 (PS_DDR_VRN_502)
unnamed: R76.1, U20.N7 (PS_DDR_VRP_502)

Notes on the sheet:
Differential termination at end / first break This is the only P-to-N termination in ZC702 DDR3
Terminations as described in UG933 and shown in ZC702 schematic
Pinout identical to TW 96-ball FBGA variant
RECOMMENDED: Fly-by and point-to-point routing is recommended for optimal memory performance
DDR3L trace impedance: 40ohm differential 80ohm single
Todo: DDR Bypass Caps?
1066 Mb/s (533 MHz) Should be attainable by all speed grades of Zynq through the PS DDR interface This precludes use of internal Vref
DDR3

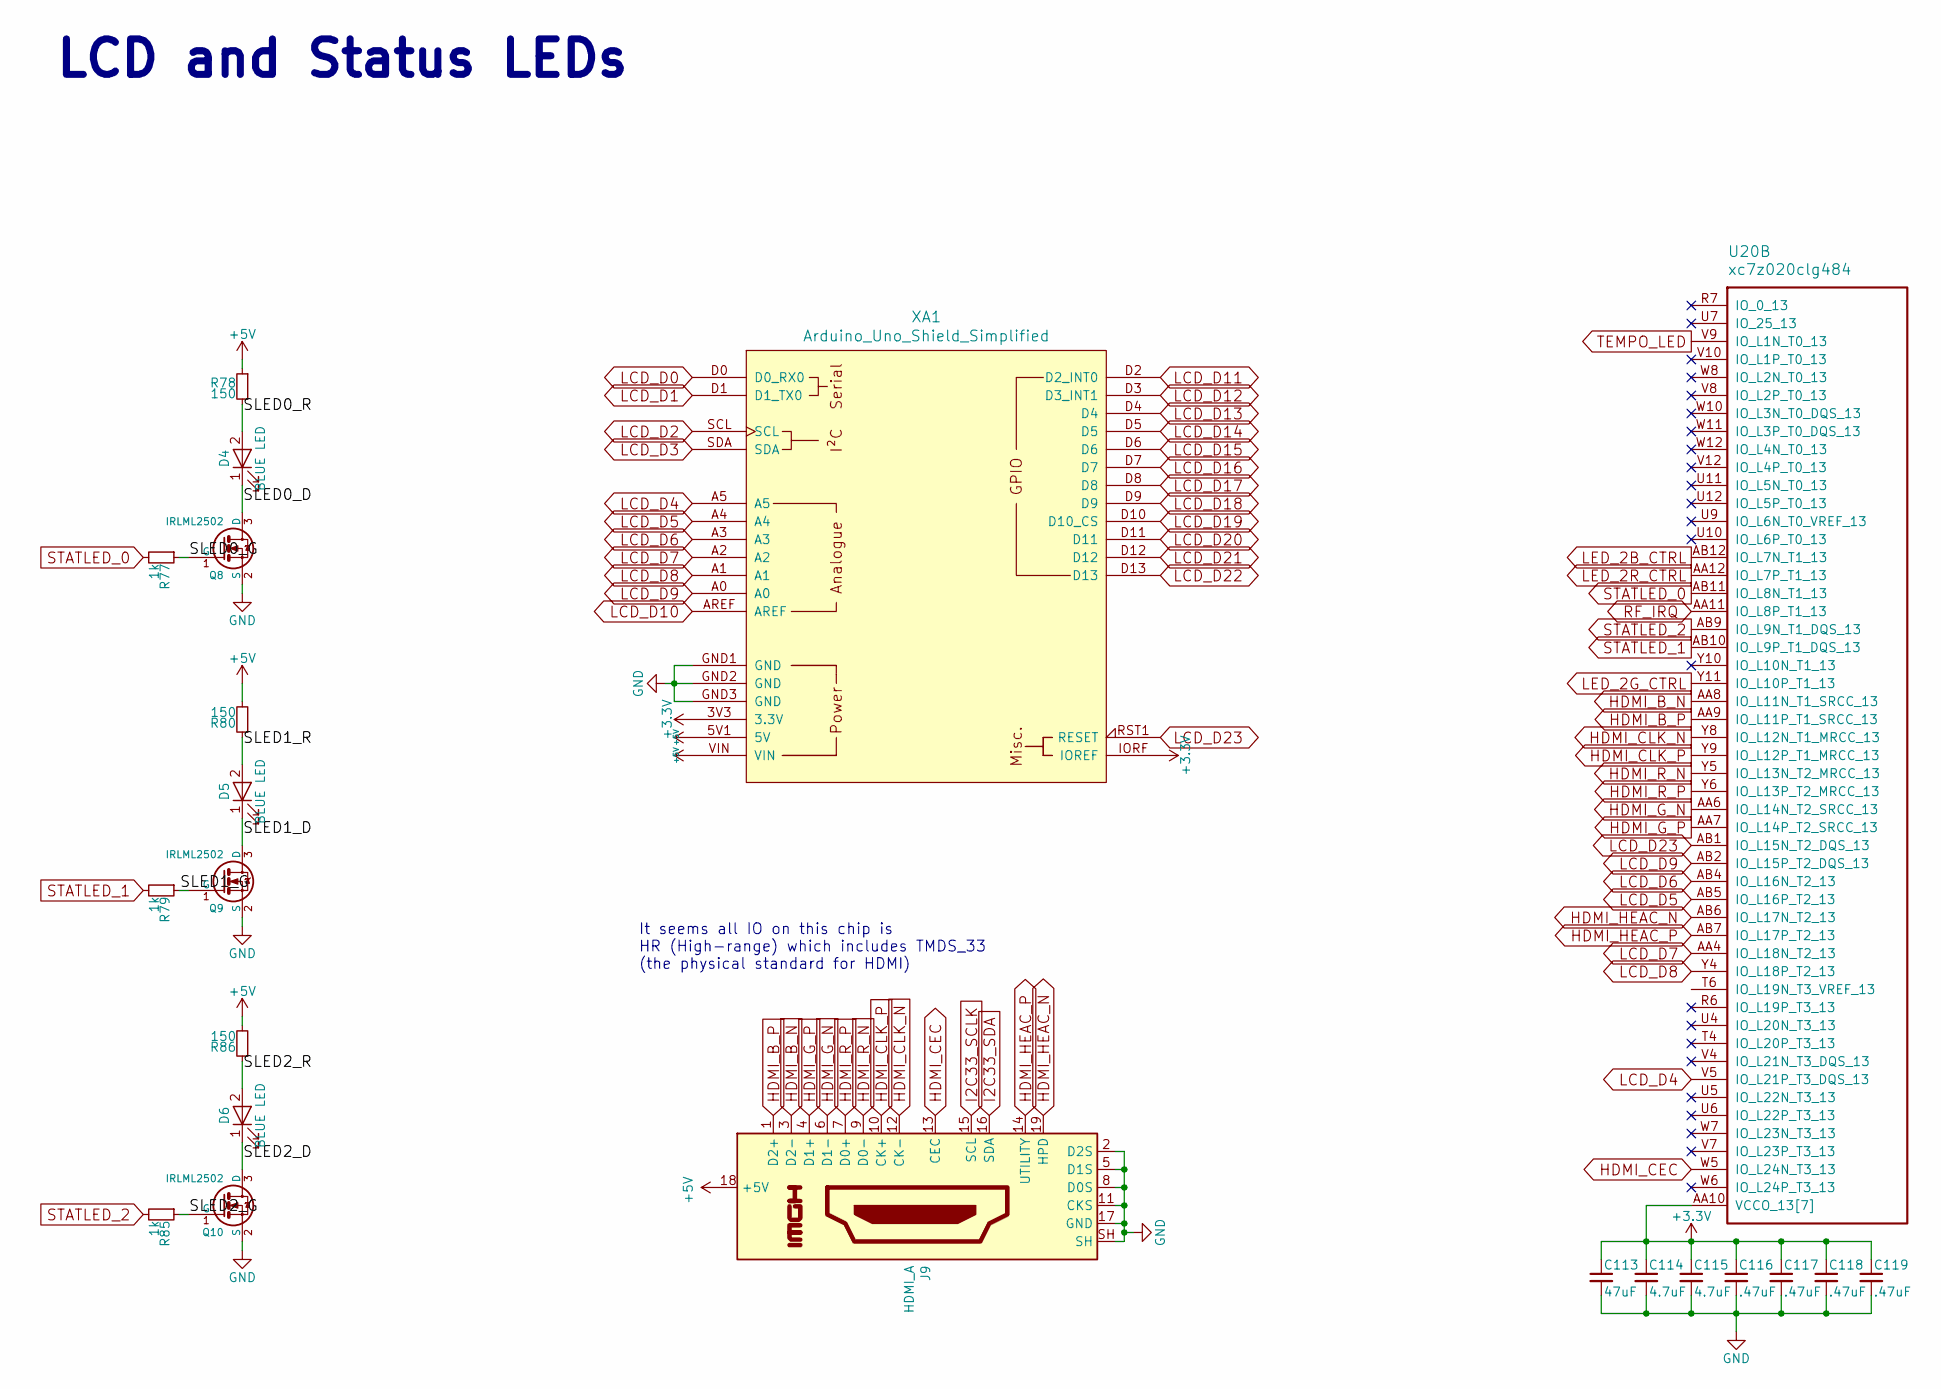
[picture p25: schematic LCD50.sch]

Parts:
C113: 47uF; C_1210_3225Metric; MPN GRM32ER70J476ME20L
C114, C115: 4.7uF; C_0402_1005Metric; MPN GRM21BR61A475KA73L
C116, C117, C118, C119: .47uF; C_0402_1005Metric; MPN GRM188R71C474KA88D
D4, D5, D6: BLUE LED; C_0603_1608Metric; MPN VLMB1300-GS08
J9: HDMI_A; 10029449-111RLF
Q8, Q9, Q10: IRLML2502; SOT-23; MPN IRLML2502TRPBF
R77, R79, R85: 1k; R_0402_1005Metric; MPN RC0402FR-071KL
R78, R80, R86: 150; R_0402_1005Metric; MPN RC0402FR-07150RL
U20: xc7z020clg484; BGA-484_19.0x19.0mm_Layout22x22_P0.80mm_dia0.40mm
XA1: Arduino_Uno_Shield_Simplified

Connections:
+3V3: C113.1, C114.1, C115.1, C116.1, C117.1, C118.1, C119.1, U20.AA10 (VCCO_13[7]), U20.AB3 (VCCO_13[7]), U20.T5 (VCCO_13[7]), U20.U8 (VCCO_13[7]), U20.V11 (VCCO_13[7]), U20.W4 (VCCO_13[7]), U20.Y7 (VCCO_13[7]), XA1.3V3 (3.3V), XA1.IORF (IOREF); also elsewhere on the board
+5V: J9.18 (+5V), R78.1, R80.2, R86.2, XA1.5V1 (5V), XA1.VIN; also elsewhere on the board
/LCD50/SLED0_D: D4.1 (K), Q8.3 (D)
/LCD50/SLED0_G: Q8.1 (G), R77.1
/LCD50/SLED0_R: D4.2 (A), R78.2
/LCD50/SLED1_D: D5.1 (K), Q9.3 (D)
/LCD50/SLED1_G: Q9.1 (G), R79.1
/LCD50/SLED1_R: D5.2 (A), R80.1
/LCD50/SLED2_D: D6.1 (K), Q10.3 (D)
/LCD50/SLED2_G: Q10.1 (G), R85.1
/LCD50/SLED2_R: D6.2 (A), R86.1
HDMI_B_N: J9.3 (D2-), U20.AA8 (IO_L11N_T1_SRCC_13)
HDMI_B_P: J9.1 (D2+), U20.AA9 (IO_L11P_T1_SRCC_13)
HDMI_CEC: J9.13 (CEC), U20.W5 (IO_L24N_T3_13)
HDMI_CLK_N: J9.12 (CK-), U20.Y8 (IO_L12N_T1_MRCC_13)
HDMI_CLK_P: J9.10 (CK+), U20.Y9 (IO_L12P_T1_MRCC_13)
HDMI_G_N: J9.6 (D1-), U20.AA6 (IO_L14N_T2_SRCC_13)
HDMI_G_P: J9.4 (D1+), U20.AA7 (IO_L14P_T2_SRCC_13)
HDMI_HEAC_N: J9.19 (HPD), U20.AB6 (IO_L17N_T2_13)
HDMI_HEAC_P: J9.14 (UTILITY), U20.AB7 (IO_L17P_T2_13)
HDMI_R_N: J9.9 (D0-), U20.Y5 (IO_L13N_T2_MRCC_13)
HDMI_R_P: J9.7 (D0+), U20.Y6 (IO_L13P_T2_MRCC_13)
I2C33_SCLK: J9.15 (SCL); also elsewhere on the board
I2C33_SDA: J9.16 (SDA); also elsewhere on the board
LCD_D0: XA1.D0 (D0_RX0); also elsewhere on the board
LCD_D1: XA1.D1 (D1_TX0); also elsewhere on the board
LCD_D2: XA1.SCL; also elsewhere on the board
LCD_D3: XA1.SDA; also elsewhere on the board
LCD_D4: U20.V5 (IO_L21P_T3_DQS_13), XA1.A5
LCD_D5: U20.AB5 (IO_L16P_T2_13), XA1.A4
LCD_D6: U20.AB4 (IO_L16N_T2_13), XA1.A3
LCD_D7: U20.AA4 (IO_L18N_T2_13), XA1.A2
LCD_D8: U20.Y4 (IO_L18P_T2_13), XA1.A1
LCD_D9: U20.AB2 (IO_L15P_T2_DQS_13), XA1.A0
LCD_D10: XA1.AREF; also elsewhere on the board
LCD_D11: XA1.D2 (D2_INT0); also elsewhere on the board
LCD_D12: XA1.D3 (D3_INT1); also elsewhere on the board
LCD_D13: XA1.D4; also elsewhere on the board
LCD_D14: XA1.D5; also elsewhere on the board
LCD_D15: XA1.D6; also elsewhere on the board
LCD_D16: XA1.D7; also elsewhere on the board
LCD_D17: XA1.D8; also elsewhere on the board
LCD_D18: XA1.D9; also elsewhere on the board
LCD_D19: XA1.D10 (D10_CS); also elsewhere on the board
LCD_D20: XA1.D11; also elsewhere on the board
LCD_D21: XA1.D12; also elsewhere on the board
LCD_D22: XA1.D13; also elsewhere on the board
LCD_D23: U20.AB1 (IO_L15N_T2_DQS_13), XA1.RST1 (RESET)
LED_2B_CTRL: U20.AB12 (IO_L7N_T1_13); also elsewhere on the board
LED_2G_CTRL: U20.Y11 (IO_L10P_T1_13); also elsewhere on the board
LED_2R_CTRL: U20.AA12 (IO_L7P_T1_13); also elsewhere on the board
RF_IRQ: U20.AA11 (IO_L8P_T1_13); also elsewhere on the board
STATLED_0: R77.2, U20.AB11 (IO_L8N_T1_13)
STATLED_1: R79.2, U20.AB10 (IO_L9P_T1_DQS_13)
STATLED_2: R85.2, U20.AB9 (IO_L9N_T1_DQS_13)
TEMPO_LED: U20.V9 (IO_L1N_T0_13); also elsewhere on the board

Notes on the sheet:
LCD and Status LEDs
It seems all IO on this chip is HR (High-range) which includes TMDS_33 (the physical standard for HDMI)

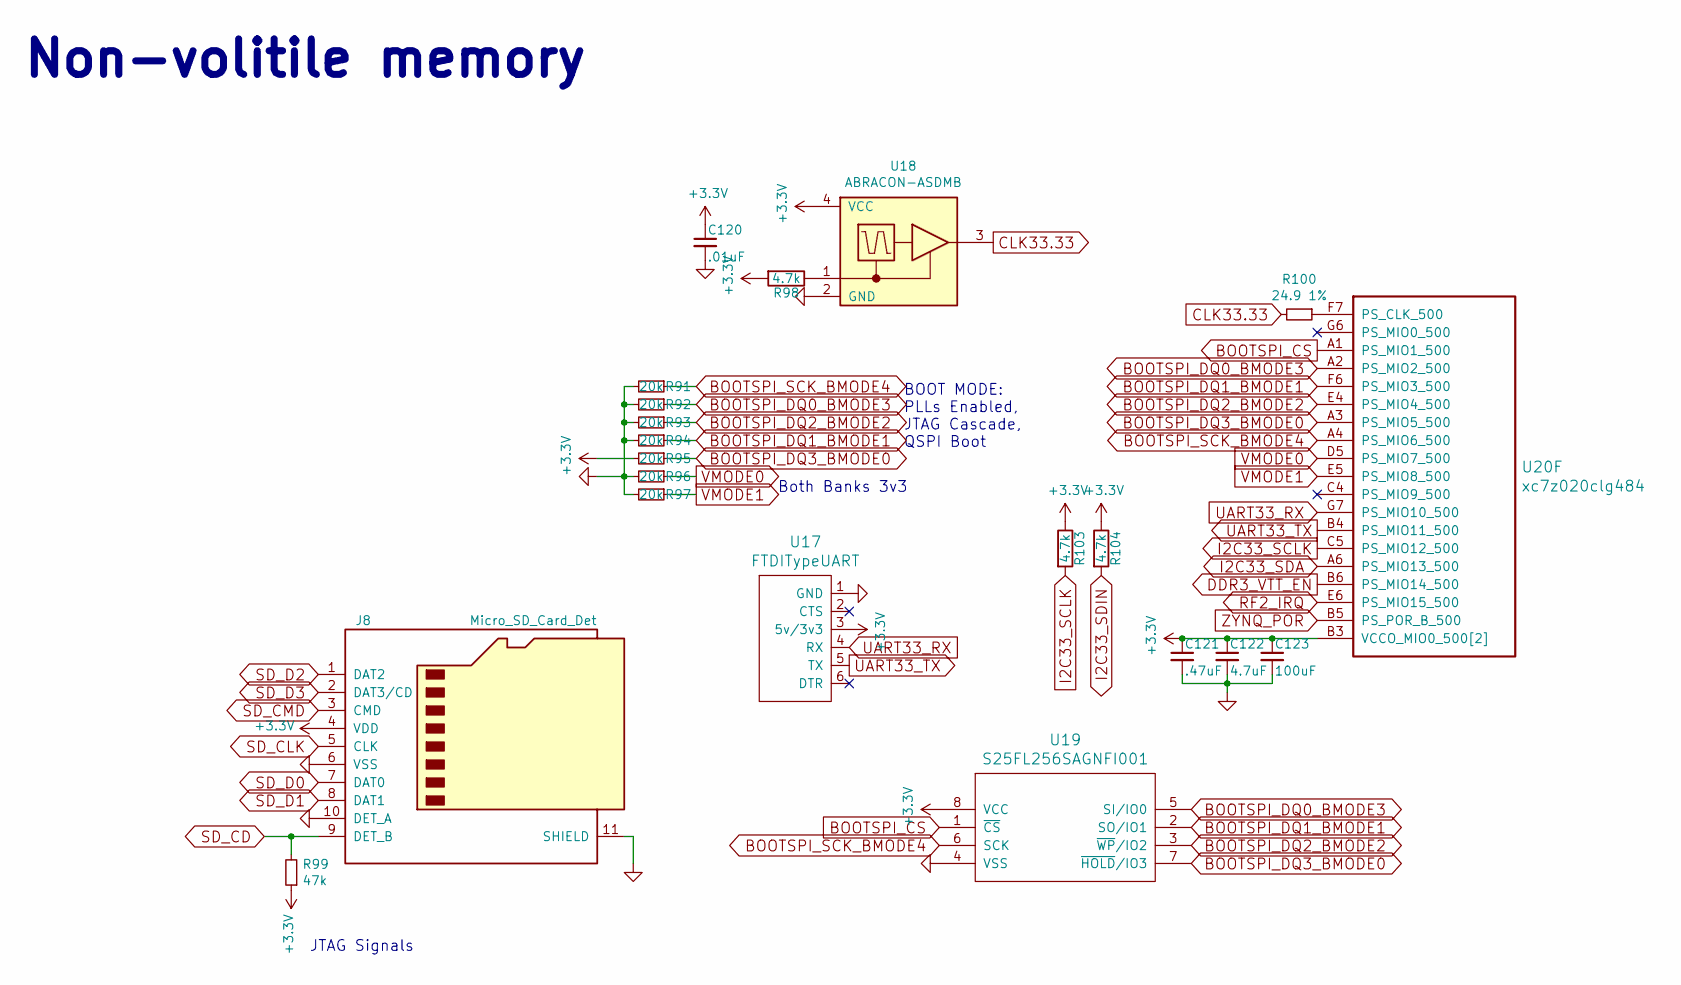
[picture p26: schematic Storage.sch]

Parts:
C120: .01uF; C_0402_1005Metric
C121: .47uF; C_0402_1005Metric; MPN GRM188R71C474KA88D
C122: 4.7uF; C_0402_1005Metric; MPN GRM21BR61A475KA73L
C123: 100uF; C_1210_3225Metric; MPN JMK325ABJ107MM-P
J8: Micro_SD_Card_Det; AMPHENOL-114-00841-68
R91, R92, R93, R94, R95, R96, R97: 20k; R_0402_1005Metric
R98, R103, R104: 4.7k; R_0402_1005Metric; MPN RC0402FR-074K7L
R99: 47k; R_0402_1005Metric
R100: 24.9 1%; R_0402_1005Metric
U17: FTDITypeUART; FTDI_CONN
U18: ABRACON-ASDMB; XTAL_ASDMB-24.000MHZ-LC-T; MPN ASDMB-{freq}MHZ-{temp}{stab}-{load}-{pk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
U19: S25FL256SAGNFI001; WSON-8
U20: xc7z020clg484; BGA-484_19.0x19.0mm_Layout22x22_P0.80mm_dia0.40mm

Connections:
+3V3: C120.1, C121.1, C122.1, C123.1, J8.4 (VDD), R95.2, R98.2, R99.1, R103.1, R104.1, U17.3 (5v/3v3), U18.4 (VCC), U19.8 (VCC), U20.B3 (VCCO_MIO0_500[2]), U20.C6 (VCCO_MIO0_500[2]); also elsewhere on the board
BOOTSPI_CS: U19.1 (~CS), U20.A1 (PS_MIO1_500)
BOOTSPI_DQ0_BMODE3: R92.1, U19.5 (SI/IO0), U20.A2 (PS_MIO2_500)
BOOTSPI_DQ1_BMODE1: R94.1, U19.2 (SO/IO1), U20.F6 (PS_MIO3_500)
BOOTSPI_DQ2_BMODE2: R93.1, U19.3 (~WP~/IO2), U20.E4 (PS_MIO4_500)
BOOTSPI_DQ3_BMODE0: R95.1, U19.7 (~HOLD~/IO3), U20.A3 (PS_MIO5_500)
BOOTSPI_SCK_BMODE4: R91.1, U19.6 (SCK), U20.A4 (PS_MIO6_500)
CLK33.33: R100.2, U18.3 (OUT)
DDR3_VTT_EN: U20.B6 (PS_MIO14_500); also elsewhere on the board
I2C33_SCLK: R103.2, U20.C5 (PS_MIO12_500); also elsewhere on the board
I2C33_SDA: U20.A6 (PS_MIO13_500); also elsewhere on the board
I2C33_SDIN: R104.2; also elsewhere on the board
unnamed: R98.1, U18.1 (OE)
unnamed: R100.1, U20.F7 (PS_CLK_500)
RF2_IRQ: U20.E6 (PS_MIO15_500); also elsewhere on the board
SD_CD: J8.9 (DET_B), R99.2; also elsewhere on the board
SD_CLK: J8.5 (CLK); also elsewhere on the board
SD_CMD: J8.3 (CMD); also elsewhere on the board
SD_D0: J8.7 (DAT0); also elsewhere on the board
SD_D1: J8.8 (DAT1); also elsewhere on the board
SD_D2: J8.1 (DAT2); also elsewhere on the board
SD_D3: J8.2 (DAT3/CD); also elsewhere on the board
UART33_RX: U17.4 (RX), U20.G7 (PS_MIO10_500)
UART33_TX: U17.5 (TX), U20.B4 (PS_MIO11_500)
VMODE0: R96.1, U20.D5 (PS_MIO7_500)
VMODE1: R97.1, U20.E5 (PS_MIO8_500)
ZYNQ_POR: U20.B5 (PS_POR_B_500); also elsewhere on the board

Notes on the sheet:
JTAG Signals
Both Banks 3v3
BOOT MODE: PLLs Enabled, JTAG Cascade, QSPI Boot
Non-volitile memory

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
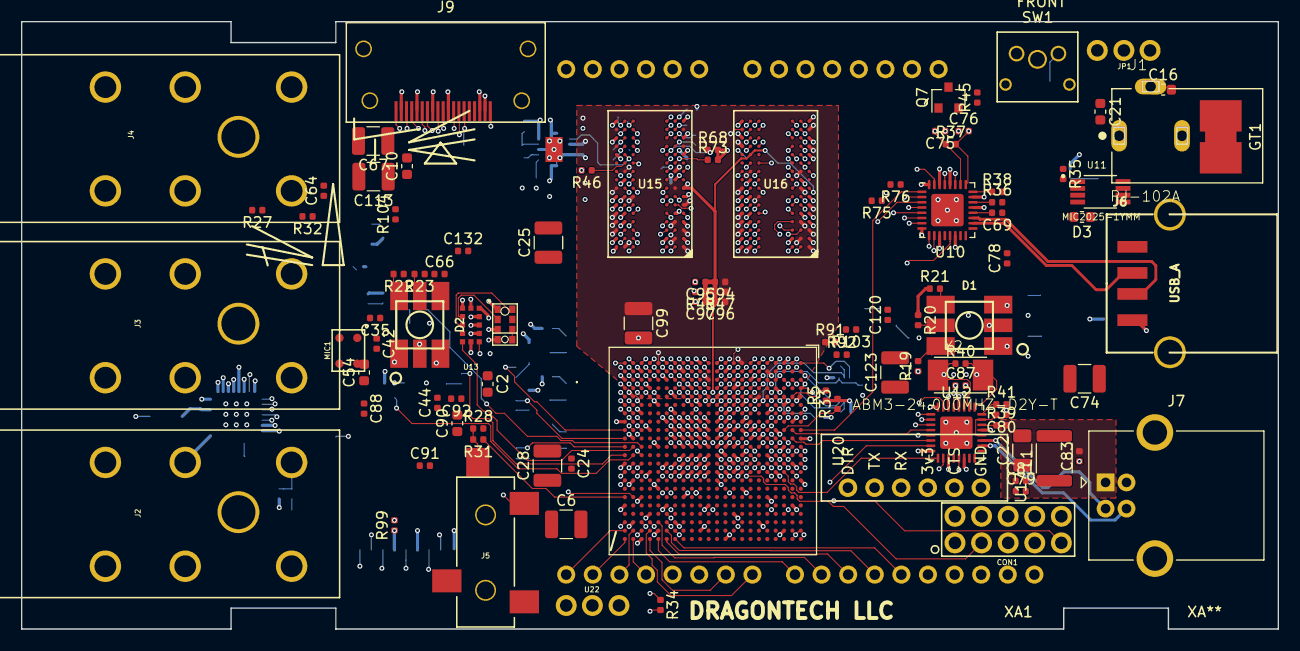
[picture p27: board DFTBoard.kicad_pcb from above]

Board: 8 copper layers, 120.0 x 58.0 mm, 287 parts (0 on the bottom side), 295 nets.

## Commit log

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2016-12-13 finished LED driver lib, added to LED page
    [DFTBoard.sch, file58508443.sch, file5850844C.sch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]
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2016-12-22 near completion of GPIF II interface. placement of all FPGA components
    [Audio.sch, Configuration.sch, CypressFX3.sch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]
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2016-12-29 added HDMI, moved rotary encoders to USBSPI gpio
    [Audio.sch, Configuration.sch, CypressFX3.sch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]
2016-12-29 added LED connections for LCD, created new SPI symbol
    [Audio.sch, Configuration.sch, CypressFX3.sch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]
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2016-12-31 a few changes persuant to FX3 PCB design recommendations
    [Audio.sch, Configuration.sch, CypressFX3.sch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]
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2017-01-03 changed jack detection pull up voltage to 3.3v
    [Audio.sch]
2017-01-03 connected out3 from audio chip to audio in of led chip
    [Audio.sch]
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2017-01-03 added I2S FPGA interface, finished most GPIO connections
    [Audio.sch, Configuration.sch, CypressFX3.sch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]
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2017-01-03 fixed annotations
    [Encoders.sch]
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2017-01-03 fixing some ERC errors
    [CypressFX3.sch, Encoders.sch, gpif2.sch]
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2017-01-03 fixed encoder annotations
    [Encoders.sch]
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2017-01-09 resolved ERC errors, and began assigning footprints
    [Audio.sch, Configuration.sch, CypressFX3.sch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]
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2017-01-10 edited init_b and done LED circuits for FPGA config section
    [Configuration.sch, _saved_rangefinder.sch]
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2017-01-10 restored new LED circuits in FPGA config section
    [Configuration.sch]
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2017-01-12 fixed a few diagram/footprint pin mismatches, getting ready to pull gene's microhdmi footprint
    [Audio.sch, Configuration.sch, CypressFX3.sch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]
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2017-01-12 fixing errors between footprints and schematics
    [SPI_USB_Bridge.sch, hdmi.sch]
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2017-01-12 fixed all schematic/footprint errors
    [Audio.sch, Configuration.sch, CypressFX3.sch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]
2017-01-17 started PCBnew trivial connections and BGA interface, shuffled some net connections, etc.
    [Audio.sch, Configuration.sch, CypressFX3.sch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]
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2017-01-19 added pull down resistor to jack 5v, reannotated
    [Encoders.sch, SPI_USB_Bridge.sch, hdmi.sch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]
2017-01-19 fixed diode polarity
    [Audio.sch, Configuration.sch, CypressFX3.sch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]
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2017-01-19 fixed merge errors
    [FPGA_POWER.sch, power.sch]
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2017-01-23 more moving around components and connecting. all cypress and FPGA bypass caps placed
    [Audio.sch, Configuration.sch, CypressFX3.sch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]
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2017-01-26 changed USB downstream ports to a single stacked receptacle
    [Audio.sch, Configuration.sch, CypressFX3.sch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]
2017-01-26 finished a quarter to a third of non-priority connections
    [Audio.sch, DFTBoard.kicad_pcb, Encoders.sch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]
2017-01-26 more trivial connections and placements. swapped micro-hdmi for standard hdmi recepticle
    [Audio.sch, Configuration.sch, CypressFX3.sch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]
2017-01-30 finished most non-priority connections and placed power/gnd planes
    [Audio.sch, Configuration.sch, CypressFX3.sch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]
2017-01-30 all non-power wires connected and satisfactory. all that remains is a rework of power distribution
    [Encoders.sch, RAM.sch, SPI_USB_Bridge.sch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]
2017-01-30 everything tolerable except some questionable filled areas on bottom layer. still need to revise ground tie
    [power.sch]
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2017-02-02 changed led driver footprint, added the appropriate amount of clearence for audio jacks, redid all those connections, etc, etc
    [Audio.sch, Configuration.sch, CypressFX3.sch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]
2017-02-02 completed BOM, changed footprints and values of identical components (ex. 100nf -> .1uF), have yet to update PCBNEW to reflect footprint changes
    [Audio.sch, Configuration.sch, CypressFX3.sch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]
2017-02-02 fixed PCB to reflect footprint changes
    [DFTBoard-1.8V.gbr, DFTBoard-3.3V.gbr, DFTBoard-5V.gbr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]
2017-02-02 fixed potentially debilitating pin mismatch on FX3 crystal, changed SSRX lines to be on SIG1
    [Audio.sch, Configuration.sch, CypressFX3.sch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]
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2017-02-03 fixed edge.cuts and mounting holes
    [DFTBoard.xlsx, DFTBoardBOM.xlsx]
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2017-02-08 rotated codec such that fewer digital/analog crossings occur
    [DFTBoardBOM.xlsx, DFTBoardBOM_seeedosl.xlsx]
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2017-02-10 thickened USB sig traces, centered footprints, and other small changes
    [Audio.sch, Configuration.sch, CypressFX3.sch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]
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2017-02-14 moved USB traces further from recept. pins, completed BOM with Bitelle Free Passives
    [DFTBoard-1.8V.gbr, DFTBoard-3.3V.gbr, DFTBoard-5V.gbr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]
2017-02-16 updated crystals to higher drive level and moved audio codec to right
    [Audio.sch, BOM_42865A1_VK_0215_DFTresponse.xlsx, BOM_sierra021617afternoon.xlsx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]
2017-02-17 swapped 0201s for 0402 packages, currently reworking PDS so that 3.3V and 1.8V layers can be eliminated
    [Audio.sch, BOM_Bittele_DFTresponse.xlsx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]
2017-02-17 3.3V and 1.8V layers can now be deleted. Just need to figure out how... have a wonderful weekend all
    [DFTBoard.kicad_pcb]
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2017-02-20 some small fixes
    [Audio.sch, BOM022017evening.xlsx, BOM_Bittele_DFTresponse.xlsx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]
2017-02-21 changed via and trace widths to make this a 4mil/4mil board. moved more caps onto back of FPGA. added hardware for doubling line input as pedal input
    [BOM022017evening.xlsx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]
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2017-03-06 some very minor fixes
    [Audio.sch, BOM022317_morning.xlsx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]
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2017-03-28 fixed tps22 land pattern issue. perhaps some other small fixes
    [Audio.sch, CypressFX3.sch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]
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2017-03-28 swapped pins 3 and 4 of crystal
    [Audio.sch, CypressFX3.sch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]
2017-05-03 relocation of components for second prototype run, replacement of LCD with 50-pin ZIF connector for ILI9341
    [Audio.sch, Configuration.sch, CypressFX3.sch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]
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2017-08-11 same as before but without unconnected or DRC errors
    [Encoders.sch, OSC_and_LEDs.sch, _saved_OSC_and_LEDs.sch]
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2017-08-30 about to revert this commit
    [OSC_and_LEDs.sch, RAM.sch]
2017-08-30 Revert "about to revert this commit"
    This reverts commit fbbdb85fc73c11d2768e9943d86ff1ed088b3123.
    [OSC_and_LEDs.sch, RAM.sch]
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2017-12-14 about to sed replace all grounds with GND
    [Audio.sch, Configuration.sch, CypressFX3.sch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]
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2018-01-05 about to remove 2.4ghz radio, which complicates compliance and is redundant to MIDI over BLE over USB
    [Audio.sch, CC2500.sch, Configuration.sch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]
2018-01-20 about to muntz out a) IR receiver b) 2.4Ghz receiver c) USB hub
    [081217_BOM_TMP.csv]
2018-01-29 about to a) add back SDRAM b) reorganize parts/ reroute all traces
    [Audio.sch, Configuration.sch, CypressFX3.sch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]
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2018-03-05 SD interface is verified and length-matched. about to increase annular ring size
    [Audio.sch, Configuration.sch, CypressFX3.sch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]
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2019-09-22 DDR: data lines are set, address lines are f'd. gonna try routing from the right
    [DFTBoard.kicad_pcb]
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2019-09-24 finished DDR pinswaps, about to reposition chips closer to each other, and closer to the FPGA
    [DDR3.sch, DFTBoard.kicad_pcb]
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2019-10-12 widened serpentine routing consistant with guidelines (3x trace-to-plane) need to do data byte 2 and all address lines
    [DDR3.sch, DFTBoard.kicad_pcb, LCD50.sch]
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2019-10-15 about to remove ZIF screen connector in favor of UNO + RPI
    [Audio.sch, DDR3.sch, LCD50.sch]
2019-10-15 added arduino header, shifted components, deleted 50pin ZIF, deleted MIDI in for fear of confusion with headphone jack
    [Audio.sch, DFTBoard.kicad_pcb, LCD50.sch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]
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2019-11-06 routed a few things, about to remove power jack and 5V regulator
    [Audio.sch, DDR3.sch, DFTBoard.kicad_pcb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]
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2019-11-13 DRC passes with only GNDTIE errors. no unconnected. power plane quality unknown
    [Audio.sch, LCD50.sch, USB.sch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]
2019-11-16 moved power to proper buried layers, about to swap layers to match 08J
    [LCD50.sch, power.sch]
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2019-11-29 length matched important interfaces, added current sense resistors to regulators, about to shrink silkscreen designators
    [Audio.sch, DDR3.sch, DFTBoard.sch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]
2019-12-04 finished review with gerber output. still need to relocate rangefinders / LEDs
    [Audio.sch, DDR3.sch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]
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2019-12-24 replaced mems mic and changed pour clearance to 5mil. caused many disconnects
    [Audio.sch]
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2021-02-21 somehow the zones got messed up. fixing them
    [Audio.sch, DDR3.sch, DFTBoard.sch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]
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

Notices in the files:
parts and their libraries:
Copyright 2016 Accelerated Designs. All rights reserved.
